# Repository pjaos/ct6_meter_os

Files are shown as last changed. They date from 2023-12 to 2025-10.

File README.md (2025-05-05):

# CT6 Meter Project
For this project I developed the hardware to allow the measurement of household AC electrical energy usage on up to 6 circuits using current transformers (CT’s). It can be used to monitor solar system generation, storage battery charge/discharge, EV charging, household energy usage, etc...

Multiple CT6 devices can be used to monitor more circuits if required.

Each CT6 unit has 6 ports, each of which can be connected to a current transformer, clipped around a cable carrying AC mains power. Each port can measure the AC power flow bi directionally (I.E to and from the grid). The unit measures the active power (the power normally charged by a domestic electricity supplier), reactive and apparent power. The AC power factor, frequency and AC voltage is also measured along with the WiFi RSSI and CT6 device temperature.

## The CT6 hardware.

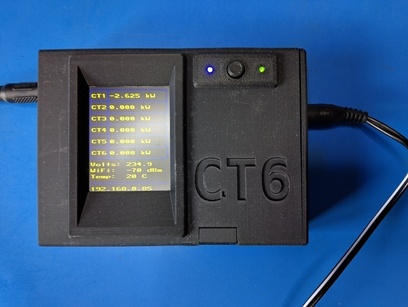
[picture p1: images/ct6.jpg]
CT6 Unit


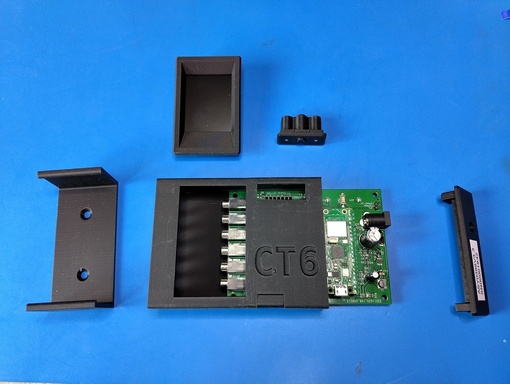
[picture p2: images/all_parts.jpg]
CT6 Parts


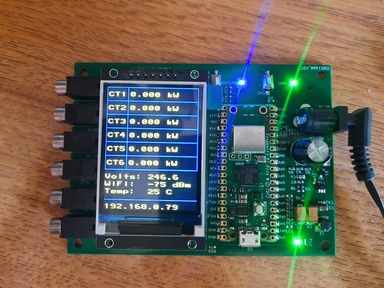
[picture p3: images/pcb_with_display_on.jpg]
CT6 PCB With Display Power On


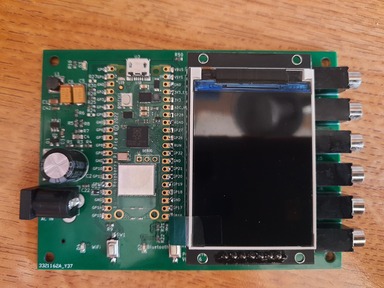
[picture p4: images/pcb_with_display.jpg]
CT6 PCB With Display Power Off


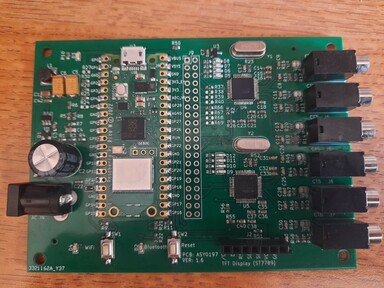
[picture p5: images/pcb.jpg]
CT6 PCB


### CT6 Hardware details
More details of the CT6 hardware can be found [here](hardware/README.md).

## Installing CT6 Software Applications
Details of how to install the CT6 software package onto a Windows or Linux machine can be found [here](software/server/installers/README.md).

## The CT6 Software Applications
An overview of the CT6 software applications are shown below. These can all be started from a terminal window on the command line by entering the name of each command.

- ct6_configurator

The ct6 configurator app allows the user to setup/configure a CT6 unit via a GUI interface. This includes connecting it to your WiFi, upgrading it to the latest firmware. Click [here](software/server/setting_up_ct6_units.md).

- ct6_app

When at least one CT6 device is connected to your WiFi network you can start this app (enter ct6_app in a terminal window). This app will find all CT6 units. These CT6 units will send data to the ct6_app which then stores it in an sqlite database. A server is then started and a browser window will open, connected to the server, to display the data from the database as shown.

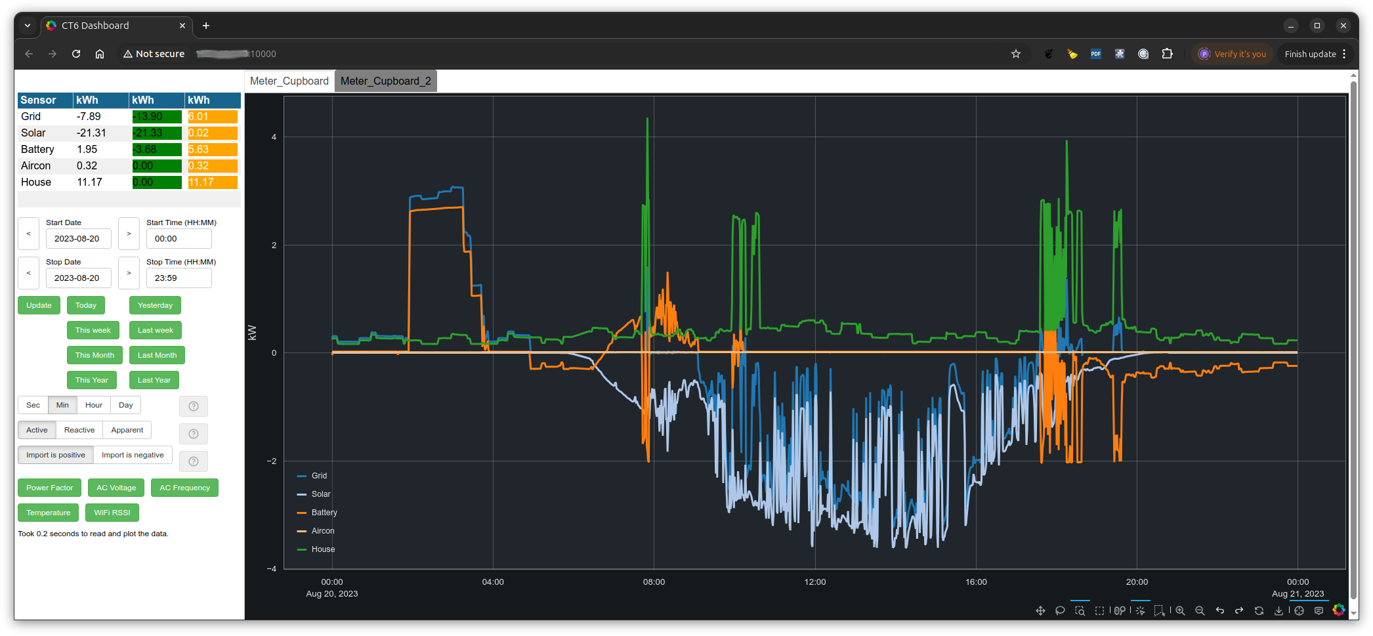
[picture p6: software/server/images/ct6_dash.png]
ct6_dash


- ct6_db_store

Similar to part of the ct6_app in that it detects all CT6 units on the LAN/WiFi and stores the data in a database. However the database is a mysql database. This allows for a more scalable system than the ct6_app. Details of how to use this app can be found [here](software/server/mode_1_mysql_db_and_dashboard.md).

- ct6_dash

This presents the data stored in the above mysql database and presents a GUI in a web browser as displayed above.  Details of how to use this app can be found [here](software/server/mode_1_mysql_db_and_dashboard.md).

- ct6_dash_mgr

Both the ct6_app and the ct6_dash app present a GUI in a browser interface via a local web server. This app allows you to configure credentials (username/password) to allow access to the web server. The ct6_app and ct6_dash apps must be configured to require a login in order to use these credentials. The example below shows auser being added for web server access.

```
ct6_dash_mgr
INFO:
INFO:  ------------
INFO:  | USERNAME |
INFO:  ------------
INFO:  0 credentials stored in /home/pja/.ct6_dash_credentials.json
INFO:
INFO:  A - Add a username/password.
INFO:  D - Delete a username/password.
INFO:  C - Check a username/password is stored.
INFO:  Q - Quit.
INPUT: Enter one of the above options: : a
INFO:  Add a username/password
INPUT: Enter the username: : auser
INPUT: Enter the password: : apassword
INFO:
INFO:  ------------
INFO:  | USERNAME |
INFO:  ------------
INFO:  |    auser |
INFO:  ------------
INFO:  1 credentials stored in /home/pja/.ct6_dash_credentials.json
INFO:
INFO:  A - Add a username/password.
INFO:  D - Delete a username/password.
INFO:  C - Check a username/password is stored.
INFO:  Q - Quit.
INPUT: Enter one of the above options: : q
```

- ct6_mfg_tool

This tool is used to load SW and perform manufacturing tests on CT6 hardware in order to commission them.

- ct6_stats

This finds CT6 devices on the LAN/WiFi and displays the JSON data received from CT6 devices.

- ct6_tool

This provides functionality that is useful when checking the operation of CT6 units in a development environment.

More details of how to use the installed software applications can be found [here](software/server/README.md).

# Home Assistant integration
Click [here](software/server/homeassistant_README.md) for details of how to use CT6 devices with homeassistant.

# Purchasing CT6 units
Complete CT6 units or assembled PCB's and associated parts can be purchased [here](https://www.tindie.com/products/pausten/ct6-energy-monitor/) on Tindie.

If you wish to purchase the PCB and assemble it the PCB is available [here](https://www.ebay.co.uk/itm/197238433051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) on ebay and the Bill of materials (BOM) is available [here](hardware/ct_meter_2.1_bom.csv).

# Warning
This project is designed to use the YHDC SCT013 100A 0-1V split core current transformer. As mains voltage is dangerous it is the users responsibility to connect these current clamps safely using this hardware.

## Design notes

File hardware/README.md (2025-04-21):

# CT6 Hardware

## Schematic

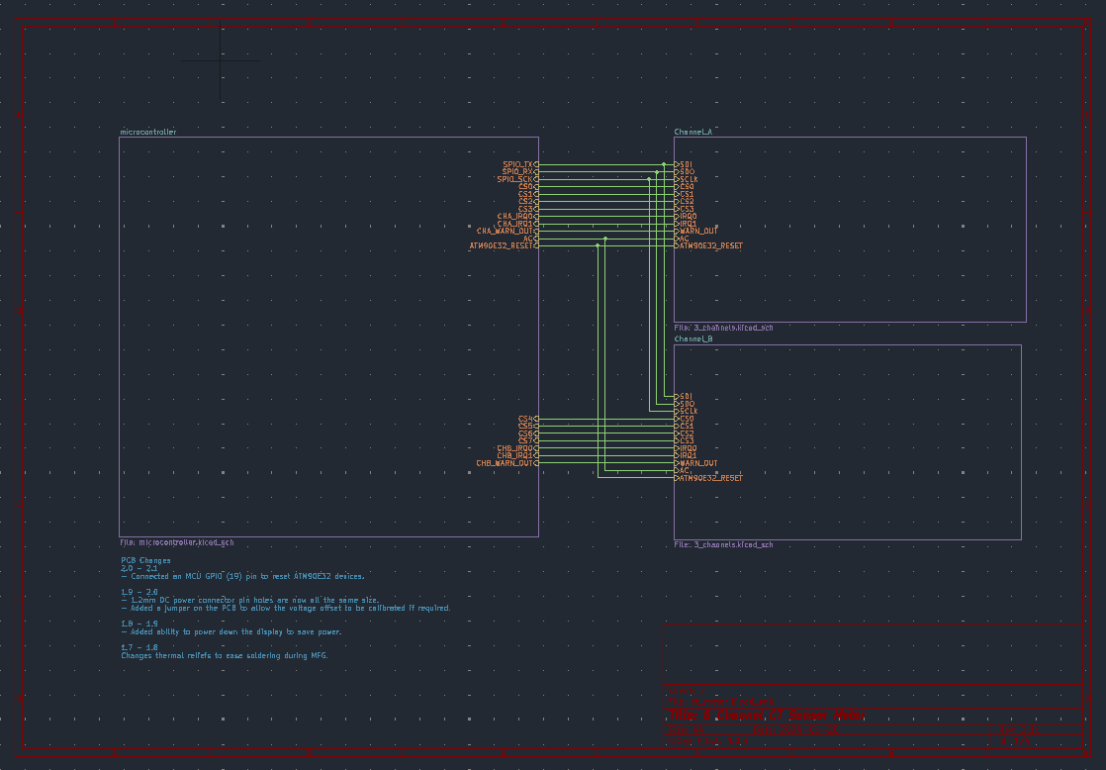
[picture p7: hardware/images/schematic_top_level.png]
CT6 Top Level Schematic


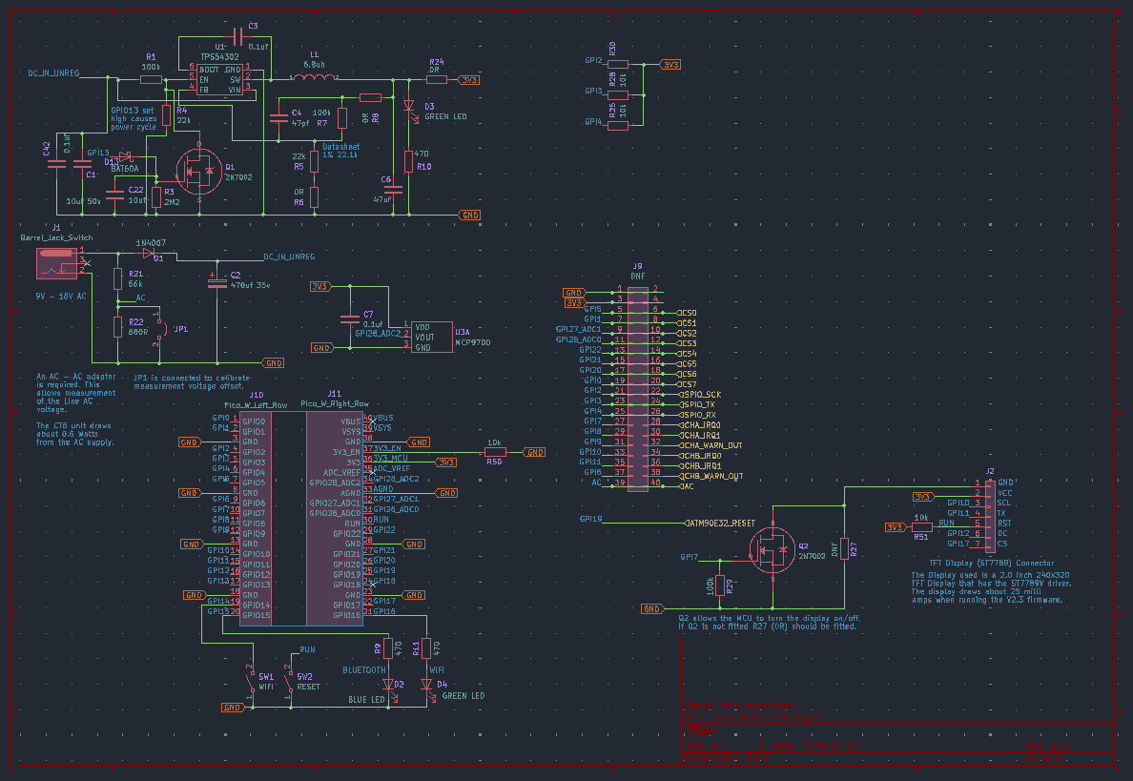
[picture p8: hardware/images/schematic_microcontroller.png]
CT6 Microcontroller Schematic


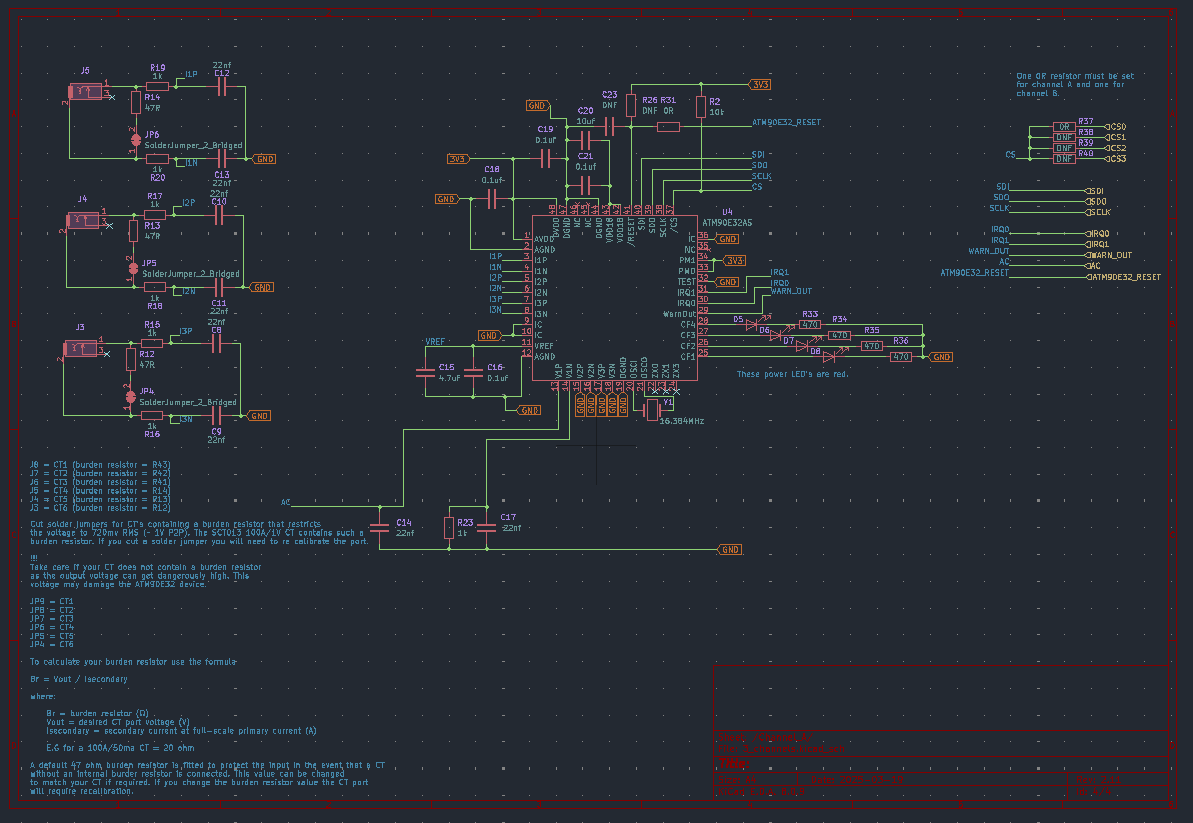
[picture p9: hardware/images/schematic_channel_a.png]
CT6 Channel A Schematic


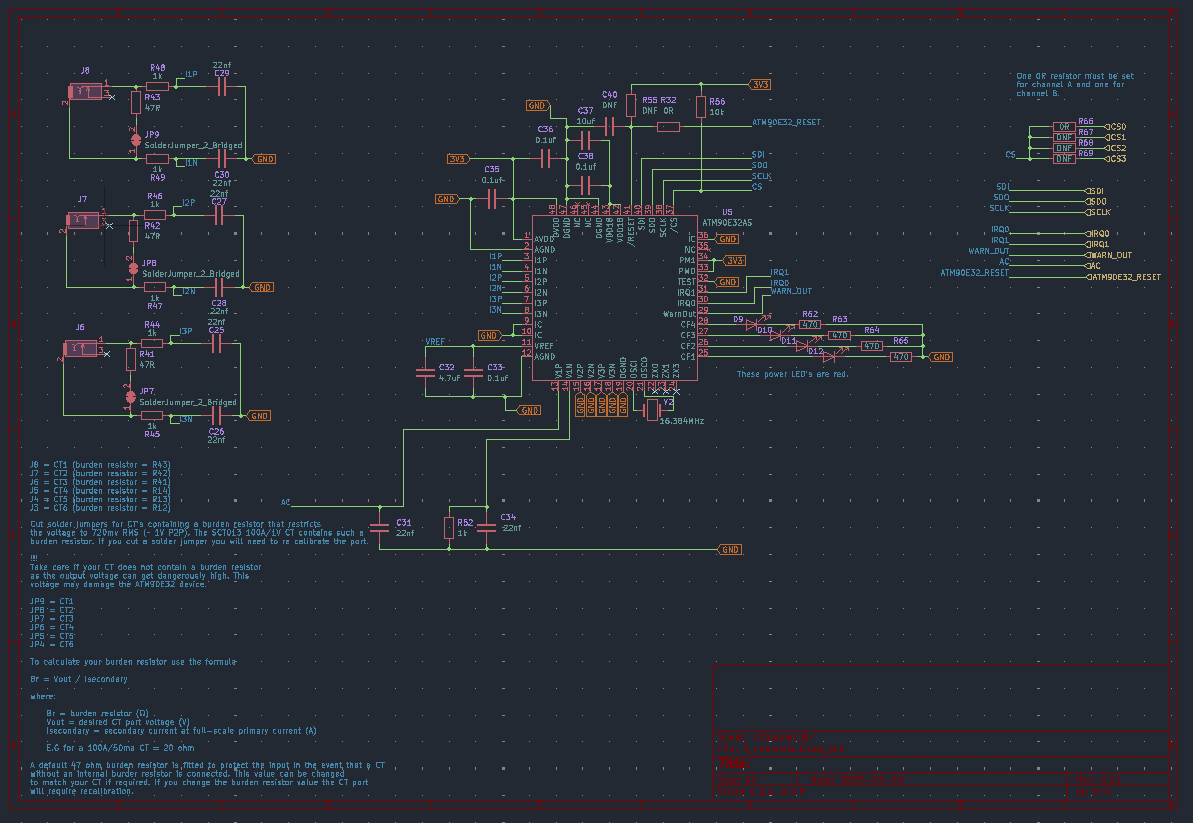
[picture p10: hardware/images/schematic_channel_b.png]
CT6 Channel B Schematic


## PCB
The PCB was created from the above schematic. The final PCB is shown
below.

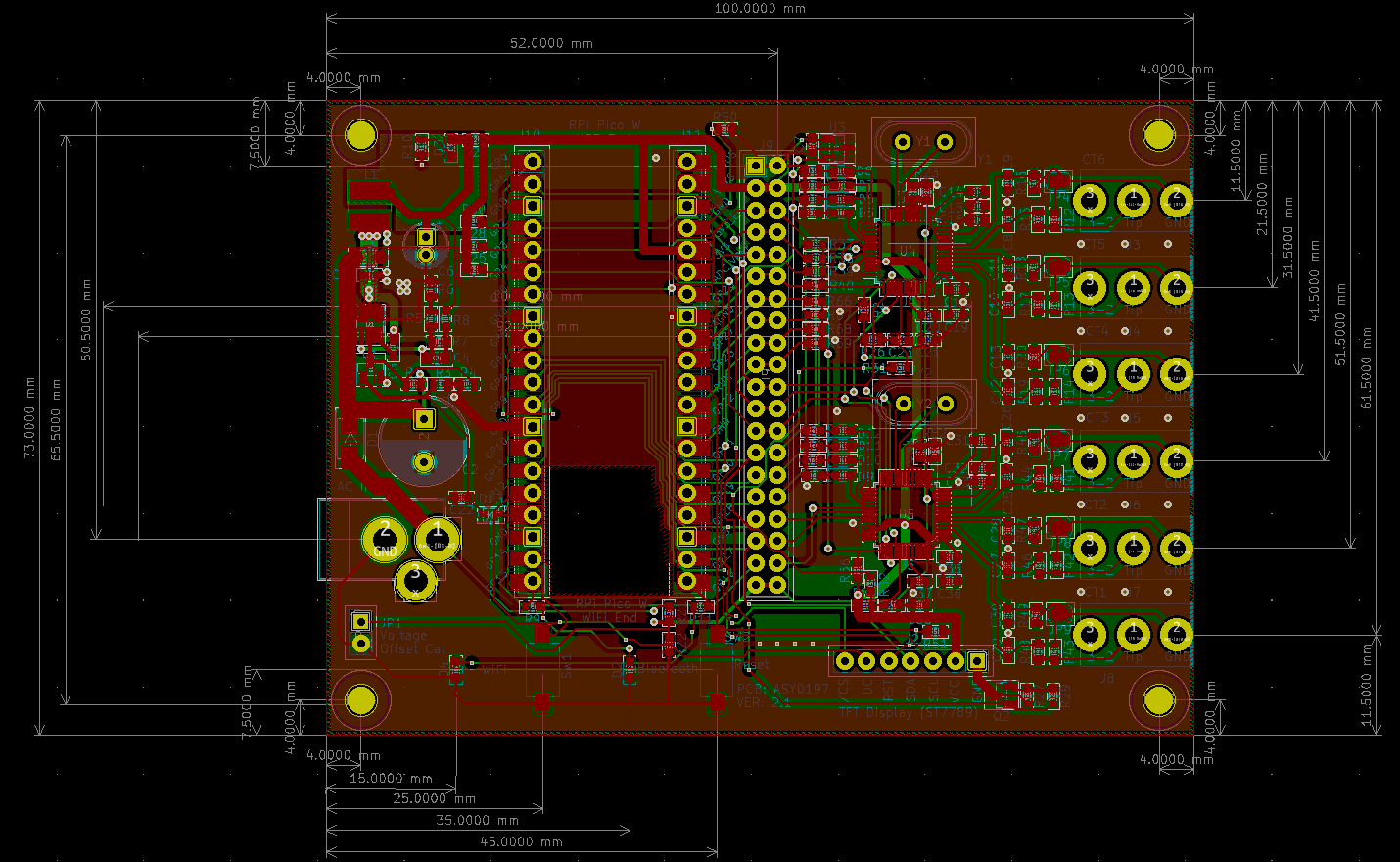
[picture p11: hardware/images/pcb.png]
CT6 PCB


## Bill Of Materials
The BOM for the above PCB is available [here](ct_meter_2.1_bom.csv "Bill Of Materials") in CSV format.

# Current transformer

This project is tested with the YHDC SCT013 100A 0-1V split core current transformer when manufactured. If you wish to use a different current transformer then you must calibrate the unit as detailed at the end of [this](../software/server/setting_up_ct6_units.md) document.

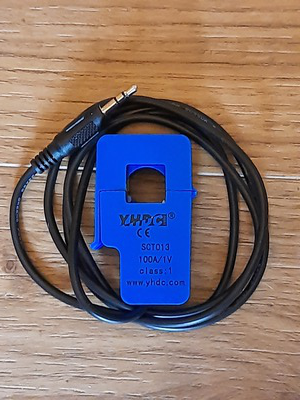
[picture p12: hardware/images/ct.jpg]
Current Transformer


These can be plugged into ports 1 - 6 to provide up to six separate bi directional measurements of AC power. When clipping the current transformer around the live AC wire it is recommended that the face shown above should be on the AC supply (grid) side. This results in -ve power values for imported energy and +ve power values for generated energy. If you wish to have +ve values for imported energy then reverse the current transformer. It should be possible to use other current transformers but they will need calibration as detailed above. The schematic now includes notes (channel a and channel b) that provides more details on this.

## Case
The Case was designed using [FreeCad](https://www.freecad.org/). The various
parts of the case are shown below.

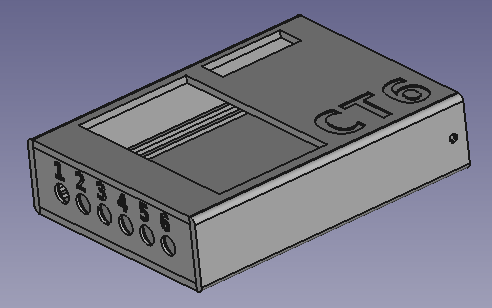
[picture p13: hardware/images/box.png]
CT6 Main Box


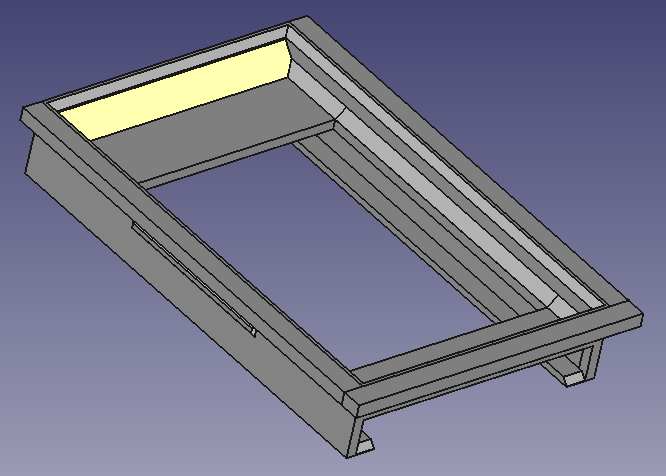
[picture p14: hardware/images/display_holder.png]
CT6 Display Holder


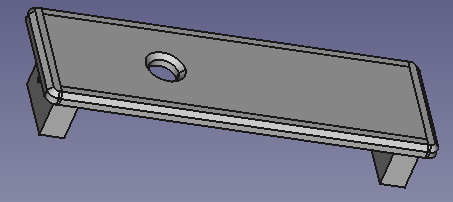
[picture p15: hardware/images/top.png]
CT6 End Cap


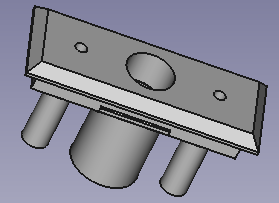
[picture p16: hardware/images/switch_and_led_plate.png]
CT6 Switch an LED light Pipe Plate


The two small holes in the above part are drilled using a 1.8mm drill bit. Then a length of clear PETG filament is inserted
into the hole. Each end is then cut off to create light pipes.

CT6 Button

The [case](case) folder contains the FreeCad (0.20.2) design files for this project.

### Dissembling a CT6 unit

Some info on how to take a CT6 unit apart if you want access to the PCB can be found here [here](hardware/README_DISSEMBLY.md)

## Power Supply
This project requires the use of an AC - AC supply. If you purchase a CT6 unit the CT6 PCB assembly will have been calibrated using the power supply detailed below.

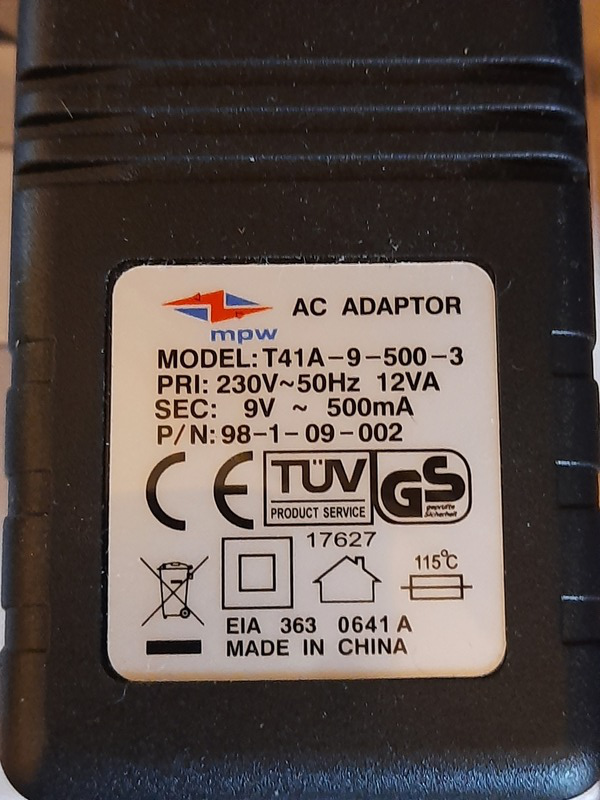
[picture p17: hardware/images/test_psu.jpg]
CT6 PSU


[AC - AC Power supply](https://www.ebay.co.uk/itm/235232679606)

Note !!!

The power supply must output an AC voltage between 9 and 16 volts with a 2.1 mm DC DC barrel connector. A DC power supply will not power the unit. A calibration process is required for the power supply fitted to the unit to ensure the voltage and power measurements are correct.

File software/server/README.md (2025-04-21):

# CT6 Applications
The CT6 hardware is responsible for measuring the bi directional power from
up to 6 CT sensors.

Before using the CT6 apps detailed below you must setup your CT6 device as detailed [here](setting_up_ct6_units.md).

- Mode 1
This is the normal operating mode.

  - The ct6_app will detect CT6 devices on the LAN, save the data to a database (sqlite) and present
    a GUI (via a web server) to allow you to view current and historical CT6 data. This is
    the easiest way to get up an running with a CT6 device.
    Once the CT6 device is connected to your WiFi network simply start the ct6_app and energy usage
    data is stored and can be viewed using a web browser on the same or another PC (tablet or phone) in your house.
    It is possible (using the -c command line option and ct6_dash_mgr tool) to configure the ct6_app tool so that
    credentials (username and password pairs) are required to log into the web interface if you wish to control access to this data.

   - Click [here](mode_1_mysql_db_and_dashboard.md) if you wish to have a more scalable system the ct6_db_store app will detect CT6 devices on the LAN, save the data to a mysql database and the ct6_dash app will display a similar interface to the ct6_app.

- Mode 2
   - Send data to an MQTT server to integrate with other systems. In this case the CT6 device must be configured to
     send data to an MQTT server. Details of how to configure a CT6 device can be
     found [here](setting_up_ct6_units.md). The ability to send data to an MQTT server
     allows integration with other systems (E.G [ioBroker](https://www.iobroker.net/)).

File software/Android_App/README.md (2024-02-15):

# Android application
This android application was developed to allow the user to program the  
WiFi interface on the device in order that it will register on a
WiFi (2.4 GHz) network.

It does this by communication with microcontroller on the unit
over bluetooth and guiding the user through the process of configuring the
WiFi as detailed below.

# Installing the Android App
To install the Android app on your Android device (phone or tablet) you need to
have Android Studio (https://developer.android.com/studio) installed on your PC.

Before being able to compile the SetupYDevWifi Android Studio project 
you need to add the local.properties file to the Android_App/SetupYDevWifi
folder. This tells AndroidStudio where to find the Android SDK.

E.G

```
## This file must *NOT* be checked into Version Control Systems,
# as it contains information specific to your local configuration.
#
# Location of the SDK. This is only used by Gradle.
# For customization when using a Version Control System, please read the
# header note.
#Thu Feb 15 05:53:03 GMT 2024
sdk.dir=/home/USERNAME/Android/Sdk
```

where USERNAME is your username. This is the local path where the Android SDK is installed.

Once this has been done you should be able to open the SetupYDevWifi project from the
Android_App folder. 

Connect your Android device (phone or tablet) via a USB cable to the PC running Android studio once you
have enabled USB debugging under developer options on your Android phone/tablet.

Once the above is complete, clicking the Run/Play button in the Android Studio toolbar will compile the app, deploy the app to your Android device and start it running. This will install the app on you android device. Therefore you will be able to launch it by selecting the 'WiFi Device Setup' icon.

# Using the App.
Start the app by selecting the ''WiFi Device Setup' icon as shown below on
your Android device.

Android App Icon

The following should then be displayed.

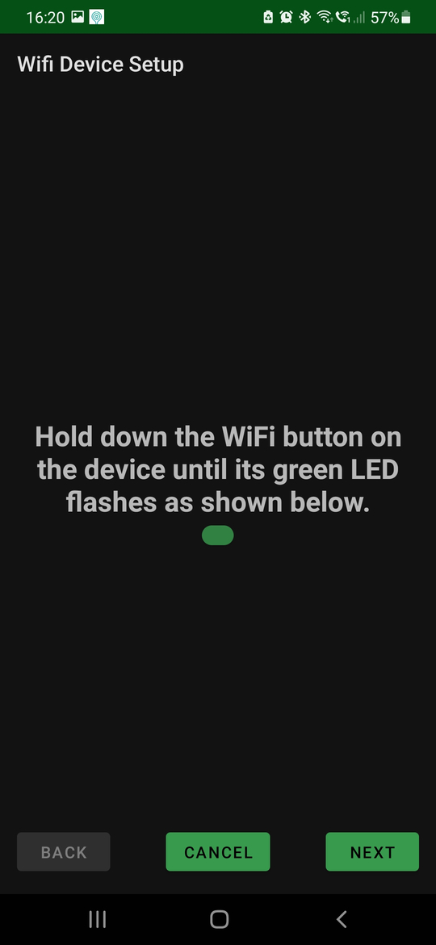
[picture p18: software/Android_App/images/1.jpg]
Step 1


At this point the button on the device should be held down until the blue and green LED's start flashing. Then select the Next button and the following should be displayed.

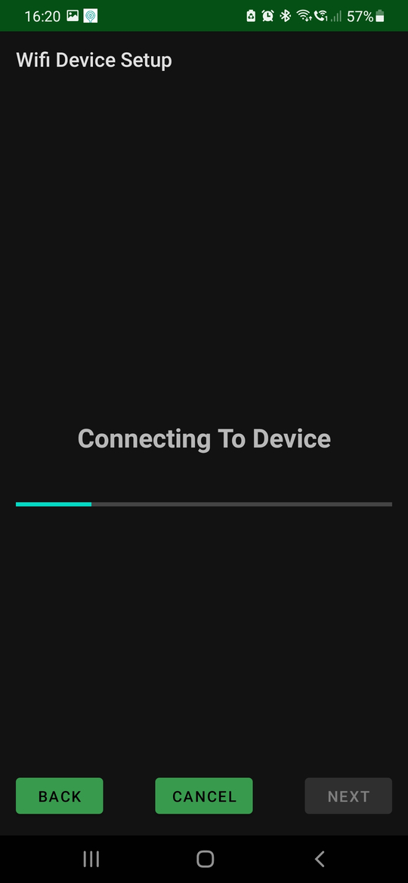
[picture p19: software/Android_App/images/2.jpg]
Step 2


After several (up to 60) seconds the blue LED on the device should turn on solid. This indicates that a blue tooth connection has been established with the device. The device will then scan for WiFi networks and display the ones it found as shown below. If the WiFi network that you wish to connect to is not listed then select the back button, followed by the Next button to re scan for WiFi networks until the WiFi network is displayed.

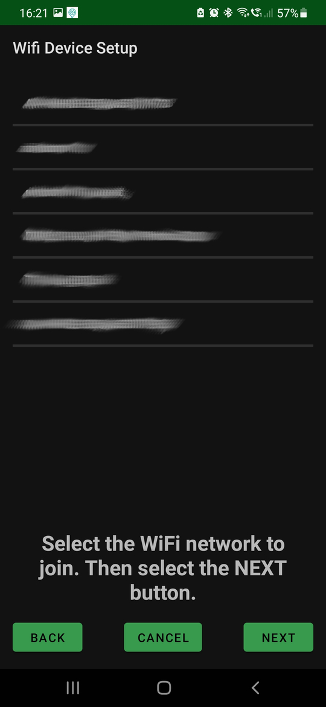
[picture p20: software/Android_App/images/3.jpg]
Step 3


The WiFi networks will then be displayed. Select the network that you wish to connect to as shown below.

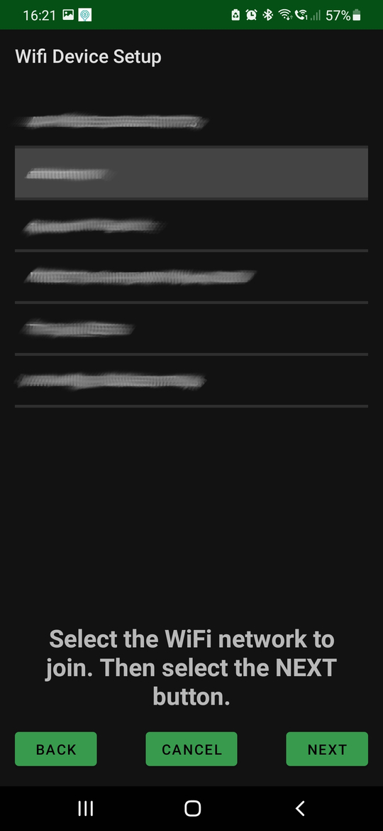
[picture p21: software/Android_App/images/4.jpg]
Step 4


Then select the Next button and the following will be displayed to allow the WiFi network password to be entered.

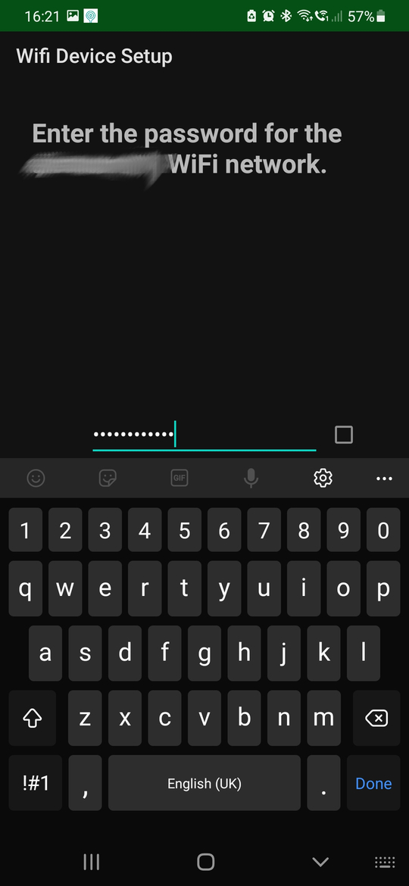
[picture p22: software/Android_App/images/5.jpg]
Step 5


The WiFi password entered will be shown as a line of dots as shown above.
If you wish to view the password you entered you may click the checkbox icon to the right of the password and the password will be displayed as shown below.

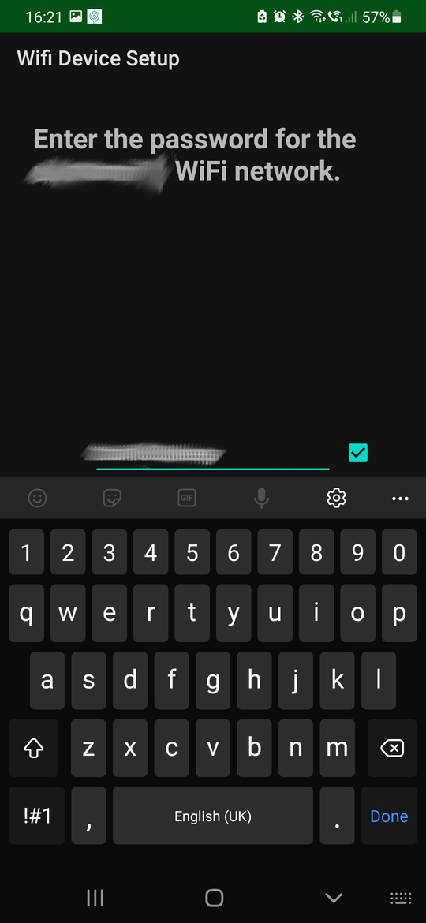
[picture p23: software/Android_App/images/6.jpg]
Step 6


When you are sure that you have entered the correct password select the Done key on the displayed keyboard. An attempt will then be made to connect the device to the WiFi network as shown below.

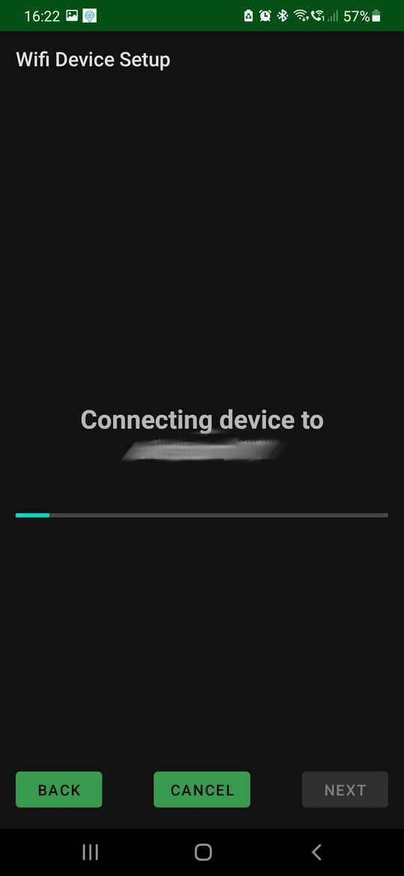
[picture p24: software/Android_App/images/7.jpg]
Step 7


When a successful connection has been made the following screen will be displayed.

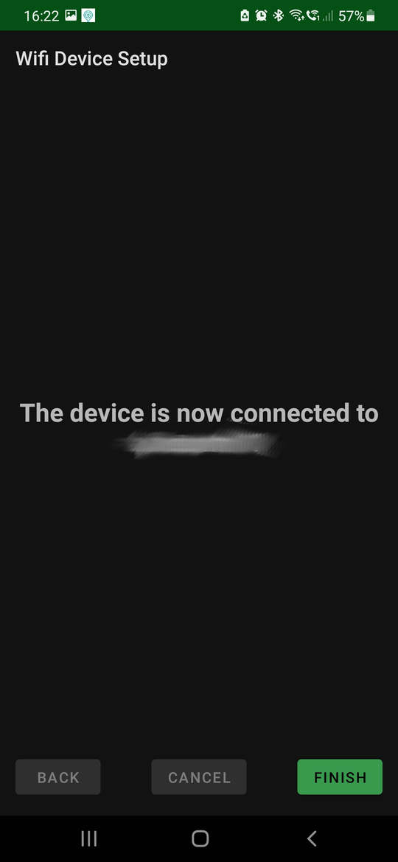
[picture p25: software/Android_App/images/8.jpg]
Step 8


At this point if the 'The device is now connected to' text is selected then the IP address that the unit has been given will be displayed as shown below.

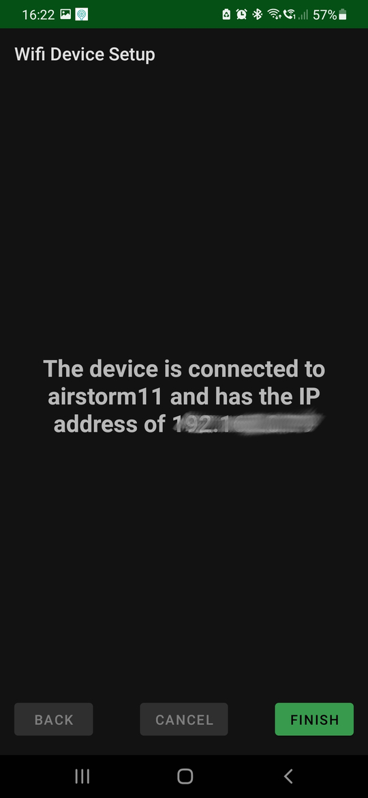
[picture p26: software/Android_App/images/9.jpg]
Step 9


At this point the WiFi interface is setup correctly and the Finish button may be selected to close the app.

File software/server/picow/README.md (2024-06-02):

# Micropython
The CT6 device runs a micropython app. The app1 folder contains
the all the CT6 device code including the libraries and hardware device drivers.

## Design

I decided to use the Raspberry Pi Pico W microcontroller. I also decided to use micropython as the operating system. On previous projects that used microcontrollers I have used [Mongose OS](https://mongoose-os.com/) which runs on top of [FreeRTOS](https://www.freertos.org/index.html) with the firmware written in C. I decided to use micropython as the speed/capability trade offs are changing with the continuing development of micropython and I wanted to see it's benefits/limitations on a real world project. Having completed the project I can say that micropython is more than capable for this type of project. I did compile the display SPI driver into the micropython firmware to speed up the display interface but other than that I was pleasantly surprised and plan to use it for other suitable projects in the future as the effort required to reach the development complete stage was considerably less using micropython than my previous approach.

The CT6 hardware was designed against the requirements detailed in the top level readme. This involved schematic design, PCB layout and PCB manufacture. The PCB was fabricated, assembled, tested and a 3D printed case was produced. This took several iterations before I was happy with the design. The [hardware](hardware) folder contains details of the schematic and also the design for the 3D printed case.

## Tools
The tools folder contains several development tools. Some of the tools also support ESP32 microcontrollers which would ease the process of changing the microcontroller if it should be needed in future. The ct6_tool.py and ct6_mfg_tool.py (in the software/server) contain functionality that is useful when developing the software and hardware. This includes over the air upgrade functionality. See the command line help on these tools for more information.

### picow_erase_flash.sh
Allows the user to erase the contents of the Pico W flash. To do this the button on the Pico W module should be held
down while powering it up with the serial port connected to a Linux PC. The PC should then mount the pico W
flash (typically under the /media folder). Note this folder name.

To erase the flash. The 'username' shown below will typically be your Linux username.

```
./picow_erase_flash.sh /media/username/RPI-RP2/
```

Once complete the folder will be unmounted from the Linux machine.

### picow_micropython_flash.sh
This script can be used to program load micropython onto the Pico W. To do this the button on the Pico W module should be held down while powering it up with the serial port connected to a Linux PC as in the previous step. The PC should then mount the flash as previously.

To load micropython onto the Pico W flash the following command can be used with the username changed to your username.

```
./picow_micropython_flash.sh /media/username/RPI-RP2/
```

Once complete the folder will be unmounted.

To check that micropython is loaded onto the Pico W connect to the serial port. In this example I use the microcom program but any terminal emulation program will do the trick. To return the micropython version press CTRL B.

```
microcom -p /dev/ttyACM0 -s 115200
connected to /dev/ttyACM0
Escape character: Ctrl-\
Type the escape character to get to the prompt.

>>>
MicroPython v1.20.0-326-gcfcce4b53 on 2023-07-25; Raspberry Pi Pico W with RP2040
Type "help()" for more information.
>>>
```

To exit microcom press 'CTRL \\' twice.

### picow_start_rshell.sh
A helper script to access the microcontroller flash contents. The script
requires one argument that is the serial port to which the Pico W microcontroller is connected. The rshell python module is required to use this script.

To use the tool the following command can be used assuming the Pico W is
connected to /dev/ttyACM0.

```
./esp32_start_rshell.sh /dev/ttyACM0
```

### ESP32 support scripts
The esp32_erase_flash.sh and esp32_start_rshell.sh scripts are for future use should ESP32 microcontroller support be added to the CT6 project.

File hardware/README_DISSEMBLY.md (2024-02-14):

# Disassembling a CT6 unit.

The CT6 unit case is 3d printed and it's parts snap together. In order to take it apart it is useful to have a plastic tool that is used to take apart mobile phones. This tool is shown below.

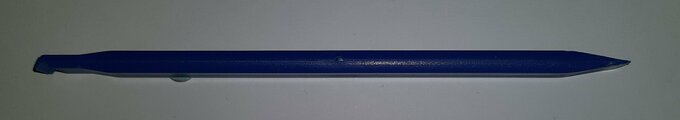
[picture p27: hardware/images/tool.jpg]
CT6 disassembly tool


To disassemble a CT6 unit you should follow the following sequence of steps.

To remove the LED and button panel use the tool as shown below.

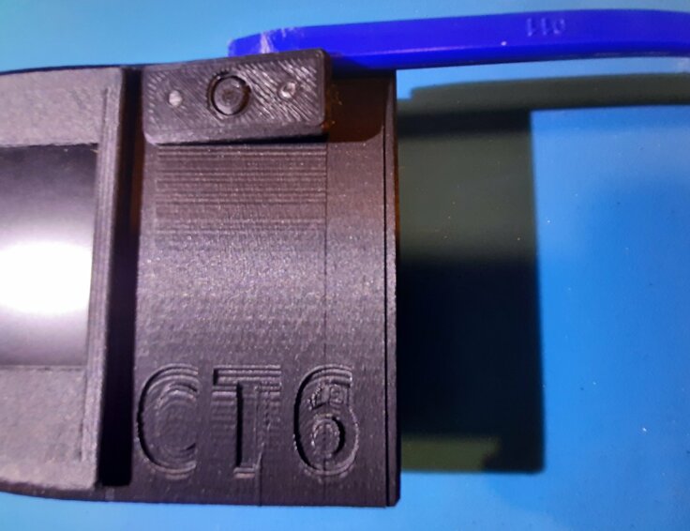
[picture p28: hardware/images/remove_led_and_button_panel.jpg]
CT6 LED and button panel removal.


To remove the display use the tool as shown below.

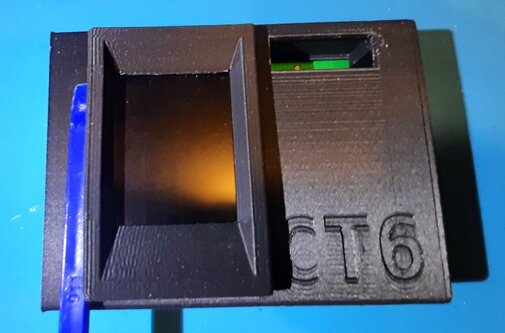
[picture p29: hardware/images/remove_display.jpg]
CT6 display removal.


Note ! When assembling a CT6 unit ensure the display is pushed home square to ensure the display connector is in the correct position inside the box.

To remove the box end cap use the tool as shown below.

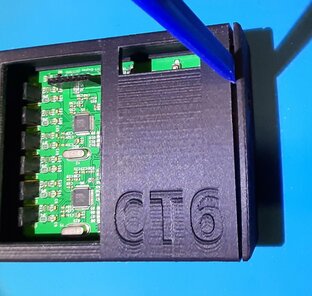
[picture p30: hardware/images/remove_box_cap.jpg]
CT6 box cap removal.


A dissembled CT6 unit is shown below.

Dissembled CT6 unit.

An assembled CT6 unit is shown below.

Assembled CT6 unit.

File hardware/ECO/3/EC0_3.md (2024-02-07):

# Issue
Most Pico W boards would work ok when connected to the CT6 hardware.
However some Pico W units would restart occasionally without warning.

It was found that the current drawn by Pico W units can vary by a factor
of up to 4. When high current units were installed the ripple voltage
across C2 could get large enough to disrupt the 3V3 rail causing it to
drop to ~ 1.5v. Therefore this ECO increases C2 from 220uf to 470uf
which means the C2 ripple voltage reaches a max of 4v which is within
margin when the AC supply used is 9V (the lowest supported).

The voltage of C2 has been reduced from 50v to 35v as this allows
the same size capacitor to be used as C2 can be no high than 16mm
to fit in the case.

# ASSY
Move the top level assembly to version 3.2.

# Workaround
Use a Pico W that draws a lower current. This is not very useful in most
situations, therefore it is recommended that this ECO is applied.

# Modification
Remove C2 (220uf 50v) and fit a 470uf 35v capacitor.

# Status
Applied

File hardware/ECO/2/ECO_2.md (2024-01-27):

# Issue
If the /power_cycle REST interface command is used the CT6 board does not
always measure power on the CT ports when it comes back up. The
/power_cycle command causes the 3V3 rail to be turned off on the CT6
unit. The problem is that this rail does not drop for long enough to
allow the CT6 board to power cycle correctly. The change detailed here
extends the holdoff time to ~ 5 seconds which stops this symptom occuring.

# ASSY
This ECO can be applied to ASSY0398 CT6 (top level assy) versions 1.9.
When the change is applied the board label should become V3.1. Bumped from 
v1.9 to v3.1 so that top level assy version is not confused with the PCB
version.

# Workaround
If the /power_cycle command is used and the CT6 unit stops measuring AC power
the user must pull the AC power connector from the CT6 unit, wait at least
5 seconds before reconnecting the AC power.

# Modification
To resolve this the capacitor and resistor that determine the power cycle
hold off period are changed as detailed below.

1 - Remove C22 (1uf) and replace with a 10uf capacitor.
2 - Remove R1 (1M) and replace with a 2.2M resistor.

# Status
Applied

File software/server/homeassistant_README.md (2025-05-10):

# Using CT6 device with Home Assistant.
One or more CT6 devices can be integrated with homeassistant as detailed below.

## Examples of CT6 Home Assistant Integration.

Energy Flow Diagram

Battery Charge Power

Solar Power

## Home Assistant Setup

Before attempting to setup home assistant ensure docker and docker-compose are installed. See https://docs.docker.com for more information on docker installation and https://docs.docker.com/compose/install/linux/ on docker-compose installation.

Create a homeassistant folder to hold all your home assistant configuration files. For this example the homeassistant folder sits in the users home dir but it can be in any writeable location.

```
cd ~
mkdir homeassistant
cd homeassistant
```

- 🛠️ Step 1: Create docker-compose.yml

In your project directory (e.g., home-assistant), create this docker-compose.yml:

```
version: '3.9'

services:
  homeassistant:
    container_name: homeassistant
    image: ghcr.io/home-assistant/home-assistant:stable
    volumes:
      - ./config:/config
      - /etc/localtime:/etc/localtime:ro
    restart: unless-stopped
    network_mode: host
    privileged: true

  mqtt:
    container_name: mqtt
    image: eclipse-mosquitto
    ports:
      - "1883:1883"
      - "10001:10001"
    volumes:
      - ./mosquitto/config:/mosquitto/config
      - ./mosquitto/data:/mosquitto/data
      - ./mosquitto/log:/mosquitto/log
    restart: unless-stopped
```

🛠️ Step 2: Add Mosquitto Config

Create ./mosquitto/config/mosquitto.conf with minimal setup in the homeassistant folder.

```
persistence true
persistence_location /mosquitto/data/
log_dest file /mosquitto/log/mosquitto.log

listener 1883
allow_anonymous true
```

🛠️ Step 3: Start Home Assistant and the MQTT Server.

```
docker-compose up -d
Creating network "home-assistant_default" with the default driver
Creating homeassistant ... done
Creating mqtt          ... done
```

If at any time you wish to stop the home assistant docker container.

```
docker-compose down
```

- Using ct6_configurator

Go to the MQTT Server tab and enter
CT6 address:            The IP address of the CT6 device on your LAN. This is
                        shown on the CT6 display.
MQTT Server Address:    The address of the machine running the home assistant with
                        the mosquitto MQTT server.
MQTT Server Port:       This can be left at the default of 1883.
MQTT Topic:             Enter the MQTT Topic that best describes the CT6
                        device (E.G  Meter Cupboard A).

Hit the set button and the CT6 device will start sending data to the MQTT server.

🛠️ Step 4: Check CT6 MQTT messages are received by the MQTT server.

 - To check that the MQTT server is receiving the CT6 messages MQTT Explorer can be used.
    See https://mqtt-explorer.com/ fr details of the installation.

 - Open MQTT Explorer
   Here we assume that home assistant/MQTT server is running on the same machine as MQTT explorer.

   - Select the + button to add a connection.
   - Enter a name for the connection (E.G localhost).
   - Enter the Host as 127.0.0.1
   - Select the save button to save this connection.
   - Select the Connect button.

   MQTT Explorer should start displaying the data received from the CT6 device as JSON text.

## Setup Running Home Assistant

- Connect to localhost:8123 using a web browser
- Click on the 'CREATE MY SMART HOME' button.

✅ Initial Home Assistant Setup Steps

    Click: Create My Smart Home

    Create a User Account

        Choose a username, name, and password.

        This account will be your administrator for Home Assistant.

    Set Your Location and Preferences

        Location: Used for sunrise/sunset automation and weather.

        Timezone, unit system (metric/imperial), and currency.

    Auto-Discovery of Devices

        Home Assistant will scan your network for smart devices (e.g. Shelly, TP-Link, Sonoff, Hue, etc.).

        You can choose to set them up now or skip and do it later.

    Home Assistant Is Ready

        You’ll land on the Overview dashboard.

        From there, go to Settings > Devices & Services to add MQTT and other integrations.

## Add MQTT server to home assistant

- Settings > Devices & services > + ADD INTEGRATION button
- Search for MQTT, select just MQTT
 - Enter the hostname or IP address of the MQTT server
   Optionally enter a username and password that clients will need to connect to the server. I left these blank.
 - Select the Submit button.
 - MQTT should now appear in the Configured devices.

## Add CT6 measurement ports

For this example

The CT6 device Meter_Cupboard (MQTT Topic name) has the following CT ports connected

CT6 Port 1 = Grid
CT6 Port 2 = Solar
CT6 Port 3 = Battery
CT6 Port 5 = House

- In Settings > Devices & services select MQTT
- Select the three dots on the right
- Select + Add MQTT Device
 - Enter the name (E.G Grid), leave other fields blank, select Next
 - Change Type of entity from Notifications to Sensor, leave other fields blank, select Next
 - Set Device class to Power, Set the State class to Measurement, Set the Unit of measurement to W, leave advanced settings untouched, select Next
- Enter State topic = Meter_Cupboard, Value Template = {{ value_json.CT1.PRMS | round(2) }}, leave advanced settings untouched, select Next

- In Settings > Devices & services select MQTT
- Select the three dots on the right
- Select + Add MQTT Device
 - Enter the name (E.G Solar), leave other fields blank, select Next
 - Change Type of entity from Notifications to Sensor, leave other fields blank, select Next
 - Set Device class to Power, Set the State class to Measurement, Set the Unit of measurement to W, leave advanced settings untouched, select Next
- Enter State topic = Meter_Cupboard, Value Template = {{ value_json.CT2.PRMS | round(2) }}, leave advanced settings untouched, select Next

- In Settings > Devices & services select MQTT
- Select the three dots on the right
- Select + Add MQTT Device
 - Enter the name (E.G Battery), leave other fields blank, select Next
 - Change Type of entity from Notifications to Sensor, leave other fields blank, select Next
 - Set Device class to Power, Set the State class to Measurement, Set the Unit of measurement to W, leave advanced settings untouched, select Next
- Enter State topic = Meter_Cupboard, Value Template = {{ value_json.CT3.PRMS | round(2) }}, leave advanced settings untouched, select Next

- In Settings > Devices & services select MQTT
- Select the three dots on the right
- Select + Add MQTT Device
 - Enter the name (E.G House CT), leave other fields blank, select Next
 - Change Type of entity from Notifications to Sensor, leave other fields blank, select Next
 - Set Device class to Power, Set the State class to Measurement, Set the Unit of measurement to W, leave advanced settings untouched, select Next
- Enter State topic = Meter_Cupboard, Value Template = {{ value_json.CT5.PRMS | round(2) }}, leave advanced settings untouched, select Next

An also for this example

The CT6 device Meter_Cupboard_2 (MQTT Topic name) has the following CT ports connected

CT6 Port 2 = EV Charger

- In Settings > Devices & services select MQTT
- Select the three dots on the right
- Select + Add MQTT Device
 - Enter the name (E.G EV CT), leave other fields blank, select Next
 - Change Type of entity from Notifications to Sensor, leave other fields blank, select Next
 - Set Device class to Power, Set the State class to Measurement, Set the Unit of measurement to W, leave advanced settings untouched, select Next
- Enter State topic = Meter_Cupboard_2, Value Template = {{ value_json.CT2.PRMS | round(2) }}, leave advanced settings untouched, select Next

Add the following to the end of the config/configuration.yaml file.

```
template:
  - sensor:
      - name: "Grid Import Power"
        unit_of_measurement: "W"
        device_class: power
        state_class: measurement
        state: >
          {% set p = states('sensor.grid_power') | float(0) %}
          {{ (p | abs) if p < 0 else 0 }}

      - name: "Grid Export Power"
        unit_of_measurement: "W"
        device_class: power
        state_class: measurement
        state: >
          {% set p = states('sensor.grid_power') | float(0) %}
          {{ (p | abs) if p > 0 else 0 }}

      - name: "Battery Charge Power"
        unit_of_measurement: "W"
        device_class: power
        state_class: measurement
        state: >
          {% set p = states('sensor.battery_power') | float(0) %}
          {{ (p | abs) if p < 0 else 0 }}

      - name: "Battery Discharge Power"
        unit_of_measurement: "W"
        device_class: power
        state_class: measurement
        state: >
          {% set p = states('sensor.battery_power') | float(0) %}
          {{ (p | abs) if p > 0 else 0 }}

      - name: "House Power"
        unit_of_measurement: "W"
        device_class: power
        state_class: measurement
        state: >
          {{ states('sensor.house_ct_power') | float(0) | abs }}

      - name: "EV Power"
        unit_of_measurement: "W"
        device_class: power
        state_class: measurement
        state: >
          {{ states('sensor.ev_ct_power') | float(0) | abs }}

      - name: "EV Energy Metered"
        unit_of_measurement: "kWh"
        device_class: energy
        state_class: total_increasing
        state: "{{ states('sensor.ev_energy') | float(0) | abs }}"

sensor:
  - platform: integration
    source: sensor.grid_import_power
    name: "Grid Energy Import"
    unit_prefix: k
    round: 3
    method: trapezoidal

  - platform: integration
    source: sensor.grid_export_power
    name: "Grid Energy Export"
    unit_prefix: k
    round: 3
    method: trapezoidal

  - platform: integration
    source: sensor.solar_power
    name: "Solar Energy"
    unit_prefix: k
    round: 3
    method: trapezoidal

  - platform: integration
    source: sensor.battery_charge_power
    name: "Battery Charge Energy"
    unit_prefix: k
    round: 3
    method: trapezoidal

  - platform: integration
    source: sensor.battery_discharge_power
    name: "Battery Discharge Energy"
    unit_prefix: k
    round: 3
    method: trapezoidal

  - platform: integration
    source: sensor.house_power
    name: "House Energy"
    unit_prefix: k
    round: 3
    method: trapezoidal

  - platform: integration
    source: sensor.ev_power
    name: "EV Energy"
    unit_prefix: k
    round: 3
    method: trapezoidal
```

- Restart the homeassistant docker container.

```
docker restart homeassistant
```

- Check in Developer Tools > States that the following are all showing the expected numbers.

sensor.grid_energy_import
sensor.grid_energy_export
sensor.solar_energy
sensor.battery_charge_energy
sensor.battery_discharge_energy
sensor.house_energy

✅ Set up the Energy Dashboard

    Go to:
    Settings > Dashboards > Energy

    Grid Consumption

        Energy consumed from the grid: select sensor.grid_energy_import

        Energy returned to the grid: select sensor.grid_energy_export

    Solar Production (optional)

        If you have a solar energy sensor: add sensor.solar_energy

    Battery (optional)

        Battery charge sensor: the energy going into the battery

        Battery discharge sensor: energy coming out of the battery

    Individual devices (House)

        Scroll to "Individual devices"

        Add sensor.house_energy to see what your house is using overall

    Individual devices (Electric vehicle).

    Add sensor.ev_energy_metered to see the ev charge power

    Save and wait
    The Energy Dashboard updates hourly, so you might not see data immediately.

### View Home Assistant logs

If at any time you need to view the home assistant logs

```
docker logs homeassistant
```

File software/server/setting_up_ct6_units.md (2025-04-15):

# Setting Up CT6 devices
The ct6_configurator program allows you to setup your CT6 unit. Once the software has
been installed the ct6_configurator software can be started as detailed below.

- Linux system
Enter 'ct6_configurator' in a terminal window.

- Windows System
The 'CT6 Configurator' App can be started from the windows Start button.

This command starts a local web server and then starts you systems web browser
connected to this web server. The following browser window is displayed initially.

CT6 Configurator Initial Window

## WiFi Configuration

The first thing you need to do with a CT6 device is connect it to
your WiFi network. The WiFi tab is the first tab an is selected by default when the
web browser starts.

You may configure the WiFi ssid and password either over a Bluetooth or a USB connection as detailed below.

### Bluetooth WiFi Configuration
To configure the CT6 WiFi over a bluetooth connection the computer running the
ct6_configurator software must have it's bluetooth interface enabled.

If the Bluetooth radio button is selected when you select the 'Setup WiFi' button you will
be prompted as shown below.

CT6 Configurator WiFi Setup Via Bluetooth 1
CT6 Configurator WiFi Setup Via Bluetooth 2
CT6 Configurator WiFi Setup Via Bluetooth 3

The CT6 device should then show it's IP address at the bottom of the display as shown
below.

 CT6 device connected to WiFi

### USB WiFi Configuration
If the USB radio button is selected when you select the 'Setup WiFi' button you will
be prompted to connect a USB cable to the CT6 device.

The USB interface of the RPi Pico W device inside the CT6 can be accessed by removing
the small panel on the lower edge of the unit that covers the USB port.

CT6 Parts

The following shows configuration of the WiFi over a USB interface.

CT6 Configurator WiFi Setup Via USB 1
CT6 Configurator WiFi Setup Via USB 2
CT6 Configurator WiFi Setup Via USB 2

 CT6 device connected to WiFi

## Upgrade the CT6 firmware.

 After the WiFi has been setup you should upgrade the CT6 devices firmware to the latest version using
 the Upgrade tab. The CT6 firmware will be upgraded over your WiFi network. To do this select the
 Upgrade tab, ensure the IP address is the same IP address that is displayed on the display of the
 CT6 device and then select the 'Upgrade CT6 Device' button. The upgrade will take a minute or two
 to complete and when complete the window will look similar to that shown below.

 CT6 Configurator Upgrade Complete

## Set CT6 Device Name
 Once you have upgraded the CT6 unit you must set the name of the CT6 unit. This is used as it's name in the the databases and in the GUI when viewing energy usage data. Therefore give some thought to the name
 you wish to set. You may have multiple CT6 devices and therefore you should give your CT6 device a name to
 identify it. The 'Device Name' tab allows you to do this. Select the 'Device Name' tab, check the
 IP address is correct and then enter a name for the device. The name should not have and space or
 tab characters and if they are entered they will be changed to underscore characters.

 Select the 'Set' button to save the device name to the CT6 device. Select the 'Get' button to
 read the device name from the CT6 device.

 CT6 Configurator Device Name

## Set CT6 Port Names
 Your should then set the port names. Typically these should be set to the device which that port is used to monitor. E.G Solar, EV, Air Source Heat Pump, Hot water Heater, etc. The name should not have and space or tab characters.

 Each port on the CT6 device can be given a name using the 'Port Names' tab. To set the port names
 check that the IP address is correct, enter the name for each port and select the 'Set' button.
 If the 'Get' button is selected the names of each port are read from the CT6 device.

 CT6 Configurator Port Names

## Set MQTT server configuration.
 If you are using your CT6 unit to send data to an MQTT server to integrate with other
 systems (E.G [ioBroker](https://www.iobroker.net/)) you may optionally set the MQTT server details here.

 If you wish to send power usage data to an MQTT server then the MQTT Server Address, MQTT Server Port (default 1883) and MQTT Topic must be entered. The MQTT Username and MQTT Password are optional. The TX Period (Milliseconds) defines how often the CT6 device will send data to an MQTT server. It is not recommended to set this value less than 1000 millseconds.

 The 'Set' button sets the MQTT Server parameters and the 'Get' button reads the parameters from
 the CT6 device.

 CT6 Configurator MQTT Server

 The data sent to the MQTT server is in JSON format. Below is an example of the data that MQTT
 subscribers will receive. In this case the configured MQTT topic is 'CT6'.

```
{
  "CT2": {
    "NAME": 2.0,
    "PRMS": 0.0,
    "IPEAK": 0.0,
    "IRMS": 0.0,
    "TEMP": 0.0,
    "PAPPARENT": 0.0,
    "PF": 0.0,
    "PREACT": 0.0,
    "TYPE": "SCT013_100A",
    "FREQ": 0.0,
    "VRMS": 0.0
  },
  "PF_WATTS_THRESHOLD": 5,
  "CT3": {
    "NAME": 3.0,
    "PRMS": 0.0,
    "IPEAK": 0.0,
    "IRMS": 0.0,
    "TEMP": 0.0,
    "PAPPARENT": 0.0,
    "PF": 0.0,
    "PREACT": 0.0,
    "TYPE": "SCT013_100A",
    "FREQ": 0.0,
    "VRMS": 0.0
  },
  "CT1": {
    "NAME": 1.0,
    "PRMS": 0.0,
    "IPEAK": 0.0,
    "IRMS": 0.0,
    "TEMP": 0.0,
    "PAPPARENT": 0.0,
    "PF": 0.0,
    "PREACT": 0.0,
    "TYPE": "SCT013_100A",
    "FREQ": 0.0,
    "VRMS": 0.0
  },
  "DEVICE_TYPE": "6_CHNL_CT_SENSOR",
  "OS": "micropython",
  "CT6": {
    "NAME": 6.0,
    "PRMS": 0.0,
    "IPEAK": 0.0,
    "IRMS": 0.0,
    "TEMP": 0.0,
    "PAPPARENT": 0.0,
    "PF": 0.0,
    "PREACT": 0.0,
    "TYPE": "SCT013_100A",
    "FREQ": 0.0,
    "VRMS": 0.0
  },
  "CT5": {
    "NAME": 5.0,
    "PRMS": 0.0,
    "IPEAK": 0.0,
    "IRMS": 0.0,
    "TEMP": 0.0,
    "PAPPARENT": 0.0,
    "PF": 0.0,
    "PREACT": 0.0,
    "TYPE": "SCT013_100A",
    "FREQ": 0.0,
    "VRMS": 0.0
  },
  "PRODUCT_ID": "CT6",
  "BOARD_TEMPERATURE": 15.94435,
  "RSSI": -39.18182,
  "FIRMWARE_VERSION": "3.0",
  "SERVICE_LIST": "WEB:80",
  "UNIT_NAME": "offlineCT6",
  "CT4": {
    "NAME": 4.0,
    "PRMS": 0.0,
    "IPEAK": 0.0,
    "IRMS": 0.0,
    "TEMP": 0.0,
    "PAPPARENT": 0.0,
    "PF": 0.0,
    "PREACT": 0.0,
    "TYPE": "SCT013_100A",
    "FREQ": 0.0,
    "VRMS": 0.0
  },
  "TIMESENT": [
    2025,
    4,
    15,
    16,
    7,
    51,
    1,
    105,
    1744733271
  ],
  "ACTIVE": 1.0,
  "YDEV_UNIT_NAME": "offlineCT6",
  "GROUP_NAME": "",
  "IP_ADDRESS": "172.16.13.17",
  "ASSY": "ASY0398_V003.300_SN00001846",
  "READ_TIME_NS": 29564.67,
  "RX_TIME_SECS": 1744733271.3176482
}
```

 If you do not wish to send data to an MQTT server then the MQTT Server Address field should be empty.

## Activating a CT6 device
 A CT6 device will not send stats data until it is activated.

 A CT6 device may send data to the ct6_app or ct6_db_store apps. Both of these apps send out broadcast messages so that all CT6 devices on the LAN/WiFi send data back to them.

 If an MQTT server is configured then messages are sent from the CT6 device/s at the configured periodicity.

 The 'Activate Device' tab allows you to set a CT6 device as active/inactive.

 CT6 Configurator Activate Device

## Install SW onto a CT6 device
 This option allows you to wipe the CT6 device flash and reload it.

 First the factory configuration is read from the CT6 device flash. The flash will then be erased, MicroPython will be reloaded followed by the CT6 firmware. This option allows the user to recover a CT6 unit that is not working correctly if required.

 A USB cable must be connected to the CT6 device to use this option. Select the 'Install CT6 SW' button
 and the CT6 factory configuration will be read from the device as shown below.

  CT6 Configurator Install

As instructed in the window remove power from the CT6 device and hold the button on the Pico W device down.
The hole next to the C on the CT6 on the front of the CT6 case allows you hold this button down without
removing the Pico W from the CT6 case. The Pico W device will then be erased and reloaded and should
complete as shown below.

  CT6 Configurator Install

## Scan for CT6 devices
 The Scan tab allows you to check your LAN for any CT6 devices that may be present. Select the Scan button
 to start the scanning process. The dropdown list of CT6 Devices is then populated with those that are found.

  CT6 Configurator Scan

You can then power cycle a CT6 device remotely if required by selecting the device from the drop down list and then selecting the 'Power Cycle CT6 Device' button. The CT6 device will power off and after 4 or 5 seconds power back on again to reconnect to the WiFi network as shown below.

  CT6 Configurator Scan

## Calibrate the CT6 measurements
The CT6 device measures the AC mains voltage and the current on port connected to a current transformer (CT).

### Voltage Calibration

The CT6 device is powered from an AC supply. The CT6 device measures the mains AC voltage by measuring its AC supply voltage.
This supply voltage is dropped down to 9-16 volts from the AC mains voltage by the power adapter used.
When the CT6 device is manufactured it's voltage measurements are calibrated. This is done using the recommended
power adaptor. If you wish to use another power adaptor it must provide between 9 and 16V AC to the CT6 device and
be calibrated. Using the 'CALIBRATE VOLTAGE' tab you can perform CT6 voltage calibration to ensure the voltage
measured by the CT6 device is accurate.

To do this you have to manually measure the AC voltage using a digital multimeter (DMM) or some other device. Care must be taken when doing this as the AC mains voltage is dangerous. Use a connector block to measure the AC mains voltage with a DMM. Some inline energy monitoring devices will report the AC mains voltage which could be used instead of a DMM. Note that the accuracy of the voltage measurement will dictate the accuracy of the CT6 device power readings.

To perform the voltage calibration enter the measures AC voltage into the field on the CALIBRATE VOLTAGE tab. The '60 Hz AC supply switch should be left off unless your AC mains supply frequency is 60 Hz. In this case the AC mains frequency is assumed to be 50 Hz. Then select the 'PERFORM VOLTAGE CALIBRATION' button as shown below.

  CT6 Voltage Calibration

### Current Calibration

When the CT6 device is manufactured it is calibrated using a 'YHDC SCT013 100A 0-1V' current transformer. If you wish to use a different transformer then you will need to calibrate the CT port with the new CT connected. A current of at least 1 amps must be passing through the cable that the CT is connected to in order to calibrate it. It is recommended that this current is around 10 amps. The 'CALIBRATE CURRENT' tab can used to calibrate the current measurement on the device port. You will need an external method to measure the current so that you can enter the value into the 'AC Current (Amps)' field. The equipment to perform this calibration is detailed in [README_MFG]README_MFG.md).

With a load on the connected CT enter the 'AC Current (Amps)' measured value. The '60 Hz AC supply switch should be left off unless your AC mains supply frequency is 60 Hz. Then select the 'CALIBRATE CURRENT' button as shown below.

  CT6 Current Calibration

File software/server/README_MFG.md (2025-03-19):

# CT6 Test and Calibration.
This document details how to install the software onto the RPi Pico W on the CT6 unit, test it and calibrate it.

## Installation of SW
To use the tools to test and calibrate a CT6 unit the Linux package must be installed.
This installer has to be built first. To build the installer perform the following

```
./build.sh
----------------------------------------------------------------------
Ran 4 tests in 0.014s

OK
Loading configuration file /home/pja/.config/pypoetry/config.toml
Using virtualenv: /home/pja/.cache/pypoetry/virtualenvs/ct6-HDEVhVyI-py3.12
Building ct6 (10.3)
  - Building sdist
Ignoring: tests/lib/__pycache__/__init__.cpython-312.pyc
Ignoring: ct6/__pycache__/ct6_configurator.cpython-312.pyc
Ignoring: lib/__pycache__/config.cpython-312.pyc
Ignoring: tests/lib/__pycache__/base_constants.cpython-312.pyc
Ignoring: tests/__pycache__/mean_stats.cpython-312.pyc
Ignoring: ct6/__pycache__/ct6_mfg_tool.cpython-312.pyc
Ignoring: lib/__pycache__/__init__.cpython-312.pyc
Ignoring: ct6/__pycache__/__init__.cpython-312.pyc
Ignoring: lib/__pycache__/yview.cpython-312.pyc
Ignoring: lib/__pycache__/base_constants.cpython-312.pyc
Ignoring: tests/__pycache__/constants.cpython-312.pyc
Ignoring: dist/ct6-10.3.tar.gz
Ignoring: ct6/__pycache__/ct6_tool.cpython-312.pyc
  - Adding: /home/pja/git-repos/ct6_meter_os/software/server/ct6/.gitignore
  - Adding: /home/pja/git-repos/ct6_meter_os/software/server/ct6/__init__.py
  - Adding: /home/pja/git-repos/ct6_meter_os/software/server/ct6/ct6_configurator.py
  - Adding: /home/pja/git-repos/ct6_meter_os/software/server/ct6/ct6_dash.py
  - Adding: /home/pja/git-repos/ct6_meter_os/software/server/ct6/ct6_dash_mgr.py
  - Adding: /home/pja/git-repos/ct6_meter_os/software/server/ct6/ct6_db_store.py
  - Adding: /home/pja/git-repos/ct6_meter_os/software/server/ct6/ct6_mfg_tool.py
  - Adding: /home/pja/git-repos/ct6_meter_os/software/server/ct6/ct6_stats.py
  - Adding: /home/pja/git-repos/ct6_meter_os/software/server/ct6/ct6_tool.py
  - Adding: /home/pja/git-repos/ct6_meter_os/software/server/lib/.gitignore
  - Adding: /home/pja/git-repos/ct6_meter_os/software/server/lib/__init__.py
  - Adding: /home/pja/git-repos/ct6_meter_os/software/server/lib/base_constants.py
  - Adding: /home/pja/git-repos/ct6_meter_os/software/server/lib/config.py
  - Adding: /home/pja/git-repos/ct6_meter_os/software/server/lib/db_handler.py
  - Adding: /home/pja/git-repos/ct6_meter_os/software/server/lib/ngt_examples.py
  - Adding: /home/pja/git-repos/ct6_meter_os/software/server/lib/yview.py
  - Adding: /home/pja/git-repos/ct6_meter_os/software/server/picow/.gitignore
  - Adding: /home/pja/git-repos/ct6_meter_os/software/server/picow/README.md
  - Adding: /home/pja/git-repos/ct6_meter_os/software/server/picow/app1/__init__.py
  - Adding: /home/pja/git-repos/ct6_meter_os/software/server/picow/app1/app.py
  - Adding: /home/pja/git-repos/ct6_meter_os/software/server/picow/app1/cmd_handler.py
  - Adding: /home/pja/git-repos/ct6_meter_os/software/server/picow/app1/constants.py
  - Adding: /home/pja/git-repos/ct6_meter_os/software/server/picow/app1/lib/__init__.py
  - Adding: /home/pja/git-repos/ct6_meter_os/software/server/picow/app1/lib/base_cmd_handler.py
  - Adding: /home/pja/git-repos/ct6_meter_os/software/server/picow/app1/lib/base_constants.py
  - Adding: /home/pja/git-repos/ct6_meter_os/software/server/picow/app1/lib/base_machine.py
  - Adding: /home/pja/git-repos/ct6_meter_os/software/server/picow/app1/lib/bluetooth.py
  - Adding: /home/pja/git-repos/ct6_meter_os/software/server/picow/app1/lib/config.py
  - Adding: /home/pja/git-repos/ct6_meter_os/software/server/picow/app1/lib/drivers/__init__.py
  - Adding: /home/pja/git-repos/ct6_meter_os/software/server/picow/app1/lib/drivers/atm90e32.py
  - Adding: /home/pja/git-repos/ct6_meter_os/software/server/picow/app1/lib/drivers/st7789.py
  - Adding: /home/pja/git-repos/ct6_meter_os/software/server/picow/app1/lib/fs.py
  - Adding: /home/pja/git-repos/ct6_meter_os/software/server/picow/app1/lib/hardware.py
  - Adding: /home/pja/git-repos/ct6_meter_os/software/server/picow/app1/lib/io.py
  - Adding: /home/pja/git-repos/ct6_meter_os/software/server/picow/app1/lib/rest_server.py
  - Adding: /home/pja/git-repos/ct6_meter_os/software/server/picow/app1/lib/umqttsimple.py
  - Adding: /home/pja/git-repos/ct6_meter_os/software/server/picow/app1/lib/uo.py
  - Adding: /home/pja/git-repos/ct6_meter_os/software/server/picow/app1/lib/wifi.py
  - Adding: /home/pja/git-repos/ct6_meter_os/software/server/picow/app1/lib/ydev.py
  - Adding: /home/pja/git-repos/ct6_meter_os/software/server/picow/app1/mean_stats.py
  - Adding: /home/pja/git-repos/ct6_meter_os/software/server/picow/app1/project.py
  - Adding: /home/pja/git-repos/ct6_meter_os/software/server/picow/app1/vga2_bold_16x16.py
  - Adding: /home/pja/git-repos/ct6_meter_os/software/server/picow/app2/__init__.py
  - Adding: /home/pja/git-repos/ct6_meter_os/software/server/picow/main.py
  - Adding: /home/pja/git-repos/ct6_meter_os/software/server/picow/tools/.gitignore
  - Adding: /home/pja/git-repos/ct6_meter_os/software/server/picow/tools/esp32_erase_flash.sh
  - Adding: /home/pja/git-repos/ct6_meter_os/software/server/picow/tools/esp32_start_rshell.sh
  - Adding: /home/pja/git-repos/ct6_meter_os/software/server/picow/tools/main.py
  - Adding: /home/pja/git-repos/ct6_meter_os/software/server/picow/tools/picow_erase_flash.sh
  - Adding: /home/pja/git-repos/ct6_meter_os/software/server/picow/tools/picow_flash_images/firmware.uf2
  - Adding: /home/pja/git-repos/ct6_meter_os/software/server/picow/tools/picow_flash_images/flash_nuke.uf2
  - Adding: /home/pja/git-repos/ct6_meter_os/software/server/picow/tools/picow_micropython_flash.sh
  - Adding: /home/pja/git-repos/ct6_meter_os/software/server/picow/tools/picow_start_rshell.sh
  - Adding: /home/pja/git-repos/ct6_meter_os/software/server/pyproject.toml
  - Adding: pyproject.toml
  - Adding: README.md
  - Built ct6-10.3.tar.gz
  - Building wheel
Ignoring: tests/lib/__pycache__/__init__.cpython-312.pyc
Ignoring: ct6/__pycache__/ct6_configurator.cpython-312.pyc
Ignoring: lib/__pycache__/config.cpython-312.pyc
Ignoring: tests/lib/__pycache__/base_constants.cpython-312.pyc
Ignoring: tests/__pycache__/mean_stats.cpython-312.pyc
Ignoring: ct6/__pycache__/ct6_mfg_tool.cpython-312.pyc
Ignoring: lib/__pycache__/__init__.cpython-312.pyc
Ignoring: ct6/__pycache__/__init__.cpython-312.pyc
Ignoring: lib/__pycache__/yview.cpython-312.pyc
Ignoring: lib/__pycache__/base_constants.cpython-312.pyc
Ignoring: tests/__pycache__/constants.cpython-312.pyc
Ignoring: dist/ct6-10.3.tar.gz
Ignoring: ct6/__pycache__/ct6_tool.cpython-312.pyc
  - Adding: /home/pja/git-repos/ct6_meter_os/software/server/ct6/.gitignore
  - Adding: /home/pja/git-repos/ct6_meter_os/software/server/ct6/__init__.py
  - Adding: /home/pja/git-repos/ct6_meter_os/software/server/ct6/ct6_configurator.py
  - Adding: /home/pja/git-repos/ct6_meter_os/software/server/ct6/ct6_dash.py
  - Adding: /home/pja/git-repos/ct6_meter_os/software/server/ct6/ct6_dash_mgr.py
  - Adding: /home/pja/git-repos/ct6_meter_os/software/server/ct6/ct6_db_store.py
  - Adding: /home/pja/git-repos/ct6_meter_os/software/server/ct6/ct6_mfg_tool.py
  - Adding: /home/pja/git-repos/ct6_meter_os/software/server/ct6/ct6_stats.py
  - Adding: /home/pja/git-repos/ct6_meter_os/software/server/ct6/ct6_tool.py
  - Adding: /home/pja/git-repos/ct6_meter_os/software/server/lib/.gitignore
  - Adding: /home/pja/git-repos/ct6_meter_os/software/server/lib/__init__.py
  - Adding: /home/pja/git-repos/ct6_meter_os/software/server/lib/base_constants.py
  - Adding: /home/pja/git-repos/ct6_meter_os/software/server/lib/config.py
  - Adding: /home/pja/git-repos/ct6_meter_os/software/server/lib/db_handler.py
  - Adding: /home/pja/git-repos/ct6_meter_os/software/server/lib/ngt_examples.py
  - Adding: /home/pja/git-repos/ct6_meter_os/software/server/lib/yview.py
  - Adding: /home/pja/git-repos/ct6_meter_os/software/server/picow/.gitignore
  - Adding: /home/pja/git-repos/ct6_meter_os/software/server/picow/README.md
  - Adding: /home/pja/git-repos/ct6_meter_os/software/server/picow/app1/__init__.py
  - Adding: /home/pja/git-repos/ct6_meter_os/software/server/picow/app1/app.py
  - Adding: /home/pja/git-repos/ct6_meter_os/software/server/picow/app1/cmd_handler.py
  - Adding: /home/pja/git-repos/ct6_meter_os/software/server/picow/app1/constants.py
  - Adding: /home/pja/git-repos/ct6_meter_os/software/server/picow/app1/lib/__init__.py
  - Adding: /home/pja/git-repos/ct6_meter_os/software/server/picow/app1/lib/base_cmd_handler.py
  - Adding: /home/pja/git-repos/ct6_meter_os/software/server/picow/app1/lib/base_constants.py
  - Adding: /home/pja/git-repos/ct6_meter_os/software/server/picow/app1/lib/base_machine.py
  - Adding: /home/pja/git-repos/ct6_meter_os/software/server/picow/app1/lib/bluetooth.py
  - Adding: /home/pja/git-repos/ct6_meter_os/software/server/picow/app1/lib/config.py
  - Adding: /home/pja/git-repos/ct6_meter_os/software/server/picow/app1/lib/drivers/__init__.py
  - Adding: /home/pja/git-repos/ct6_meter_os/software/server/picow/app1/lib/drivers/atm90e32.py
  - Adding: /home/pja/git-repos/ct6_meter_os/software/server/picow/app1/lib/drivers/st7789.py
  - Adding: /home/pja/git-repos/ct6_meter_os/software/server/picow/app1/lib/fs.py
  - Adding: /home/pja/git-repos/ct6_meter_os/software/server/picow/app1/lib/hardware.py
  - Adding: /home/pja/git-repos/ct6_meter_os/software/server/picow/app1/lib/io.py
  - Adding: /home/pja/git-repos/ct6_meter_os/software/server/picow/app1/lib/rest_server.py
  - Adding: /home/pja/git-repos/ct6_meter_os/software/server/picow/app1/lib/umqttsimple.py
  - Adding: /home/pja/git-repos/ct6_meter_os/software/server/picow/app1/lib/uo.py
  - Adding: /home/pja/git-repos/ct6_meter_os/software/server/picow/app1/lib/wifi.py
  - Adding: /home/pja/git-repos/ct6_meter_os/software/server/picow/app1/lib/ydev.py
  - Adding: /home/pja/git-repos/ct6_meter_os/software/server/picow/app1/mean_stats.py
  - Adding: /home/pja/git-repos/ct6_meter_os/software/server/picow/app1/project.py
  - Adding: /home/pja/git-repos/ct6_meter_os/software/server/picow/app1/vga2_bold_16x16.py
  - Adding: /home/pja/git-repos/ct6_meter_os/software/server/picow/app2/__init__.py
  - Adding: /home/pja/git-repos/ct6_meter_os/software/server/picow/main.py
  - Adding: /home/pja/git-repos/ct6_meter_os/software/server/picow/tools/.gitignore
  - Adding: /home/pja/git-repos/ct6_meter_os/software/server/picow/tools/esp32_erase_flash.sh
  - Adding: /home/pja/git-repos/ct6_meter_os/software/server/picow/tools/esp32_start_rshell.sh
  - Adding: /home/pja/git-repos/ct6_meter_os/software/server/picow/tools/main.py
  - Adding: /home/pja/git-repos/ct6_meter_os/software/server/picow/tools/picow_erase_flash.sh
  - Adding: /home/pja/git-repos/ct6_meter_os/software/server/picow/tools/picow_flash_images/firmware.uf2
  - Adding: /home/pja/git-repos/ct6_meter_os/software/server/picow/tools/picow_flash_images/flash_nuke.uf2
  - Adding: /home/pja/git-repos/ct6_meter_os/software/server/picow/tools/picow_micropython_flash.sh
  - Adding: /home/pja/git-repos/ct6_meter_os/software/server/picow/tools/picow_start_rshell.sh
  - Adding: /home/pja/git-repos/ct6_meter_os/software/server/pyproject.toml
  - Built ct6-10.3-py3-none-any.whl
```

To install the deb file perform the following command. Note that the version of the package may change.

```
pipx uninstall ct6
uninstalled ct6! ✨ 🌟 ✨
(ct6-py3.12) pja@L7490:~/git-repos/ct6_meter_os/software/server$ pipx install installers/ct6-10.3-py3-none-any.whl
⚠️  Note: ct6_configurator was already on your PATH at /home/pja/.cache/pypoetry/virtualenvs/ct6-HDEVhVyI-py3.12/bin/ct6_configurator
⚠️  Note: ct6_dash was already on your PATH at /home/pja/.cache/pypoetry/virtualenvs/ct6-HDEVhVyI-py3.12/bin/ct6_dash
⚠️  Note: ct6_dash_mgr was already on your PATH at /home/pja/.cache/pypoetry/virtualenvs/ct6-HDEVhVyI-py3.12/bin/ct6_dash_mgr
⚠️  Note: ct6_db_store was already on your PATH at /home/pja/.cache/pypoetry/virtualenvs/ct6-HDEVhVyI-py3.12/bin/ct6_db_store
⚠️  Note: ct6_mfg_tool was already on your PATH at /home/pja/.cache/pypoetry/virtualenvs/ct6-HDEVhVyI-py3.12/bin/ct6_mfg_tool
⚠️  Note: ct6_stats was already on your PATH at /home/pja/.cache/pypoetry/virtualenvs/ct6-HDEVhVyI-py3.12/bin/ct6_stats
⚠️  Note: ct6_tool was already on your PATH at /home/pja/.cache/pypoetry/virtualenvs/ct6-HDEVhVyI-py3.12/bin/ct6_tool
  installed package ct6 10.3, installed using Python 3.12.3
  These apps are now globally available
    - ct6_configurator
    - ct6_dash
    - ct6_dash_mgr
    - ct6_db_store
    - ct6_mfg_tool
    - ct6_stats
    - ct6_tool
done! ✨ 🌟 ✨
```

## Full test and calibration of a CT6 unit.

### Equipment required

#### Option 1

- CT6 unit hardware (CT6 board with display connected).

- CT6 test system (high accuracy) as shown below.

Test/Calibration System

This is the preffered option.

Note !!!

- When using this test system the calibrated current value is 6 x the value measured by the Shelly 1PM Plus unit.

- The Shelly 1PM Plus unit must be calibrated as detailed [here](https://github.com/pjaos/test_equipment).

#### Option 2

- CT6 unit hardware (CT6 board with display connected).
- CT6 AC power supply.
- Modified micro USB cable. This cable must have the +5v power lead disconnected. This is normally the red wire in the 4 wire USB cable.
- AC power meter ([E.G ENERGENIE ENE007](https://energenie4u.co.uk/catalogue/product/ENER007)). However it should be noted that the accuracy of this device will govern the CT6 calibration accuracy.
- Linux PC running Ubuntu 20.04 or later.
- [SCT013_100A current transformer](https://www.mouser.com/datasheet/2/744/101990029_SCT_013_000_Datasheet-2487743.pdf)
- [Mains Test Block](https://uk.rs-online.com/web/p/mains-test-blocks/0458926?gb=b)
- AC load that draws at least 5 amps, preferably about 10 amps. A 2kW fan heater can be used for this.

The equipment should be connected as per the diagram shown below.

Test/Calibration System

This test system can be used if you don't have the previous test system available. It will will however result in less accurate voltage and current calibration.

This can be due to the calibration current not being high enough to move onto the linear portion (25% of max rated) CT rating (E.G 25A for a 100A CT). You can compensate for this by running the mains cable 6 x through the CT (assuming a 100A CT). The measured current isthen multiplied by 6 to get the calibration current.

Another source of errors is the fact that the mains AC voltage is rarely stable.

### CT6 Upgrade and recalibration

To upgrade and re calibrate CT6 units the ct6_configurator tool should be used. Details of how to use this tool are detailed [here](setting_up_ct6_units.md). To re calibrate the voltage and current measurements either option 1 or option 2 test systems must be used. If an option 1 test system is used (increased accuracy test system) you will need to add the following argument when starting the -s <Shelly 1PM Plus IP address> argument. E.G

```
ct6_configurator -s 192.168.0.10
```

## CT6 unit bring up and calibration load.

### Equipment required
- CT6 unit hardware (CT6 board with display connected).
- CT6 AC power supply.
- Modified micro USB cable. This cable must have the +5v power lead disconnected. This is normally the red wire in the 4 wire USB cable.

The equipment should be connected as per the diagram shown below.

Test System

### CT6 initialisation and loading calibration data

- It is important to understand that the calibration file created in the previous section (/home/auser/test_logs/ASY0398_V01.6000_SN00001823_20240111063130_factory.cfg) is only valid if the same AC PSU is used. It should be possible to use the same type (make/model) of PSU. However at the time of writing I have calibrated each unit with the PSU it will be used with to ensure that the measurement accuracy is as good as possible. The same PSU must be used because the AC line frequency is measured on the CT6 hardware using the voltage across R22 which is derived from the AC supply voltage through the AC -AC transformer and the potential divider of R21 and R22.

This section details how to fully wipe and reload the code on the Pico W and then reload the factory configuration file.

- The steps below show will load all code onto the CT6 unit and test it. You must run the ct6_mfg_tool in the software/server folder. Note that '<YOUR WIFI SSID>' and '<YOUR WIFI PASSWORD>' should be replaced with your WiFi SSID and password.

```
ct6_mfg_tool --no_cal
INPUT: The local WiFi SSID: : <YOUR WIFI SSID>
INPUT: The local WiFi password: : <YOUR WIFI PASSWORD>
INFO:  Created house_wifi.cfg
INFO:  -----------------------------------
INFO:  | Test Case |         Description |
INFO:  -----------------------------------
INFO:  |      1000 | Enter ASSY and S.N. |
INFO:  -----------------------------------
INPUT: Enter the board assembly number or 'r' to repeat last test: ^TASY0398V01.6
INPUT: Enter the board serial number: ^TSN00001823
INFO:  ----------------------------------
INFO:  |         UNIT UNDER TEST |      |
INFO:  ----------------------------------
INFO:  |         Assembly Number |  398 |
INFO:  ----------------------------------
INFO:  |    CT6 hardware version |  1.6 |
INFO:  ----------------------------------
INFO:  | CT6 board serial Number | 1823 |
INFO:  ----------------------------------
INFO:  ------------------------------------------
INFO:  | Test Case |                Description |
INFO:  ------------------------------------------
INFO:  |      3000 | Erase Pico W flash memory. |
INFO:  ------------------------------------------
INFO:  Ensure the USB Pico W is connected to this PC.
INFO:  Hold the button down on the Pico W and power up the CT6 device.
INFO:  Waiting for RPi Pico W to restart.
INFO:
INFO:  Release the button on the Pico W.
INFO:
INFO:  Copying ../picow/tools/picow_flash_images/flash_nuke.uf2 to /media/pja/RPI-RP2
INFO:  Waiting for RPi Pico W to restart.
INFO:  Checking /media/pja/RPI-RP2
INFO:  ----------------------------------------------------------
INFO:  | Test Case |                                Description |
INFO:  ----------------------------------------------------------
INFO:  |      4000 | Load MicroPython onto Pico W flash memory. |
INFO:  ----------------------------------------------------------
INFO:  Ensure the USB Pico W is connected to this PC.
INFO:  Hold the button down on the Pico W and power up the CT6 device.
INFO:  Waiting for RPi Pico W to restart.
INFO:  Loading micropython image onto the RPi Pico W
INFO:  Copying ../picow/tools/picow_flash_images/firmware.uf2 to /media/pja/RPI-RP2
INFO:  Waiting for RPi Pico W to restart.
INFO:  Checking serial connections for CT6 device.
INFO:  CT6 Unit:  MicroPython v1.20.0-326-gcfcce4b53 on 2023-07-25; Raspberry Pi Pico W with RP2040
INFO:  --------------------------------------
INFO:  | Test Case |            Description |
INFO:  --------------------------------------
INFO:  |      5000 | Load the CT6 firmware. |
INFO:  --------------------------------------
INFO:  Checking python code in the app1 folder using pyflakes
INFO:  pyflakes found no issues with the app1 folder code.
INFO:  Checking serial connections for CT6 device.
INFO:  CT6 Unit:  MicroPython v1.20.0-326-gcfcce4b53 on 2023-07-25; Raspberry Pi Pico W with RP2040
cannot access '/pyboard/*': No such file or directory
INFO:  Rebooting the MCU
INFO:  Checking serial connections for CT6 device.
INFO:  CT6 Unit:  MicroPython v1.20.0-326-gcfcce4b53 on 2023-07-25; Raspberry Pi Pico W with RP2040
INFO:  Rebooted the MCU
INFO:  Checking serial connections for CT6 device.
INFO:  Generated app1/project.mpy from app1/project.py
INFO:  Generated app1/cmd_handler.mpy from app1/cmd_handler.py
INFO:  Generated app1/vga2_bold_16x16.mpy from app1/vga2_bold_16x16.py
INFO:  Generated app1/__init__.mpy from app1/__init__.py
INFO:  Generated app1/constants.mpy from app1/constants.py
INFO:  Generated app1/app.mpy from app1/app.py
INFO:  Generated app1/lib/uo.mpy from app1/lib/uo.py
INFO:  Generated app1/lib/bluetooth.mpy from app1/lib/bluetooth.py
INFO:  Generated app1/lib/ydev.mpy from app1/lib/ydev.py
INFO:  Generated app1/lib/base_cmd_handler.mpy from app1/lib/base_cmd_handler.py
INFO:  Generated app1/lib/hardware.mpy from app1/lib/hardware.py
INFO:  Generated app1/lib/__init__.mpy from app1/lib/__init__.py
INFO:  Generated app1/lib/config.mpy from app1/lib/config.py
INFO:  Generated app1/lib/rest_server.mpy from app1/lib/rest_server.py
INFO:  Generated app1/lib/base_machine.mpy from app1/lib/base_machine.py
INFO:  Generated app1/lib/base_constants.mpy from app1/lib/base_constants.py
INFO:  Generated app1/lib/fs.mpy from app1/lib/fs.py
INFO:  Generated app1/lib/wifi.mpy from app1/lib/wifi.py
INFO:  Generated app1/lib/io.mpy from app1/lib/io.py
INFO:  Generated app1/lib/drivers/max6675.mpy from app1/lib/drivers/max6675.py
INFO:  Generated app1/lib/drivers/ssd1306.mpy from app1/lib/drivers/ssd1306.py
INFO:  Generated app1/lib/drivers/__init__.mpy from app1/lib/drivers/__init__.py
INFO:  Generated app1/lib/drivers/atm90e32.mpy from app1/lib/drivers/atm90e32.py
INFO:  Generated app1/lib/drivers/lcd.mpy from app1/lib/drivers/lcd.py
INFO:  Generated app1/lib/drivers/st7789.mpy from app1/lib/drivers/st7789.py
INFO:  Generated app1/lib/drivers/rotary_encoder.mpy from app1/lib/drivers/rotary_encoder.py
INFO:  Generated app1/lib/drivers/ads1115.mpy from app1/lib/drivers/ads1115.py
INFO:  Loading CT6 firmware. Please wait...
INFO:  Loaded all 28 python files.
INFO:  Deleted app1/vga2_bold_16x16.mpy
INFO:  Deleted app1/__init__.mpy
INFO:  Deleted app1/project.mpy
INFO:  Deleted app1/cmd_handler.mpy
INFO:  Deleted app1/constants.mpy
INFO:  Deleted app1/app.mpy
INFO:  Deleted app1/lib/base_cmd_handler.mpy
INFO:  Deleted app1/lib/__init__.mpy
INFO:  Deleted app1/lib/base_constants.mpy
INFO:  Deleted app1/lib/uo.mpy
INFO:  Deleted app1/lib/wifi.mpy
INFO:  Deleted app1/lib/config.mpy
INFO:  Deleted app1/lib/bluetooth.mpy
INFO:  Deleted app1/lib/ydev.mpy
INFO:  Deleted app1/lib/fs.mpy
INFO:  Deleted app1/lib/io.mpy
INFO:  Deleted app1/lib/base_machine.mpy
INFO:  Deleted app1/lib/rest_server.mpy
INFO:  Deleted app1/lib/hardware.mpy
INFO:  Deleted app1/lib/drivers/lcd.mpy
INFO:  Deleted app1/lib/drivers/__init__.mpy
INFO:  Deleted app1/lib/drivers/ads1115.mpy
INFO:  Deleted app1/lib/drivers/ssd1306.mpy
INFO:  Deleted app1/lib/drivers/max6675.mpy
INFO:  Deleted app1/lib/drivers/atm90e32.mpy
INFO:  Deleted app1/lib/drivers/rotary_encoder.mpy
INFO:  Deleted app1/lib/drivers/st7789.mpy
INFO:  Running the CT6 firmware
INFO:  Running APP1 on the CT6 unit. Waiting for WiFi connection...
INFO:  Checking serial connections for CT6 device.
INFO:  Updating the MCU WiFi configuration.
INFO:  Checking serial connections for CT6 device.
INFO:  CT6 Unit:  MicroPython v1.20.0-326-gcfcce4b53 on 2023-07-25; Raspberry Pi Pico W with RP2040
INFO:  Rebooting the MCU
INFO:  Checking serial connections for CT6 device.
INFO:  CT6 Unit:  MicroPython v1.20.0-326-gcfcce4b53 on 2023-07-25; Raspberry Pi Pico W with RP2040
INFO:  Rebooted the MCU
INFO:  Starting MCU to register on the WiFi network.
INFO:  Running APP1 on the CT6 unit. Waiting for WiFi connection...
INFO:  Checking serial connections for CT6 device.
INFO:  CT6 IP address = 192.168.0.19
INFO:  Waiting for firmware to startup on CT6 device.
INFO:  Firmware is now running on the CT6 device.
INFO:  The CT6 unit (192.168.0.19) has rebooted. Waiting for it to re register on the WiFi network.
INFO:  CT6 unit is now connected to the WiFi network.
INFO:  ---------------------------------
INFO:  | Test Case |       Description |
INFO:  ---------------------------------
INFO:  |      6000 | Temperature test. |
INFO:  ---------------------------------
INFO:  Checking the CT6 board temperature.
INFO:  CT6 board temperature = 20.2 °C
INFO:  ---------------------------
INFO:  | Test Case | Description |
INFO:  ---------------------------
INFO:  |      7000 |   LED test. |
INFO:  ---------------------------
INFO:  Is the green LED next to the WiFi switch flashing ? y/n
y
INFO:  Is the blue LED next to the reset switch flashing ? y/n
y
INFO:  ----------------------------
INFO:  | Test Case |  Description |
INFO:  ----------------------------
INFO:  |      8000 | Switch test. |
INFO:  ----------------------------
INFO:  Hold down the WiFi switch on the CT6 board.
INFO:  Checking serial connections for CT6 device.
INFO:  The WiFi switch is working. Release the WiFi switch.
INFO:  Press and release the reset switch on the CT6 board.
INFO:  The CT6 unit (192.168.0.19) has rebooted. Waiting for it to re register on the WiFi network.
INFO:  CT6 unit is now connected to the WiFi network.
INFO:  -----------------------------------------
INFO:  | Test Case |               Description |
INFO:  -----------------------------------------
INFO:  |      9000 | Power cycle circuit test. |
INFO:  -----------------------------------------
INFO:  Checking the power cycle feature on the CT6 board.
INFO:  Waiting for the CT6 unit  (192.168.0.19) to reboot.
INFO:  The CT6 unit (192.168.0.19) has rebooted. Waiting for it to re register on the WiFi network.
INFO:  CT6 unit is now connected to the WiFi network.
INFO:  -----------------------------
INFO:  | Test Case |   Description |
INFO:  -----------------------------
INFO:  |     10000 | Display test. |
INFO:  -----------------------------
INFO:  Is the display showing AC voltage ?
INPUT: Is the display showing the CT6 IP address y/n: y
INFO:  ------------------------------------------------------
INFO:  | Test Case |                            Description |
INFO:  ------------------------------------------------------
INFO:  |     11000 | Set assembly number and serial number. |
INFO:  ------------------------------------------------------
INFO:  Factory setup and calibration of CT6 unit (192.168.0.19).
INFO:  Reading configuration from 192.168.0.19
INFO:
INFO:  Setting assembly label to ASY0398_V001.600_SN00001823.
INFO:  Successfully set the unit serial number.
INFO:  ----------------------------------------------
INFO:  | Test Case |                    Description |
INFO:  ----------------------------------------------
INFO:  |     13000 | Store CT6 configuration files. |
INFO:  ----------------------------------------------
INFO:  Get this.machine.cfg from 192.168.0.19.
INFO:  Save to this.machine.cfg from 192.168.0.19.
INFO:  Saved to /home/pja/test_logs/ASY0398_V01.6000_SN00001823_20240116140956_this.machine.cfg
WARN:  !!!!!!!!!!!!!!!!!!!!!!!!!!!!!!!!!!!!!!!!!!!!!!!!!!!
WARN:  !!! The CT6 unit is NOT CALIBRATED.             !!!
WARN:  !!! To resolve this issue                       !!!
WARN:  !!! 1: Run this tool with '--setup_wifi' to     !!!
WARN:  !!!    connect the WiFi to your network.        !!!
WARN:  !!! 2: Run this tool with either '--cal_only'   !!!
WARN:  !!!    or '--restore'                           !!!
WARN:  !!!    --cal_only takes you through the CT6     !!!
WARN:  !!!      calibration process.                   !!!
WARN:  !!!    --restore allows you to load an old      !!!
WARN:  !!!      calibration (factory config) file      !!!
WARN:  !!!!!!!!!!!!!!!!!!!!!!!!!!!!!!!!!!!!!!!!!!!!!!!!!!!
INFO:  ---------------------------------------------------
INFO:  | Test Case |                         Description |
INFO:  ---------------------------------------------------
INFO:  |     14000 | Load factory default configuration. |
INFO:  ---------------------------------------------------
INFO:  Set factory CT6 WiFi.
INFO:  Took 137.4 seconds to test.
```

- Now reload your WiFi configuration to the CT6 unit run the following command.

```
ct6_mfg_tool --setup_wifi
INFO:  Setting up CT6 WiFi interface.
INFO:  Checking serial connections for CT6 device.
INFO:  CT6 Unit:  MicroPython v1.20.0-326-gcfcce4b53 on 2023-07-25; Raspberry Pi Pico W with RP2040
INFO:  WiFi SSID: <YOUR WIFI SSID>
INFO:  The CT6 WiFi interface is now configured.
```

- The CT6 unit is now up and running but has no calibration data loaded. This step allows you to load the calibration data.
  In this example the calibration file is held in the /home/auser folder and is named ASY0398_V02.0000_SN00001900_20240111063130_factory.cfg
  and the CT6 unit IP address (as show on it's display) is 192.168.0.10.

```
ct6_mfg_tool --restore /home/auser/ASY0398_V02.0000_SN00001900_20240111063130_factory.cfg -a 192.168.0.10
INFO:  Get this.machine.cfg from 192.168.0.10.
INFO:  ----------------------------------
INFO:  |         UNIT UNDER TEST |      |
INFO:  ----------------------------------
INFO:  |         Assembly Number |  398 |
INFO:  ----------------------------------
INFO:  |    CT6 hardware version |  2.0 |
INFO:  ----------------------------------
INFO:  | CT6 board serial Number | 1900 |
INFO:  ----------------------------------
INFO:  Checking serial connections for CT6 device.
INFO:  CT6 Unit:  MicroPython v1.20.0-326-gcfcce4b53 on 2023-07-25; Raspberry Pi Pico W with RP2040
INFO:  Loaded the factory.cfg data to the CT6 board.
```

The CT6 unit is now ready for use. See the README.md file for more information on this.

### CT6 Full test and calibration.

- The ct6_mfg_tool program will load all code onto the CT6 unit, test it and calibrate each port as shown below.
  You must run the ct6_mfg_tool in the software/server folder. Note that '<YOUR WIFI SSID>' and '<YOUR WIFI PASSWORD>' should be replaced with your WiFi SSID and password. You must run this process if you have a new RPi Pico W board as it erases the Pico W flash and loads Micro Python onto it.

Note

- If your AC supply is 60 Hz (default = 50 Hz) you'll also need to add the '--ac60hz' command line option to the command below.

- If you are using the option 1 test system then you will need to use the -s argument followed by the IP address of the Shelly 1PM Plus unit in the test system.

```
ct6_mfg_tool
INPUT: The local WiFi SSID: : <YOUR WIFI SSID>
INPUT: The local WiFi password: : <YOUR WIFI PASSWORD>
INFO:  -----------------------------------
INFO:  | Test Case |         Description |
INFO:  -----------------------------------
INFO:  |      1000 | Enter ASSY and S.N. |
INFO:  -----------------------------------
INPUT: Enter the board assembly number or 'r' to repeat last test: ASY0398V01.6
INPUT: Enter the board serial number: SN00001823
INFO:  ----------------------------------
INFO:  |         UNIT UNDER TEST |      |
INFO:  ----------------------------------
INFO:  |         Assembly Number |  398 |
INFO:  ----------------------------------
INFO:  |    CT6 hardware version |  1.6 |
INFO:  ----------------------------------
INFO:  | CT6 board serial Number | 1823 |
INFO:  ----------------------------------
INFO:  ------------------------------------------
INFO:  | Test Case |                Description |
INFO:  ------------------------------------------
INFO:  |      3000 | Erase Pico W flash memory. |
INFO:  ------------------------------------------
INFO:  Ensure the USB Pico W is connected to this PC.
INFO:  Hold the button down on the Pico W and power up the CT6 device.
INFO:  Waiting for RPi Pico W to restart.
INFO:
INFO:  Release the button on the Pico W.
INFO:
INFO:  Copying ../picow/tools/picow_flash_images/flash_nuke.uf2 to /media/auser/RPI-RP2
INFO:  Waiting for RPi Pico W to restart.
INFO:  Checking /media/auser/RPI-RP2
INFO:  ----------------------------------------------------------
INFO:  | Test Case |                                Description |
INFO:  ----------------------------------------------------------
INFO:  |      4000 | Load MicroPython onto Pico W flash memory. |
INFO:  ----------------------------------------------------------
INFO:  Ensure the USB Pico W is connected to this PC.
INFO:  Hold the button down on the Pico W and power up the CT6 device.
INFO:  Waiting for RPi Pico W to restart.
INFO:  Loading micropython image onto the RPi Pico W
INFO:  Copying ../picow/tools/picow_flash_images/firmware.uf2 to /media/auser/RPI-RP2
INFO:  Waiting for RPi Pico W to restart.
INFO:  Checking serial connections for CT6 device.
INFO:  CT6 Unit:  MicroPython v1.20.0-326-gcfcce4b53 on 2023-07-25; Raspberry Pi Pico W with RP2040
INFO:  --------------------------------------
INFO:  | Test Case |            Description |
INFO:  --------------------------------------
INFO:  |      5000 | Load the CT6 firmware. |
INFO:  --------------------------------------
INFO:  Checking python code in the app1 folder using pyflakes
INFO:  pyflakes found no issues with the app1 folder code.
INFO:  Checking serial connections for CT6 device.
INFO:  CT6 Unit:  MicroPython v1.20.0-326-gcfcce4b53 on 2023-07-25; Raspberry Pi Pico W with RP2040
cannot access '/pyboard/*': No such file or directory
INFO:  Rebooting the MCU
INFO:  Checking serial connections for CT6 device.
INFO:  CT6 Unit:  MicroPython v1.20.0-326-gcfcce4b53 on 2023-07-25; Raspberry Pi Pico W with RP2040
INFO:  Rebooted the MCU
INFO:  Checking serial connections for CT6 device.
INFO:  Generated app1/project.mpy from app1/project.py
INFO:  Generated app1/cmd_handler.mpy from app1/cmd_handler.py
INFO:  Generated app1/vga2_bold_16x16.mpy from app1/vga2_bold_16x16.py
INFO:  Generated app1/__init__.mpy from app1/__init__.py
INFO:  Generated app1/constants.mpy from app1/constants.py
INFO:  Generated app1/app.mpy from app1/app.py
INFO:  Generated app1/lib/uo.mpy from app1/lib/uo.py
INFO:  Generated app1/lib/bluetooth.mpy from app1/lib/bluetooth.py
INFO:  Generated app1/lib/ydev.mpy from app1/lib/ydev.py
INFO:  Generated app1/lib/base_cmd_handler.mpy from app1/lib/base_cmd_handler.py
INFO:  Generated app1/lib/hardware.mpy from app1/lib/hardware.py
INFO:  Generated app1/lib/__init__.mpy from app1/lib/__init__.py
INFO:  Generated app1/lib/config.mpy from app1/lib/config.py
INFO:  Generated app1/lib/rest_server.mpy from app1/lib/rest_server.py
INFO:  Generated app1/lib/base_machine.mpy from app1/lib/base_machine.py
INFO:  Generated app1/lib/base_constants.mpy from app1/lib/base_constants.py
INFO:  Generated app1/lib/fs.mpy from app1/lib/fs.py
INFO:  Generated app1/lib/wifi.mpy from app1/lib/wifi.py
INFO:  Generated app1/lib/io.mpy from app1/lib/io.py
INFO:  Generated app1/lib/drivers/max6675.mpy from app1/lib/drivers/max6675.py
INFO:  Generated app1/lib/drivers/ssd1306.mpy from app1/lib/drivers/ssd1306.py
INFO:  Generated app1/lib/drivers/__init__.mpy from app1/lib/drivers/__init__.py
INFO:  Generated app1/lib/drivers/atm90e32.mpy from app1/lib/drivers/atm90e32.py
INFO:  Generated app1/lib/drivers/lcd.mpy from app1/lib/drivers/lcd.py
INFO:  Generated app1/lib/drivers/st7789.mpy from app1/lib/drivers/st7789.py
INFO:  Generated app1/lib/drivers/rotary_encoder.mpy from app1/lib/drivers/rotary_encoder.py
INFO:  Generated app1/lib/drivers/ads1115.mpy from app1/lib/drivers/ads1115.py
INFO:  Loading CT6 firmware. Please wait...
INFO:  Loaded all 28 python files.
INFO:  Deleted app1/vga2_bold_16x16.mpy
INFO:  Deleted app1/__init__.mpy
INFO:  Deleted app1/project.mpy
INFO:  Deleted app1/cmd_handler.mpy
INFO:  Deleted app1/constants.mpy
INFO:  Deleted app1/app.mpy
INFO:  Deleted app1/lib/base_cmd_handler.mpy
INFO:  Deleted app1/lib/__init__.mpy
INFO:  Deleted app1/lib/base_constants.mpy
INFO:  Deleted app1/lib/uo.mpy
INFO:  Deleted app1/lib/wifi.mpy
INFO:  Deleted app1/lib/config.mpy
INFO:  Deleted app1/lib/bluetooth.mpy
INFO:  Deleted app1/lib/ydev.mpy
INFO:  Deleted app1/lib/fs.mpy
INFO:  Deleted app1/lib/io.mpy
INFO:  Deleted app1/lib/base_machine.mpy
INFO:  Deleted app1/lib/rest_server.mpy
INFO:  Deleted app1/lib/hardware.mpy
INFO:  Deleted app1/lib/drivers/lcd.mpy
INFO:  Deleted app1/lib/drivers/__init__.mpy
INFO:  Deleted app1/lib/drivers/ads1115.mpy
INFO:  Deleted app1/lib/drivers/ssd1306.mpy
INFO:  Deleted app1/lib/drivers/max6675.mpy
INFO:  Deleted app1/lib/drivers/atm90e32.mpy
INFO:  Deleted app1/lib/drivers/rotary_encoder.mpy
INFO:  Deleted app1/lib/drivers/st7789.mpy
INFO:  Running the CT6 firmware
INFO:  Running APP1 on the CT6 unit. Waiting for WiFi connection...
INFO:  Checking serial connections for CT6 device.
INFO:  Updating the MCU WiFi configuration.
INFO:  Checking serial connections for CT6 device.
INFO:  CT6 Unit:  MicroPython v1.20.0-326-gcfcce4b53 on 2023-07-25; Raspberry Pi Pico W with RP2040
INFO:  Rebooting the MCU
INFO:  Checking serial connections for CT6 device.
INFO:  CT6 Unit:  MicroPython v1.20.0-326-gcfcce4b53 on 2023-07-25; Raspberry Pi Pico W with RP2040
INFO:  Rebooted the MCU
INFO:  Starting MCU to register on the WiFi network.
INFO:  Running APP1 on the CT6 unit. Waiting for WiFi connection...
INFO:  Checking serial connections for CT6 device.
INFO:  CT6 IP address = 192.168.0.19
INFO:  Waiting for firmware to startup on CT6 device.
INFO:  Firmware is now running on the CT6 device.
INFO:  The CT6 unit (192.168.0.19) has rebooted. Waiting for it to re register on the WiFi network.
INFO:  CT6 unit is now connected to the WiFi network.
INFO:  ---------------------------------
INFO:  | Test Case |       Description |
INFO:  ---------------------------------
INFO:  |      6000 | Temperature test. |
INFO:  ---------------------------------
INFO:  Checking the CT6 board temperature.
INFO:  CT6 board temperature = 20.7 °C
INFO:  ---------------------------
INFO:  | Test Case | Description |
INFO:  ---------------------------
INFO:  |      7000 |   LED test. |
INFO:  ---------------------------
INFO:  Is the green LED next to the WiFi switch flashing ? y/n
y
INFO:  Is the blue LED next to the reset switch flashing ? y/n
y
INFO:  ----------------------------
INFO:  | Test Case |  Description |
INFO:  ----------------------------
INFO:  |      8000 | Switch test. |
INFO:  ----------------------------
INFO:  Hold down the WiFi switch on the CT6 board.
INFO:  Checking serial connections for CT6 device.
INFO:  The WiFi switch is working. Release the WiFi switch.
INFO:  Press and release the reset switch on the CT6 board.
INFO:  The CT6 unit (192.168.0.19) has rebooted. Waiting for it to re register on the WiFi network.
INFO:  CT6 unit is now connected to the WiFi network.
INFO:  -----------------------------------------
INFO:  | Test Case |               Description |
INFO:  -----------------------------------------
INFO:  |      9000 | Power cycle circuit test. |
INFO:  -----------------------------------------
INFO:  Checking the power cycle feature on the CT6 board.
INFO:  Waiting for the CT6 unit  (192.168.0.19) to reboot.
INFO:  The CT6 unit (192.168.0.19) has rebooted. Waiting for it to re register on the WiFi network.
INFO:  CT6 unit is now connected to the WiFi network.
INFO:  -----------------------------
INFO:  | Test Case |   Description |
INFO:  -----------------------------
INFO:  |     10000 | Display test. |
INFO:  -----------------------------
INFO:  Is the display showing AC voltage ?
INPUT: Is the display showing the CT6 IP address y/n: y
INFO:  ------------------------------------------------------
INFO:  | Test Case |                            Description |
INFO:  ------------------------------------------------------
INFO:  |     11000 | Set assembly number and serial number. |
INFO:  ------------------------------------------------------
INFO:  Factory setup and calibration of CT6 unit (192.168.0.19).
INFO:  Reading configuration from 192.168.0.19
INFO:
INFO:  Setting assembly label to ASY0398_V001.600_SN00001823.
INFO:  Successfully set the unit serial number.
INFO:  --------------------------------------------
INFO:  | Test Case |                  Description |
INFO:  --------------------------------------------
INFO:  |     12000 | Perform calibration process. |
INFO:  --------------------------------------------
INFO:  Factory setup and calibration of 192.168.0.19
INFO:
INFO:  Ensure no AC load is connected.
INPUT: Connect an SCT013_100A current transformer (CT) to port 1 and press RETURN:
INFO:  Calibrating U5 VOLTAGE gain.
INFO:
INPUT: Enter the AC RMS voltage as measured by an external meter: 245.1
INFO:  AC Freq = 50 Hz
INFO:  Voltage gain = 50000
INFO:  Checking that CT1 detects at least 100 volts.
INFO:  Reading stats from 192.168.0.19
INFO:  Detected 219.62 volts.
INFO:  Reading stats from 192.168.0.19
INFO:  Read 219.60 Volts (error = 25.50 Volts)
INFO:  Voltage gain = 55806
INFO:  Reading stats from 192.168.0.19
INFO:  Read 245.00 Volts (error = 0.10 Volts)
INFO:  CT1 voltage calibration complete.
INFO:  Calibrating CT1 CURRENT gain.
INFO:
INPUT: Ensure an AC load drawing at least 5 amps is connected and press RETURN:
INFO:  Current gain = 8000
INFO:  Checking that CT1 detects at least 5 amps.
INFO:  Reading stats from 192.168.0.19
INFO:  Detected 8.641 amps.
INPUT: Enter the AC RMS current in amps as measured with an external meter: 11.46
INFO:  Reading configuration from 192.168.0.19
INFO:  Reading stats from 192.168.0.19
INFO:  Read 8.59 Amps (error = 2.87 Amps)
INFO:  Current gain = 10675
INFO:  Reading configuration from 192.168.0.19
INFO:  Reading stats from 192.168.0.19
INFO:  Read 11.45 Amps (error = 0.01 Amps)
INFO:
INFO:  CT1 current calibration complete.
INPUT: DISCONNECT the AC load and press RETURN:
INFO:  Calibrating CT1 CURRENT offset.
INFO:  Checking that CT1 load has been turned off.
INFO:  Reading stats from 192.168.0.19
INFO:  Current offset register = 0
INFO:  Reading stats from 192.168.0.19
INFO:  Detected a residual current of 0.001 amps.
INFO:  Current offset register = 64536
INFO:  Reading stats from 192.168.0.19
INFO:  Detected a residual current of 0.0 amps.
INFO:
INFO:  Ensure no AC load is connected.
INPUT: Connect an SCT013_100A current transformer (CT) to port 2 and press RETURN:
INFO:  Calibrating CT2 CURRENT gain.
INFO:
INPUT: Ensure an AC load drawing at least 5 amps is connected and press RETURN:
INFO:  Current gain = 8000
INFO:  Checking that CT2 detects at least 5 amps.
INFO:  Reading stats from 192.168.0.19
INFO:  Detected 8.667 amps.
INPUT: Enter the AC RMS current in amps as measured with an external meter: 11.43
INFO:  Reading configuration from 192.168.0.19
INFO:  Reading stats from 192.168.0.19
INFO:  Read 8.56 Amps (error = 2.87 Amps)
INFO:  Current gain = 10679
INFO:  Reading configuration from 192.168.0.19
INFO:  Reading stats from 192.168.0.19
INFO:  Read 11.43 Amps (error = 0.00 Amps)
INFO:
INFO:  CT2 current calibration complete.
INPUT: DISCONNECT the AC load and press RETURN:
INFO:  Calibrating CT2 CURRENT offset.
INFO:  Checking that CT2 load has been turned off.
INFO:  Reading stats from 192.168.0.19
INFO:  Current offset register = 0
INFO:  Reading stats from 192.168.0.19
INFO:  Detected a residual current of 0.001 amps.
INFO:  Current offset register = 64536
INFO:  Reading stats from 192.168.0.19
INFO:  Detected a residual current of 0.0 amps.
INFO:
INFO:  Ensure no AC load is connected.
INPUT: Connect an SCT013_100A current transformer (CT) to port 3 and press RETURN:
INFO:  Calibrating CT3 CURRENT gain.
INFO:
INPUT: Ensure an AC load drawing at least 5 amps is connected and press RETURN:
INFO:  Current gain = 8000
INFO:  Checking that CT3 detects at least 5 amps.
INFO:  Reading stats from 192.168.0.19
INFO:  Detected 8.63 amps.
INPUT: Enter the AC RMS current in amps as measured with an external meter: 11.41
INFO:  Reading configuration from 192.168.0.19
INFO:  Reading stats from 192.168.0.19
INFO:  Read 8.54 Amps (error = 2.87 Amps)
INFO:  Current gain = 10687
INFO:  Reading configuration from 192.168.0.19
INFO:  Reading stats from 192.168.0.19
INFO:  Read 11.41 Amps (error = 0.00 Amps)
INFO:
INFO:  CT3 current calibration complete.
INPUT: DISCONNECT the AC load and press RETURN:
INFO:  Calibrating CT3 CURRENT offset.
INFO:  Checking that CT3 load has been turned off.
INFO:  Reading stats from 192.168.0.19
INFO:  Current offset register = 0
INFO:  Reading stats from 192.168.0.19
INFO:  Detected a residual current of 0.001 amps.
INFO:  Current offset register = 64536
INFO:  Reading stats from 192.168.0.19
INFO:  Detected a residual current of 0.0 amps.
INFO:
INFO:  Ensure no AC load is connected.
INPUT: Connect an SCT013_100A current transformer (CT) to port 4 and press RETURN:
INFO:  Calibrating U4 VOLTAGE gain.
INFO:
INPUT: Enter the AC RMS voltage as measured by an external meter: 243.58
INFO:  AC Freq = 50 Hz
INFO:  Voltage gain = 50000
INFO:  Checking that CT4 detects at least 100 volts.
INFO:  Reading stats from 192.168.0.19
INFO:  Detected 219.45 volts.
INFO:  Reading stats from 192.168.0.19
INFO:  Read 219.55 Volts (error = 24.03 Volts)
INFO:  Voltage gain = 55472
INFO:  Reading stats from 192.168.0.19
INFO:  Read 243.42 Volts (error = 0.16 Volts)
INFO:  CT4 voltage calibration complete.
INFO:  Calibrating CT4 CURRENT gain.
INFO:
INPUT: Ensure an AC load drawing at least 5 amps is connected and press RETURN:
INFO:  Current gain = 8000
INFO:  Checking that CT4 detects at least 5 amps.
INFO:  Reading stats from 192.168.0.19
INFO:  Detected 8.716 amps.
INPUT: Enter the AC RMS current in amps as measured with an external meter: 11.44
INFO:  Reading configuration from 192.168.0.19
INFO:  Reading stats from 192.168.0.19
INFO:  Read 8.57 Amps (error = 2.87 Amps)
INFO:  Current gain = 10684
INFO:  Reading configuration from 192.168.0.19
INFO:  Reading stats from 192.168.0.19
INFO:  Read 11.44 Amps (error = 0.00 Amps)
INFO:
INFO:  CT4 current calibration complete.
INPUT: DISCONNECT the AC load and press RETURN:
INFO:  Calibrating CT4 CURRENT offset.
INFO:  Checking that CT4 load has been turned off.
INFO:  Reading stats from 192.168.0.19
INFO:  Current offset register = 0
INFO:  Reading stats from 192.168.0.19
INFO:  Detected a residual current of 0.001 amps.
INFO:  Current offset register = 64536
INFO:  Reading stats from 192.168.0.19
INFO:  Detected a residual current of 0.0 amps.
INFO:
INFO:  Ensure no AC load is connected.
INPUT: Connect an SCT013_100A current transformer (CT) to port 5 and press RETURN:
INFO:  Calibrating CT5 CURRENT gain.
INFO:
INPUT: Ensure an AC load drawing at least 5 amps is connected and press RETURN:
INFO:  Current gain = 8000
INFO:  Checking that CT5 detects at least 5 amps.
INFO:  Reading stats from 192.168.0.19
INFO:  Detected 8.652 amps.
INPUT: Enter the AC RMS current in amps as measured with an external meter: 11.44
INFO:  Reading configuration from 192.168.0.19
INFO:  Reading stats from 192.168.0.19
INFO:  Read 8.57 Amps (error = 2.87 Amps)
INFO:  Current gain = 10684
INFO:  Reading configuration from 192.168.0.19
INFO:  Reading stats from 192.168.0.19
INFO:  Read 11.43 Amps (error = 0.01 Amps)
INFO:
INFO:  CT5 current calibration complete.
INPUT: DISCONNECT the AC load and press RETURN:
INFO:  Calibrating CT5 CURRENT offset.
INFO:  Checking that CT5 load has been turned off.
INFO:  Reading stats from 192.168.0.19
INFO:  Current offset register = 0
INFO:  Reading stats from 192.168.0.19
INFO:  Detected a residual current of 0.001 amps.
INFO:  Current offset register = 64536
INFO:  Reading stats from 192.168.0.19
INFO:  Detected a residual current of 0.0 amps.
INFO:
INFO:  Ensure no AC load is connected.
INPUT: Connect an SCT013_100A current transformer (CT) to port 6 and press RETURN:
INFO:  Calibrating CT6 CURRENT gain.
INFO:
INPUT: Ensure an AC load drawing at least 5 amps is connected and press RETURN:
INFO:  Current gain = 8000
INFO:  Checking that CT6 detects at least 5 amps.
INFO:  Reading stats from 192.168.0.19
INFO:  Detected 8.661 amps.
INPUT: Enter the AC RMS current in amps as measured with an external meter: 11.46
INFO:  Reading configuration from 192.168.0.19
INFO:  Reading stats from 192.168.0.19
INFO:  Read 8.58 Amps (error = 2.88 Amps)
INFO:  Current gain = 10682
INFO:  Reading configuration from 192.168.0.19
INFO:  Reading stats from 192.168.0.19
INFO:  Read 11.46 Amps (error = 0.00 Amps)
INFO:
INFO:  CT6 current calibration complete.
INPUT: DISCONNECT the AC load and press RETURN:
INFO:  Calibrating CT6 CURRENT offset.
INFO:  Checking that CT6 load has been turned off.
INFO:  Reading stats from 192.168.0.19
INFO:  Current offset register = 0
INFO:  Reading stats from 192.168.0.19
INFO:  Detected a residual current of 0.001 amps.
INFO:  Current offset register = 64536
INFO:  Reading stats from 192.168.0.19
INFO:  Detected a residual current of 0.0 amps.
INFO:  Saving the factory configuration file to the CT6 unit.
INFO:  Get factory.cfg from 192.168.0.19.
INFO:  Save to factory.cfg from 192.168.0.19.
INFO:  Saved to /home/auser/test_logs/ASY0398_V01.6000_SN00001823_20240111063130_factory.cfg
INFO:  CT6 unit calibration successful.
INFO:  ----------------------------------------------
INFO:  | Test Case |                    Description |
INFO:  ----------------------------------------------
INFO:  |     13000 | Store CT6 configuration files. |
INFO:  ----------------------------------------------
INFO:  Get this.machine.cfg from 192.168.0.19.
INFO:  Save to this.machine.cfg from 192.168.0.19.
INFO:  Saved to /home/auser/test_logs/ASY0398_V01.6000_SN00001823_20240111063130_this.machine.cfg
INFO:  ---------------------------------------------------
INFO:  | Test Case |                         Description |
INFO:  ---------------------------------------------------
INFO:  |     14000 | Load factory default configuration. |
INFO:  ---------------------------------------------------
INFO:  Set factory CT6 WiFi.
INFO:  Took 422.2 seconds to test.
```

The CT6 unit is now ready for use. See the README.md file for more information on this.

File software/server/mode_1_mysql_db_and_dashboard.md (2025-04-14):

# Using the built in server apps.
The server apps may be installed onto a Linux or Windows machine as
detailed [here](installers/README.md). The following instructions details how to use the ct6_db_store to read and store data to a mysql database. The ct6_dash app can then be used to display the energy usage data stored in the database.

## Setup a MYSQL server
Before starting the apps a MYSQL database is required to store the data from CT6 units. Details of how the MYSQL
database can be setup on windows and Linux platforms can be found [here](install_docker_and_mysql.md).

## ct6_db_store app
This application is responsible for sending messages to CT6 devices on your LAN and saving the responses from CT6 devices to the MYSQL database.

The ct6_db_store app can be started from the command line on Windows (Powershell window) and
Linux (terminal window) platforms.

Before using the ct6_db_store app it must be configured to connect to the MYSQL database.
Start the ct6_db_store app with the -c command line option as shown below to configure
the required settings.

```
ct6_db_store -c

INFO:  Loaded config from /home/username/.ct6DBStore.cfg
INFO:  Saved config to /home/username/.ct6DBStore.cfg
INFO:  ID  PARAMETER           VALUE
INFO:  1   ICONS_ADDRESS       127.0.0.1
INFO:  2   ICONS_PORT          22
INFO:  3   ICONS_USERNAME
INFO:  4   ICONS_SSH_KEY_FILE  /home/username/.ssh/id_rsa
INFO:  5   MQTT_TOPIC          HOME/#
INFO:  6   DB_HOST             192.168.0.22
INFO:  7   DB_PORT             3306
INFO:  8   DB_USERNAME         root
INFO:  9   DB_PASSWORD         changeme
INPUT: Enter 'E' to edit a parameter, or 'Q' to quit:
```

ID's  1,2,3 and 4 can be left at the default values or unset. They are not currently used.

ID 5  Should be set to 'HOME/#'.

ID 6  Should be set to the IP address of the Windows or Linux machine on your LAN.

ID 7  This can be left at 3306 unless the MYSQL docker container is setup for a different port.

ID 8  The database username can be left as root

ID 9  Ensure the password is set to the password used when the mysql docker container was created.

Once this has been completed 'Q' should be entered to quit the ct6_db_tool app.

Once the above configuration is complete the ct6_db_store app must be started without the -c
command line argument as shown below.

```
ct6_db_store
INFO:  Loaded config from /home/username/.ct6DBStore.cfg
INFO:  Saved config to /home/username/.ct6DBStore.cfg
INFO:  Creating Hour and Day tables...
INFO:  Connecting to 192.168.0.22:3306
INFO:  Connected
INFO:  Deleted CT6_SENSOR_MINUTE database table.
INFO:  Deleted CT6_SENSOR_HOUR database table.
INFO:  Deleted CT6_SENSOR_DAY database table.
INFO:  Created CT6_SENSOR_MINUTE table in Meter_Cupboard.
INFO:  Created CT6_SENSOR_HOUR table in Meter_Cupboard.
INFO:  Created CT6_SENSOR_DAY table in Meter_Cupboard.
INFO:  Creating derived tables in Meter_Cupboard.
INFO:  Took 7.0 seconds to write CT6_SENSOR_MINUTE table in Meter_Cupboard
INFO:  Took 0.1 seconds to write CT6_SENSOR_HOUR table in Meter_Cupboard
INFO:  Took 0.0 seconds to write CT6_SENSOR_DAY table in Meter_Cupboard
INFO:  Created CT6_SENSOR_MINUTE_INDEX in Meter_Cupboard.
INFO:  Created CT6_SENSOR_HOUR_INDEX in Meter_Cupboard.
INFO:  Created CT6_SENSOR_DAY_INDEX in Meter_Cupboard.
INFO:  Took 9.0 seconds to create derived tables in Meter_Cupboard
INFO:  Derived tables created.
INFO:  Disconnected from 192.168.0.22:3306
INFO:  Connected to MySQL server.
INFO:  Sending AYT messages.
INFO:  Listening on UDP port 29340
INFO:  Found device on 192.168.0.34
```

The ct6_db_store is now storing data it receives from CT6 units. If multiple units are found they will be
stored in different databases. The name of each database will be the configured name of the CT6 device.

## ct6_dash app
Once the ct6_db_store app is running the ct6_dash (dashboard) app can be used to start a webserver that
provides GUI access to the data.

Before using the ct6_dash app it must be configured to connect to the MYSQL database.
Start the ct6_dash app with the -c command line options as shown below to configure
the required settings.

```
ct6_dash -c
INFO:  Loaded config from /home/username/.ct6Dash.cfg
INFO:  Saved config to /home/username/.ct6Dash.cfg
INFO:  ID  PARAMETER                 VALUE
INFO:  1   DB_HOST                   192.168.0.22
INFO:  2   DB_PORT                   3306
INFO:  3   DB_USERNAME               root
INFO:  4   DB_PASSWORD               changeme
INFO:  5   LOCAL_GUI_SERVER_ADDRESS  192.168.0.23
INFO:  6   LOCAL_GUI_SERVER_PORT     10000
INPUT: Enter 'E' to edit a parameter, or 'Q' to quit:
```

1 = The host address of the machine running the MYSQL database.

2 = The TCP port number to connect to the database.

3 = The username of the database.

4 = The password for access to the database.

5 = The address of the local machine on your LAN.

6 = The TCP port number to present the web server on.

Once this has been completed 'Q' should be entered to quit the ct6_dash app.

Once the above configuration is complete the ct6_dash app must be started without the -c
command line argument as shown below.

```
ct6_dash
INFO:  Loaded config from /home/username/.ct6Dash.cfg
INFO:  Saved config to /home/username/.ct6Dash.cfg
INFO:  Connected to MySQL server.
```

When the above command issued a local web browser will be automatically started and connected to the ct6_dash webserver.

ct6_dash

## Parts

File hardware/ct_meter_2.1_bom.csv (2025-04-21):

Comment | Designator | Footprint | MFR | Part | #
10uf 50v | C1 | Capacitor_SMD:C_1206_3216Metric | Electro-Mechanics | CL31A106KBHNNNE
4.7uf | C15,C32 | Capacitor_SMD:C_0603_1608Metric | Electro-Mechanics | CL10A475KO8NNNC
470uf 35v | C2 | Capacitor_THT:CP_Radial_D10.0mm_P5.00mm | Electronics | NXH35V470M10*165.0TP
10uf | C20,C22,C37 | Capacitor_SMD:C_0603_1608Metric | Electro-Mechanics | CL10A106KP8NNNC
DNF | C23,C40 | Capacitor_SMD:C_0603_1608Metric
0.1uf | C3 | Capacitor_SMD:C_0603_1608Metric_Pad1.08x0.95mm_HandSolder | YAGEO | CC0603KRX7R9BB104
47pf | C4 | Capacitor_SMD:C_0805_2012Metric_Pad1.18x1.45mm_HandSolder | Electro-Mechanics | CL21C470JBANNNC
47uf | C6 | Capacitor_THT:CP_Radial_D5.0mm_P2.00mm | Rubycon | 25PX47MEFC5X11
0.1uf | C7,C16,C18,C19,C21,C33,C35,C36,C38,C42 | Capacitor_SMD:C_0603_1608Metric | YAGEO | CC0603KRX7R9BB104
22nf | C8,C9,C10,C11,C12,C13,C14,C17,C25,C26,C27,C28,C29,C30,C31,C34 | Capacitor_SMD:C_0603_1608Metric | Electro-Mechanics | CL10B223KB8NNNC
1N4007 | D1 | Diode_SMD:D_SMA | TWGMC | 1N4007
BAT60A | D13 | Diode_SMD:D_SOD-323 | FUXINSEMI | BAT60B
BLUE LED | D2 | LED_SMD:LED_0603_1608Metric_Pad1.05x0.95mm_HandSolder | KENTO | KT-0603B
GREEN LED | D3,D4 | LED_SMD:LED_0603_1608Metric_Pad1.05x0.95mm_HandSolder | Everlight | 19-217/GHC-YR1S2/3T
RED LED | D5,D6,D7,D8,D9,D10,D11,D12 | LED_SMD:LED_0603_1608Metric_Pad1.05x0.95mm_HandSolder | KENTO | KT-0603R
Barrel_Jack_Switch | J1 | PJA_Connectors:DC_power_2.1mm_5.5mm | GANGYUAN | DC-470-2.1GP
Pico_W_Left_Row | J10 | PJA_RP_pico:RPi_Pico_SMD_TH_Left_Row | Cankemeng) | B-2200S20P-A120
Pico_W_Right_Row | J11 | PJA_RP_pico:RPi_Pico_SMD_TH_Right_Row | Cankemeng) | B-2200S20P-A120
2.54mm Plugin Gold 7P Brass Straight 1x7P Plugin,P=2.54mm Female Headers ROHS | J2 | Connector_PinHeader_2.54mm:PinHeader_1x07_P2.54mm_Vertical | Connectors) | A2541HWV-7P
Audio-Jack-2_Switch | J3,J4,J5,J6,J7,J8 | PJA_Connectors:Mono_3.5mm_audio_jack | Kinghelm Elec | KH-PJ-316-3P
DNF | J9 | Connector_PinHeader_2.54mm:PinHeader_2x20_P2.54mm_Vertical
DNF | JP1 | Connector_PinHeader_2.54mm:PinHeader_1x02_P2.54mm_Vertical
SolderJumper_2_Bridged | JP4,JP5,JP6,JP7,JP8,JP9 | Jumper:SolderJumper-2_P1.3mm_Bridged_RoundedPad1.0x1.5mm
6.8uh | L1 | PJA_Inductors:Sumida_CD43 | YJYCOIN | CD43YP0403-6R8M
2N7002 | Q1,Q2 | Package_TO_SOT_SMD:SOT-23 |  | 2N7002
100k | R1,R7,R29 | Resistor_SMD:R_0603_1608Metric | UNI-ROYAL(Uniroyal Elec) | 0603WAF1003T5E
47 | R12,R13,R14,R41,R42,R43 | Resistor_SMD:R_0603_1608Metric | UNI-ROYAL(Uniroyal Elec) | 0603WAF470JT5E
1k | R15,R16,R17,R18,R19,R20,R23,R44,R45,R46,R47,R48,R49,R52 | Resistor_SMD:R_0603_1608Metric | UNI-ROYAL(Uniroyal Elec) | 0603WAF1001T5E
56k | R21 | Resistor_SMD:R_0603_1608Metric | UNI-ROYAL(Uniroyal Elec) | 0603WAF5602T5E
680R | R22 | Resistor_SMD:R_0603_1608Metric | UNI-ROYAL(Uniroyal Elec) | 0603WAF6800T5E
10k | R2,R25,R28,R30,R50,R51,R56 | Resistor_SMD:R_0603_1608Metric | UNI-ROYAL(Uniroyal Elec) | 0603WAF1002T5E
DNF | R26,R27,R38,R39,R40,R55,R67,R68,R69 | Resistor_SMD:R_0603_1608Metric
2M2 | R3 | Resistor_SMD:R_0603_1608Metric | LIZ Elec | CR0603FA2204G
22k | R4,R5 | Resistor_SMD:R_0603_1608Metric | UNI-ROYAL(Uniroyal Elec) | 0603WAF2202T5E
0R | R6,R8,R24,R31,R32,R37,R66 | Resistor_SMD:R_0603_1608Metric | UNI-ROYAL(Uniroyal Elec) | 0603WAF0000T5E
470 | R9,R10,R11,R33,R34,R35,R36,R62,R63,R64,R65 | Resistor_SMD:R_0603_1608Metric | UNI-ROYAL(Uniroyal Elec) | 0603WAF4700T5E
WIFI | SW1 | PJA_Switches:switch_SPST_5mmx3mmx2.5mm | HCTL | TC-3601L-2.5-260G
RESET | SW2 | PJA_Switches:switch_SPST_5mmx3mmx2.5mm | HCTL | TC-3601L-2.5-260G
TPS54302 | U1 | Package_TO_SOT_SMD:SOT-23-6_Handsoldering | Texas Instruments | TPS54302DDCR
MCP9700 | U3 | Package_TO_SOT_SMD:SOT-23-3 | Microchip Tech | MCP9700T-E/TT
ATM90E32AS | U4,U5 | Package_QFP:TQFP-48_7x7mm_P0.5mm | Microchip Tech | ATM90E32AS-AU-R
16.384MHz | Y1,Y2 | Crystal:Crystal_HC18-U_Vertical | TAITIEN Elec | XIHCCLNANF-16.384000MHZ

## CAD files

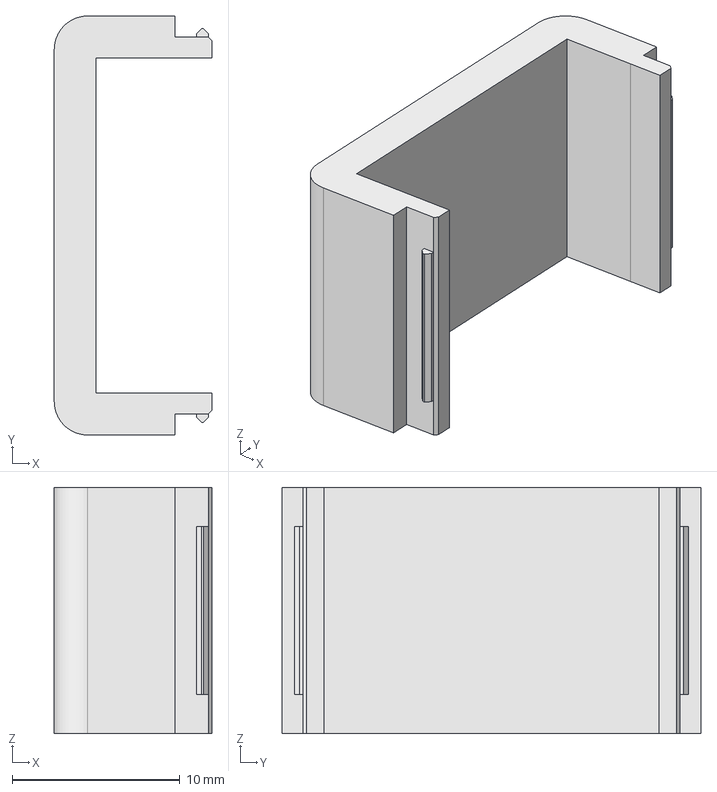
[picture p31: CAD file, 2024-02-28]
hardware/case/box_serial_port_cover.FCStd
9.40 x 25.0 x 14.7 mm

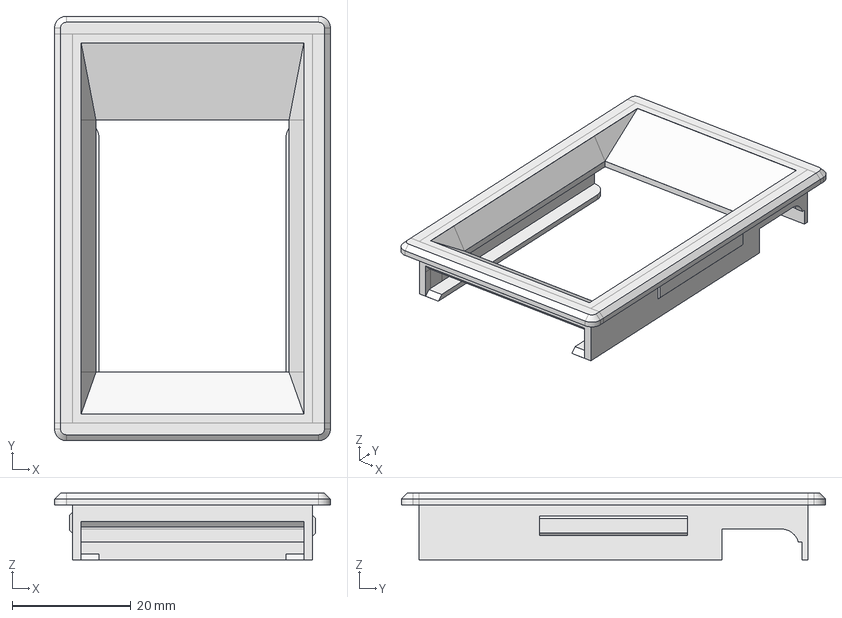
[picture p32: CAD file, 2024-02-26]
hardware/case/display_holder.FCStd
46.5 x 71.5 x 11.3 mm

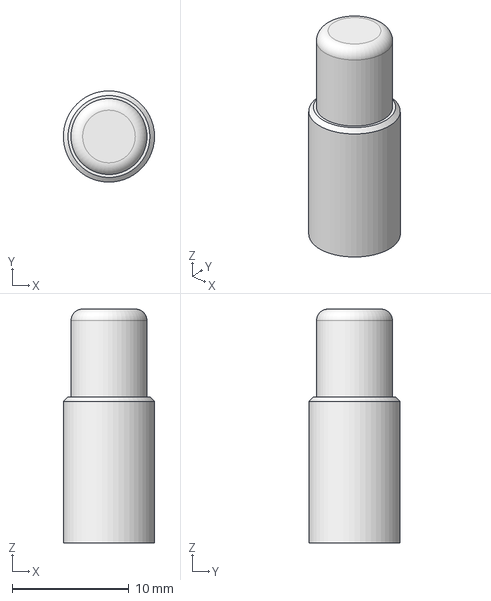
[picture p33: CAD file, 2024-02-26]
hardware/case/button.FCStd
7.79 x 7.80 x 20.0 mm

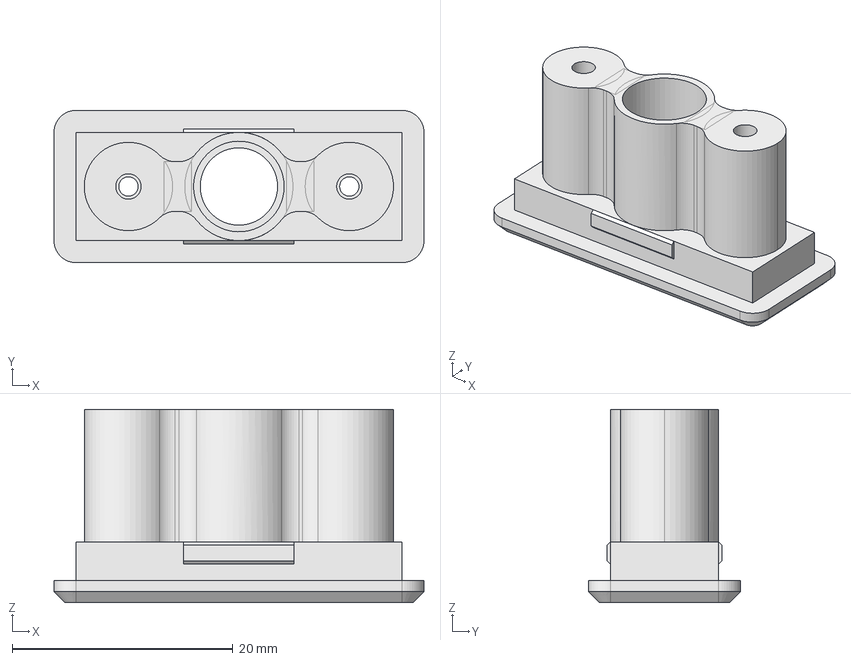
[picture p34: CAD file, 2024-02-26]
hardware/case/switch_and_led_plate.FCStd
33.5 x 13.8 x 17.5 mm

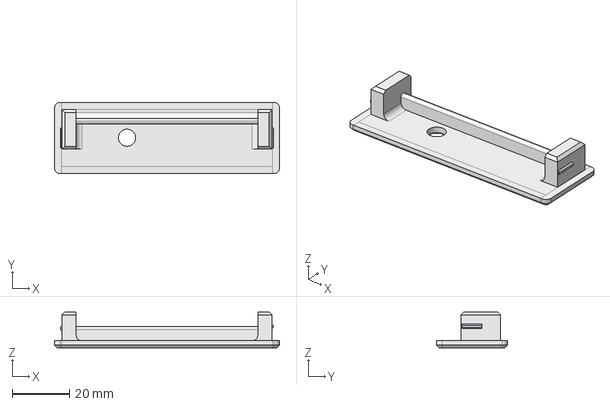
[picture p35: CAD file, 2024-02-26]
hardware/case/top.FCStd
78.8 x 25.0 x 12.5 mm

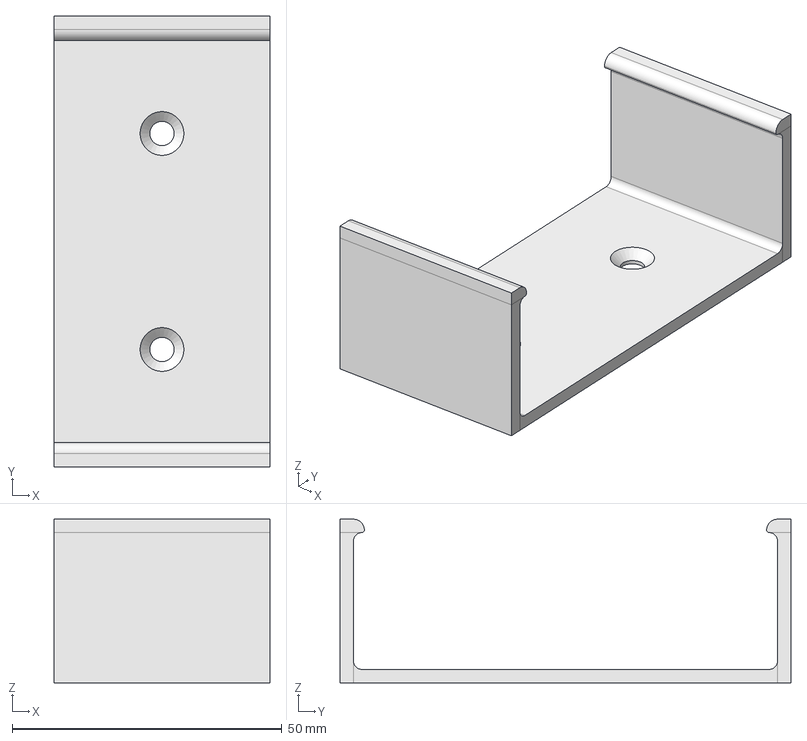
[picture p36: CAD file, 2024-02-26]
hardware/case/wall_bracket.FCStd
40.0 x 83.5 x 30.3 mm

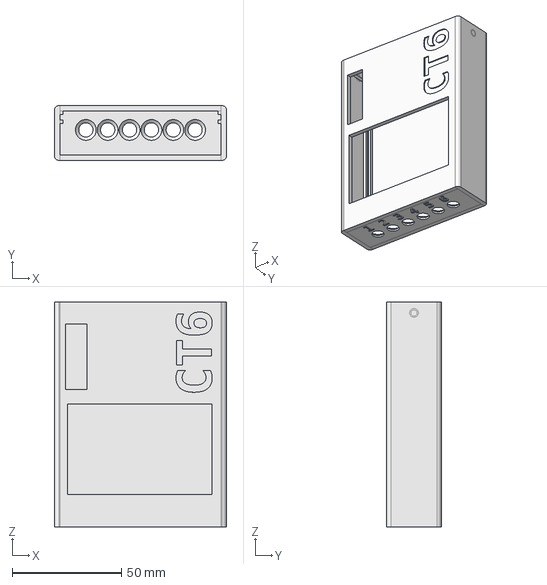
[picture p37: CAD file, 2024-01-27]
hardware/case/box.FCStd
78.8 x 25.0 x 103.0 mm

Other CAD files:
hardware/case/box.obj
hardware/case/box_serial_port_cover.obj
hardware/case/button.obj
hardware/case/display_holder.obj
hardware/case/switch_and_led_plate.obj
hardware/case/top.obj
hardware/case/wall_bracket.obj

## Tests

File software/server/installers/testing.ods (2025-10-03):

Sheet: v11.8
CT6 Testing
Version | 11.8
Date | 02/10/25
Linux Test Cases
Test Case | App | Description | Pass
1 | ct6_configurator | Check that Installing the CT6 unit with the latest MicroPython (1.1.26) works | Yes
Windows Test Cases
 | App | Description | Pass
2 | N/A | Windows Defender anti virus scan of repo | Yes
3 | ct6_configurator | Check that CT6 unit upgrade works. | Yes

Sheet: v11.7
CT6 Testing
Version | 11.7
Date | 19/05/25
Linux Test Cases
Test Case | App | Description | Pass
1 | ct6_dash | Check that latest dashboard appears | Yes
2 | ct6_app | Check that latest dashboard appears | Yes
Windows Test Cases
 | App | Description | Pass
3 | N/A | Windows Defender anti virus scan of repo | Yes
4 | ct6_dash | Check that latest dashboard appears | Yes

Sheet: v11.6
CT6 Testing
Version | 11.6
Date | 13/05/25
Linux Test Cases
Test Case | App | Description | Pass
1 | ct6_configurator | Check ability to setup CT6 WiFi using blue tooth interface. | Yes
2 | ct6_configurator | Check ability to upgrade a CT6 device over WiFi. | Yes
Windows Test Cases
 | App | Description | Pass
3 | N/A | Windows Defender anti virus scan of repo | Yes
4 | ct6_configurator | Check ability to setup CT6 WiFi using blue tooth interface. | Yes
5 | ct6_configurator | Check ability to upgrade a CT6 device over WiFi. | Yes

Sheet: v11.5
CT6 Testing
Version | 11.5
Date | 04/05/25
Linux Test Cases
Test Case | App | Description | Pass
1 | ct6_dash | Check program starts up and shows the program version as 11.5 | Yes
2 | ct6_dash | Check program starts up and shows imported energy as +ve values. | Yes
Windows Test Cases
 | App | Description | Pass
3 | N/A | Windows Defender anti virus scan of repo | Yes
4 | ct6_dash | Check program starts up and shows imported energy as +ve values. | Yes

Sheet: v11.4
CT6 Testing
Version | 11.4
Date | 26/04/25
Linux Test Cases
Test Case | App | Description | Pass
1 | ct6_configurator | Check program starts up and shows the program version as 11.4 | Yes
2 | ct6_dash | Check program starts up and shows data from a mysql database. | Yes
3 | ct6_app | Check program starts up and shows data from a sqlite database. | Yes
Windows Test Cases
 | App | Description | Pass
4 | N/A | Windows Defender anti virus scan of repo | Yes
5 | ct6_configurator | Check program starts up and shows the program version as 11.4 | Yes
6 | ct6_dash | Check program starts up and shows data from a mysql database. | Yes
7 | ct6_app | Check program starts up and shows data from a sqlite database. | Yes

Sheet: v11.2
CT6 Testing
Version | 11.2
Date | 21/04/25
Linux Test Cases
Test Case | App | Description | Pass
1 | ct6_configurator | Check program starts up and shows the program version as 11.2 | Yes
2 | ct6_dash | Check program starts up and shows the program version as 11.2 | Yes
3 | ct6_app | Check program starts up and shows the program version as 11.2 | Yes
Windows Test Cases
 | App | Description | Pass
4 | N/A | Windows Defender anti virus scan of repo | Yes
5 | ct6_configurator | Check program starts up and shows the program version as 11.2 | Yes
6 | ct6_dash | Check program starts up and shows the program version as 11.2 | Yes
7 | ct6_app | Check program starts up and shows the program version as 11.2 | Yes
8 | ct6_dash_mgr | Check program starts up | Yes

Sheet: v11.1
CT6 Testing
Version | 11.1
Date | 21/04/25
Linux Test Cases
Test Case | App | Description | Pass
1 | ct6_mfg_tool | Ensure a MFG test passes on a CT6 PCB | Yes
Windows Test Cases
 | App | Description | Pass
2 | N/A | Windows Defender anti virus scan of repo | Yes
3 | ct6_configurator | Check tool starts up | Yes

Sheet: v11.0
CT6 Testing
Version | 11
Date | 17/04/25
Linux Test Cases
Test Case | App | Description | Pass
1 | ct6_configurator | Install CT6 device | Yes
2 | ct6_configurator | Set WiFi config (via bluetooth) | Yes
3 | ct6_configurator | Set WiFi config (using USB port) | Yes
4 | ct6_configurator | Upgrade CT6 device over WiFi and check for FW version message | Yes
5 | ct6_configurator | Set CT6 device name | Yes
6 | ct6_configurator | Set CT6 device ports | Yes
7 | ct6_configurator | Set CT6 device MQTT configuration | Yes
8 | ct6_configurator | Set CT6 device active State | Yes
9 | ct6_configurator | Scan for CT6 devices | Yes
10 | ct6_configurator | Reboot a CT6 device remotely | Yes
Windows Test Cases
 | App | Description | Pass
11 | N/A | Windows Defender anti virus scan of repo | Yes
12 | ct6_configurator | Install CT6 device | Yes
13 | ct6_configurator | Set WiFi config (via bluetooth) | Yes
14 | ct6_configurator | Set WiFi config (using USB port) | Yes
15 | ct6_configurator | Upgrade CT6 device over WiFi and check for FW version message | Yes
16 | ct6_configurator | Set CT6 device name | Yes
17 | ct6_configurator | Set CT6 device ports | Yes
18 | ct6_configurator | Set CT6 device MQTT configuration | Yes
19 | ct6_configurator | Set CT6 device active State | Yes
20 | ct6_configurator | Scan for CT6 devices | Yes
21 | ct6_configurator | Reboot a CT6 device remotely | Yes

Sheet: v10.8
CT6 Testing
Date | 19/03/25
Linux Test Cases
Test Case | App | Description | Pass
1 | ct6_configurator | Install CT6 device | Yes
2 | ct6_configurator | Set WiFi config (via bluetooth) | Yes
3 | ct6_configurator | Set WiFi config (using USB port) | Yes
4 | ct6_configurator | Upgrade CT6 device over WiFi and check for FW version message | Yes
5 | ct6_configurator | Set CT6 device name | Yes
6 | ct6_configurator | Set CT6 device ports | Yes
7 | ct6_configurator | Set CT6 device MQTT configuration | Yes
8 | ct6_configurator | Set CT6 device active State | Yes
9 | ct6_configurator | Scan for CT6 devices | Yes
10 | ct6_configurator | Reboot a CT6 device remotely | Yes
11 | ct6_app | Check that it starts recording data and the GUI is available to view the data | Yes
Windows Test Cases
 | App | Description | Pass
12 | N/A | Windows Defender anti virus scan of repo | Yes
13 | ct6_configurator | Install CT6 device | Yes
14 | ct6_configurator | Set WiFi config (via bluetooth) | Yes
15 | ct6_configurator | Set WiFi config (using USB port) | Yes
16 | ct6_configurator | Upgrade CT6 device over WiFi and check for FW version message | Yes
17 | ct6_configurator | Set CT6 device name | Yes
18 | ct6_configurator | Set CT6 device ports | Yes
19 | ct6_configurator | Set CT6 device MQTT configuration | Yes
20 | ct6_configurator | Set CT6 device active State | Yes
21 | ct6_configurator | Scan for CT6 devices | Yes
22 | ct6_configurator | Reboot a CT6 device remotely | Yes
23 | ct6_app | Check that it starts recording data and the GUI is available to view the data | Yes

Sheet: v10.3
CT6 Testing
Date | 19/03/25
Linux Test Cases
Test Case | App | Description | Pass
1 | ct6_configurator | Install CT6 device | Yes
2 | ct6_configurator | Set WiFi config | Yes
3 | ct6_configurator | Upgrade CT6 device over WiFi and check for FW version message | Yes
4 | ct6_configurator | Set CT6 device name | Yes
5 | ct6_configurator | Set CT6 device ports | Yes
6 | ct6_configurator | Set CT6 device MQTT configuration | Yes
7 | ct6_configurator | Set CT6 device active State | Yes
8 | ct6_configurator | Scan for CT6 devices | Yes
9 | ct6_configurator | Reboot a CT6 device remotely | Yes
10 | ct6_configurator | Calibrate voltage (old test system) | Yes
11 | ct6_configurator | Calibrate current on port 1 (old test system) | Yes
12 | ct6_configurator | Calibrate voltage (high accuracy test system) | Yes
13 | ct6_configurator | Calibrate current on port 1 (high accuracy test system) | Yes
Windows Test Cases
 | App | Description | Pass
14 | N/A | Windows Defender anti virus scan of repo | Yes
15 | ct6_configurator | Install CT6 device | Yes
16 | ct6_configurator | Set WiFi config | Yes
17 | ct6_configurator | Upgrade CT6 device over WiFi and check for FW version message | Yes
18 | ct6_configurator | Set CT6 device name | Yes
19 | ct6_configurator | Set CT6 device ports | Yes
20 | ct6_configurator | Set CT6 device MQTT configuration | Yes
21 | ct6_configurator | Set CT6 device active State | Yes
22 | ct6_configurator | Scan for CT6 devices | Yes
23 | ct6_configurator | Reboot a CT6 device remotely | Yes

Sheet: v10.2
CT6 Testing
Date | 05/03/25
Linux Test Cases
Test Case | App | Description | Pass
1 | ct6_stats | Check tool reports JSON stats from all CT6 on LAN. | Yes
Windows Test Cases
 | App | Description | Pass
1 | N/A | Windows Defender anti virus scan of repo | Yes
2 | ct6_stats | Check ct6_stats is not supported on Windows platforms. | Yes

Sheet: v10.1_2
CT6 Testing
Date | 28/02/25
Linux Test Cases
Test Case | App | Description | Pass
1 | ct6_configurator | Upgrade CT6 device over WiFi and check for FW version message | Yes
2 | N/A | Check DB updated after upgrade | Yes
3 | n/A | Check for valid MQTT server stats messages after upgrade. | Yes
4 | n/A | Remove factory.cfg file on CT6 and check uncalibrated msg is displayed. | Yes
Windows Test Cases
 | App | Description | Pass
1 | N/A | Windows Defender anti virus scan of repo | Yes

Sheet: v10.0
CT6 Testing
Date | 28/02/25
Linux Test Cases
Test Case | App | Description | Pass
1 | ct6_configurator | Install CT6 device | Yes
2 | ct6_configurator | Set WiFi config | Yes
3 | ct6_configurator | Upgrade CT6 device over WiFi and check for FW version message | Yes
4 | ct6_configurator | Set CT6 device name | Yes
5 | ct6_configurator | Set CT6 device ports | Yes
6 | ct6_configurator | Set CT6 device MQTT configuration | Yes
7 | ct6_configurator | Set CT6 device active State | Yes
8 | ct6_configurator | Scan for CT6 devices | Yes
9 | ct6_configurator | Reboot a CT6 device remotely | Yes
Windows Test Cases
 | App | Description | Pass
1 | N/A | Windows Defender anti virus scan of repo | Yes
2 | ct6_configurator | Install CT6 device | Yes
3 | ct6_configurator | Set WiFi config | Yes
4 | ct6_configurator | Upgrade CT6 device over WiFi and check for FW version message | Yes
5 | ct6_configurator | Set CT6 device name | Yes
6 | ct6_configurator | Set CT6 device ports | Yes
7 | ct6_configurator | Set CT6 device MQTT configuration | Yes
8 | ct6_configurator | Set CT6 device active State | Yes
9 | ct6_configurator | Scan for CT6 devices | Yes
10 | ct6_configurator | Reboot a CT6 device remotely | Yes

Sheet: v9.9
CT6 Testing
Date | 01/03/25
Linux Test Cases
Test Case | App | Description | Pass
1 | ct6_configurator | Install CT6 device | Yes
2 | ct6_configurator | Set WiFi config | Yes
3 | ct6_configurator | Upgrade CT6 device over WiFi and check for FW version message | Yes
4 | ct6_configurator | Set CT6 device name | Yes
5 | ct6_configurator | Set CT6 device ports | Yes
6 | ct6_configurator | Set CT6 device MQTT configuration | Yes
7 | ct6_configurator | Set CT6 device active State | Yes
8 | ct6_configurator | Scan for CT6 devices | Yes
9 | ct6_configurator | Reboot a CT6 device remotely | Yes
Windows Test Cases
 | App | Description | Pass
1 | N/A | Windows Defender anti virus scan of repo | Yes
2 | ct6_configurator | Install CT6 device | Yes
3 | ct6_configurator | Set WiFi config | Yes
4 | ct6_configurator | Upgrade CT6 device over WiFi and check for FW version message | Yes
5 | ct6_configurator | Set CT6 device name | Yes
6 | ct6_configurator | Set CT6 device ports | Yes
7 | ct6_configurator | Set CT6 device MQTT configuration | Yes
8 | ct6_configurator | Set CT6 device active State | Yes
9 | ct6_configurator | Scan for CT6 devices | Yes
10 | ct6_configurator | Reboot a CT6 device remotely | Yes
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

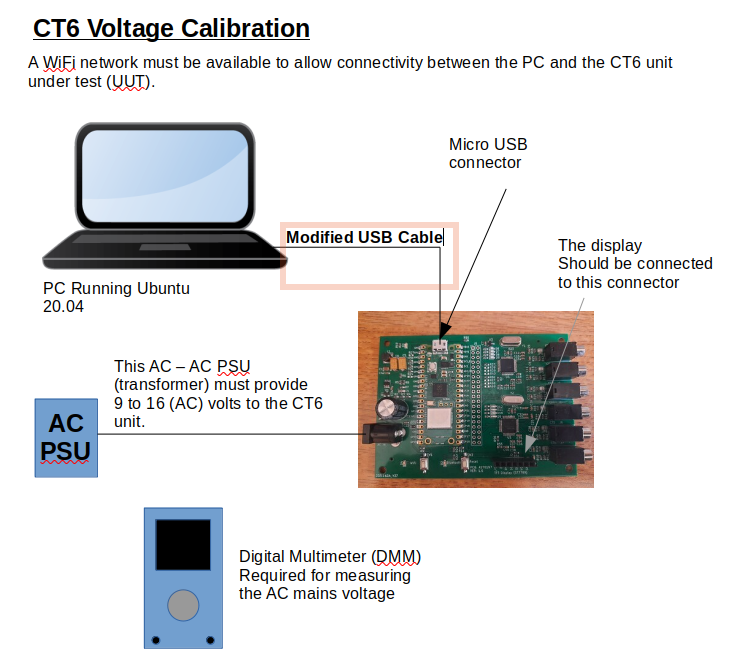
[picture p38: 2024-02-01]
software/server/images/calibrate_ac_voltage.png

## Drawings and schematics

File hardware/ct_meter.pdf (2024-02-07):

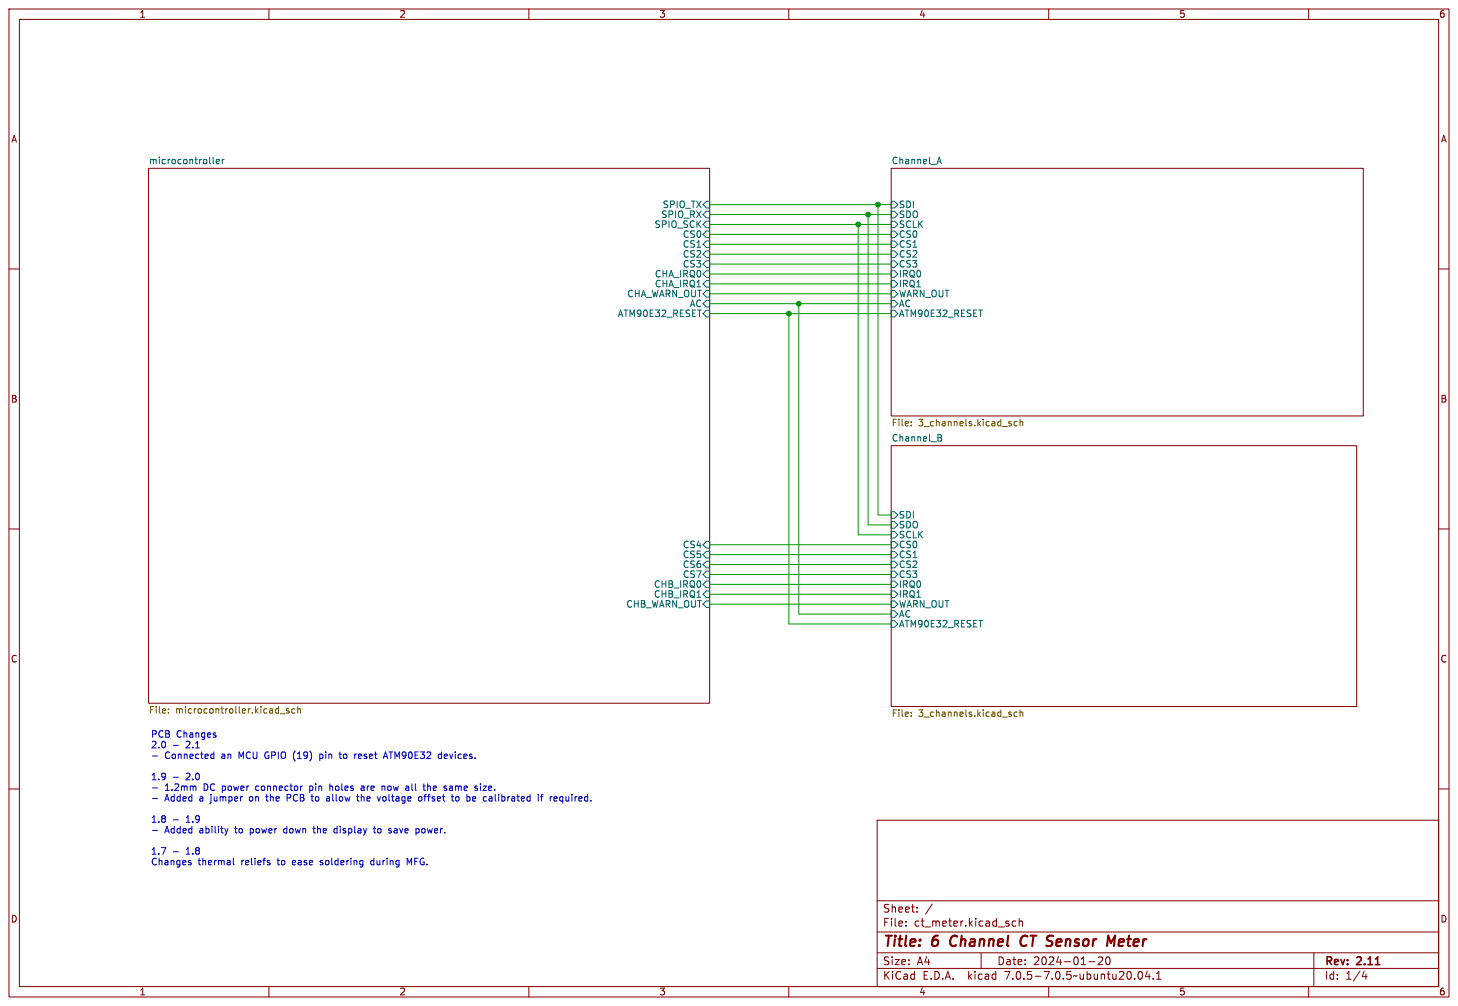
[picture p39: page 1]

SPIO_TX
SPIO_RX
Id: 1/4 Title: 6 Channel CT Sensor Meter File: ct_meter.kicad_sch Sheet: / CS4 CS5 CS6 SPIO_SCK

- Connected an MCU GPIO (19) pin to reset ATM90E32 devices. 1.9 - 2.0

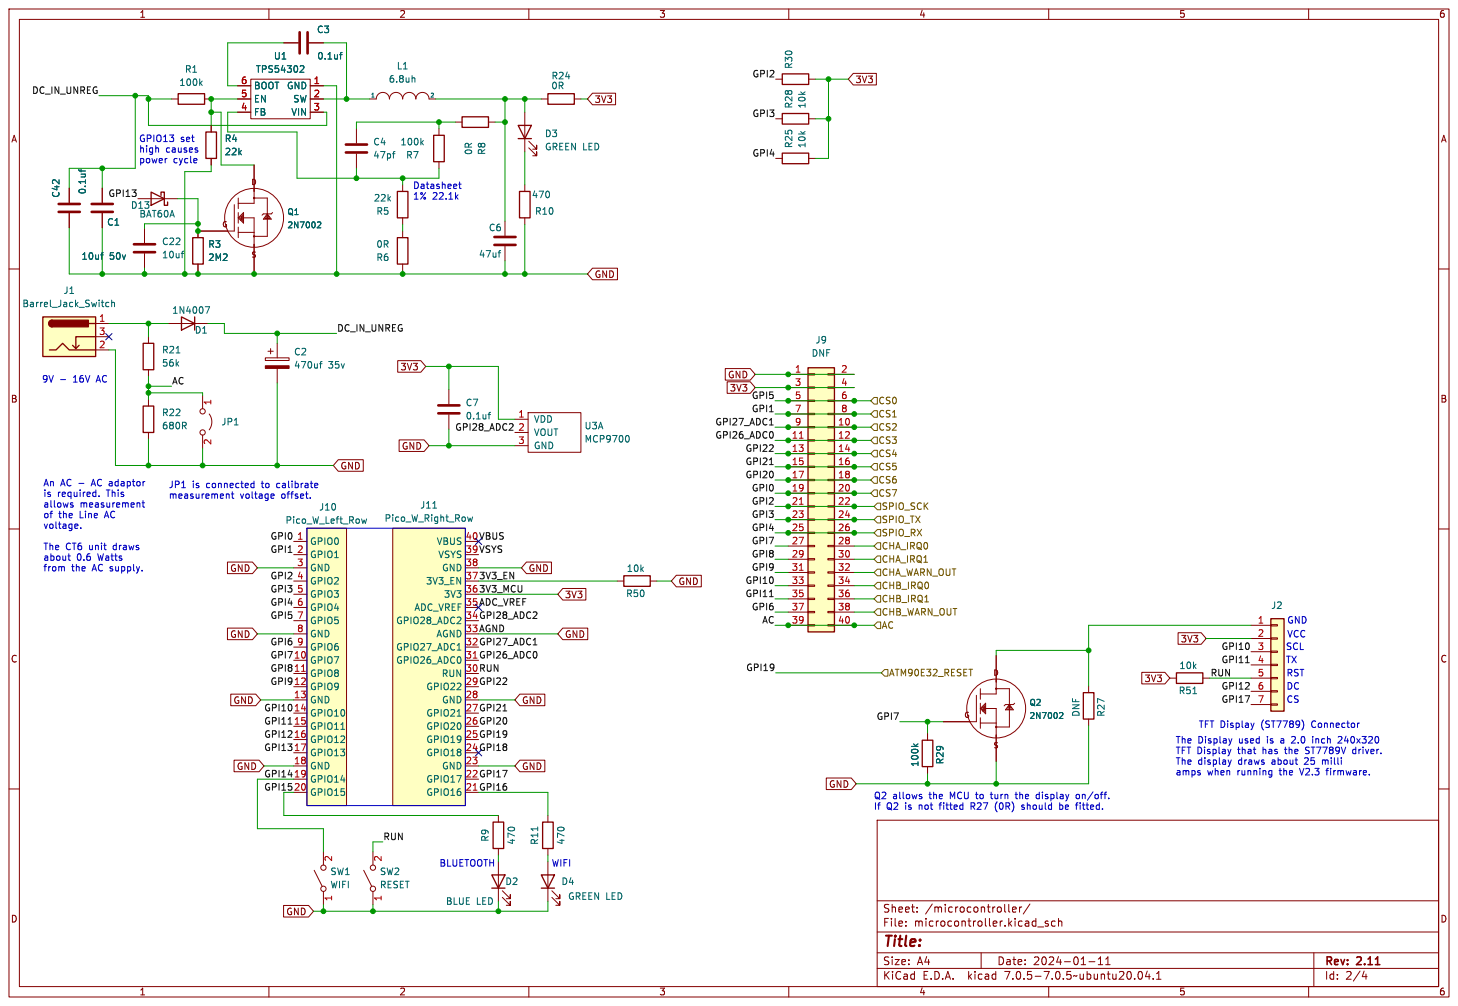
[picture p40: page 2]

GPIO13 set high causes power cycle

3V3 GND GND GND GND

An AC - AC adaptor

voltage. The CT6 unit draws about 0.6 Watts

Id: 2/4 Title: File: microcontroller.kicad_sch Sheet: /microcontroller/

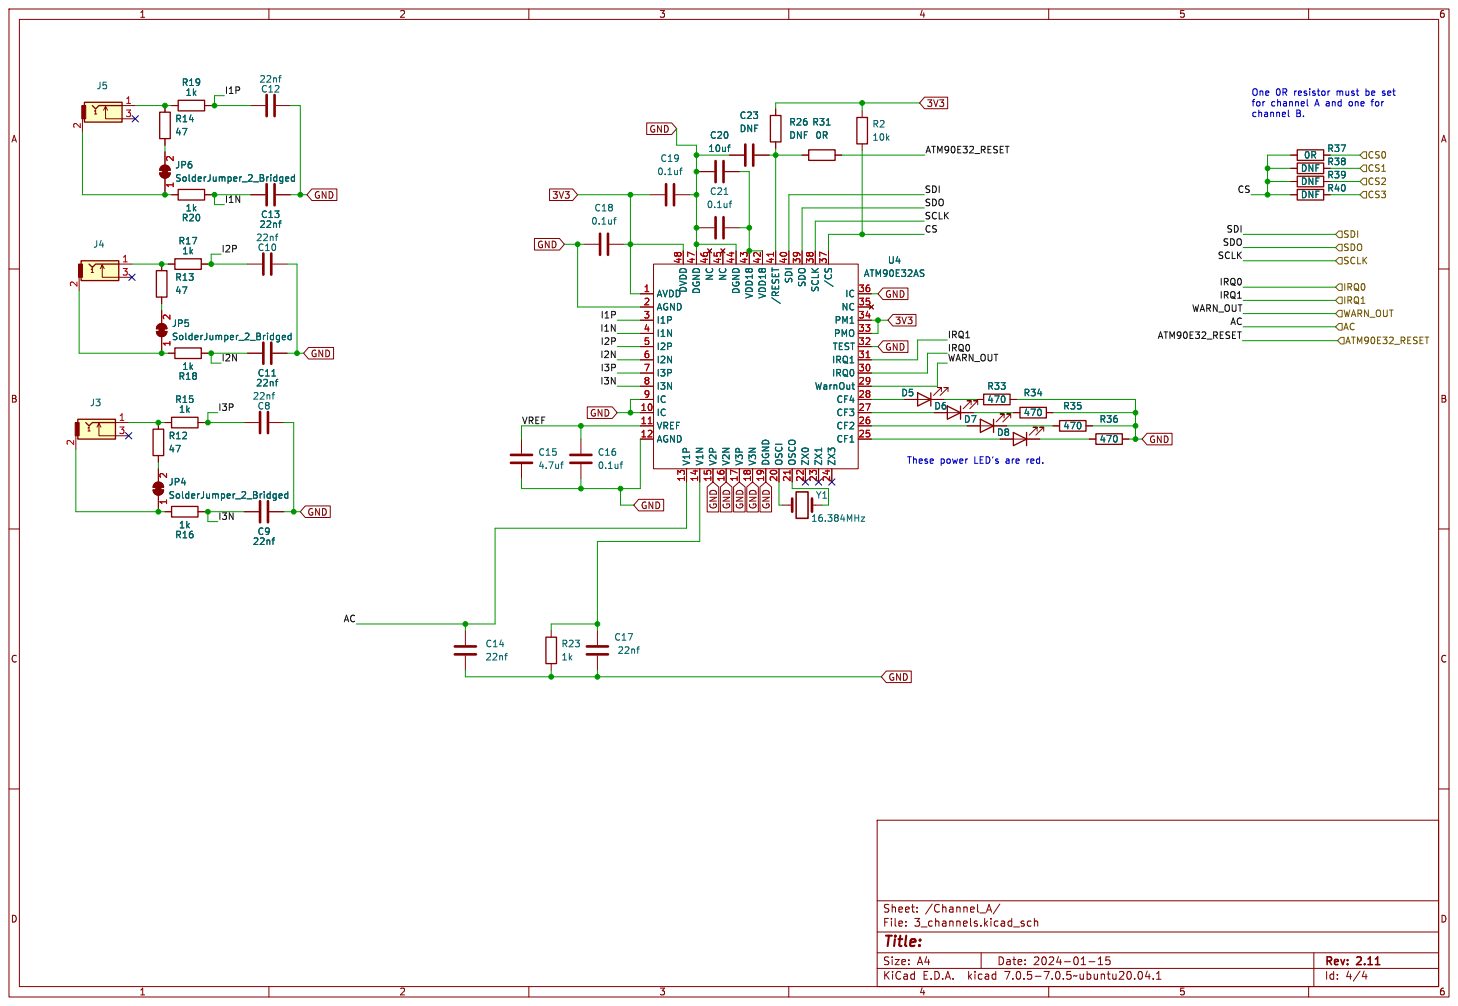
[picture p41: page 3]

for channel A and one for channel B. These power LED's are red. R16
0.1uf 1 2 JP6 SolderJumper_2_Bridged R14

Id: 4/4 Title: File: 3_channels.kicad_sch Sheet: /Channel_A/

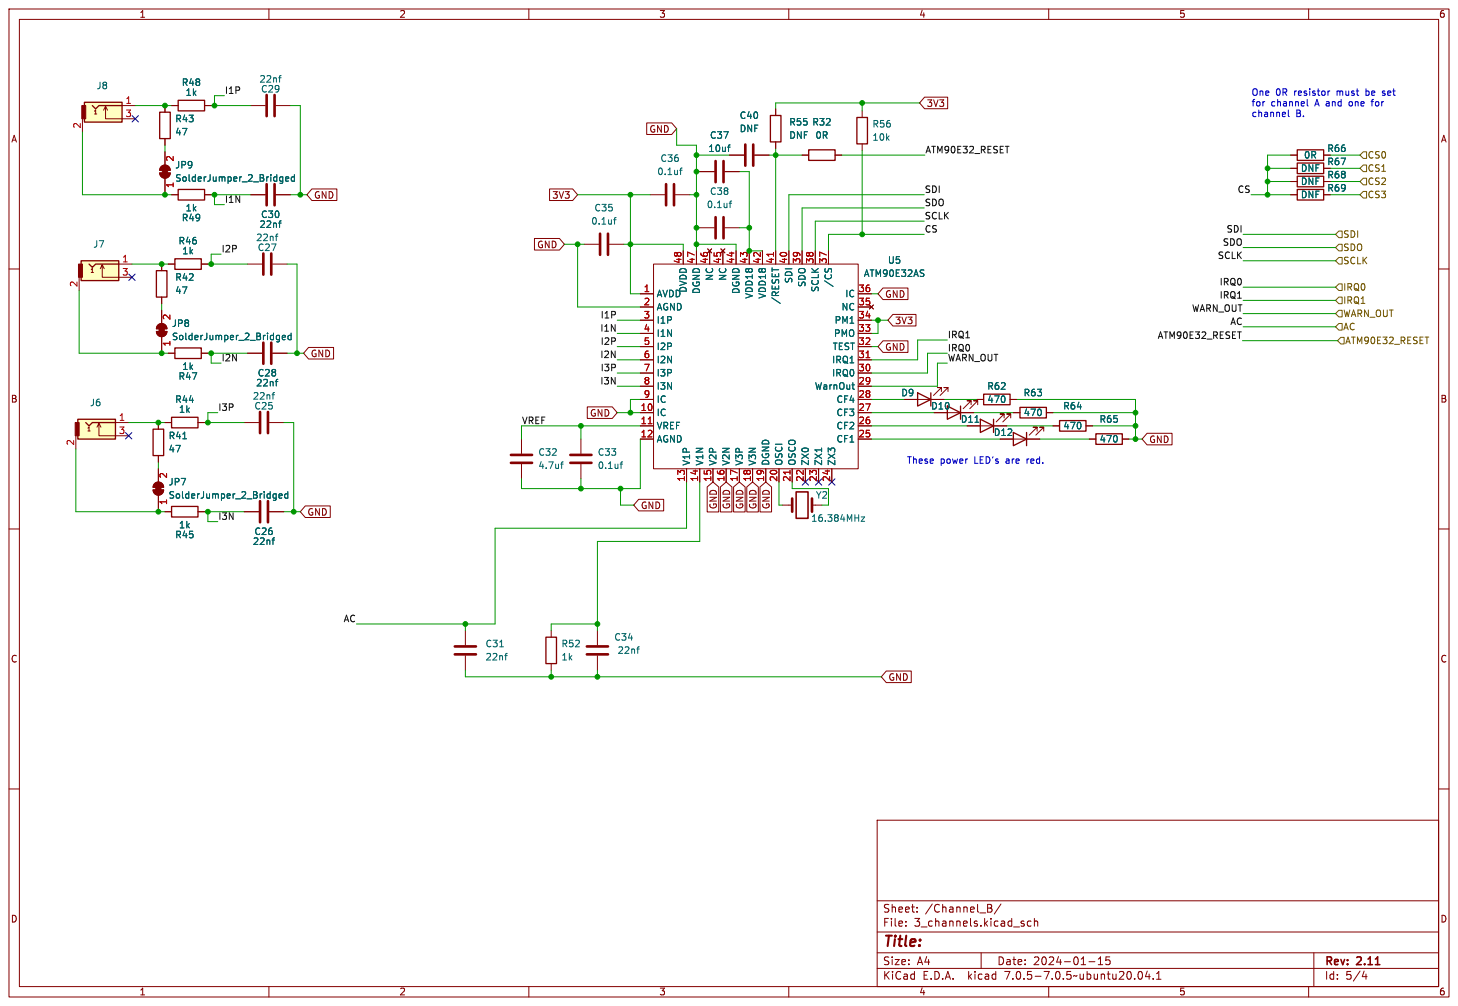
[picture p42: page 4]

22nf 1 2 JP9 SolderJumper_2_Bridged R48
for channel A and one for channel B. These power LED's are red. R45
JP9 SolderJumper_2_Bridged

Id: 5/4 Title: File: 3_channels.kicad_sch Sheet: /Channel_B/

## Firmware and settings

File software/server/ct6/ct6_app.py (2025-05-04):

#!/usr/bin/env python3
# -*- coding: UTF-8 -*-

import os
import argparse
import sqlite3
import threading
import shutil

from time import time, sleep

import mysql.connector

from p3lib.uio import UIO
from p3lib.boot_manager import BootManager
from p3lib.helper import logTraceBack

from lib.config import ConfigBase
from lib.yview import YViewCollector, LocalYViewCollector

from ct6.ct6_dash_mgr import CRED_JSON_FILE

from ct6.ct6_app_gui import AppConfig, SQLite3DBClient, GUI


class MYSQLImporter(object):
    """@brief Responsible for the conversion of CT6 mysql databases to CT6 sqlite databases."""

    MYSQL_CONFIG_FILENAME = "mysql.cfg"

    DEFAULT_MYSQL_CONFIG = {
        ConfigBase.DB_HOST: "",
        ConfigBase.DB_PORT: 3306,
        ConfigBase.DB_USERNAME: ""
    }

    VALID_CT6_DB_TABLE_NAMES = ('CT6_META',
                                'CT6_SENSOR',
                                'CT6_SENSOR_MINUTE',
                                'CT6_SENSOR_HOUR',
                                'CT6_SENSOR_DAY')

    def __init__(self, uio, options, config):
        """@brief Constructor
           @param uio A UIO instance
           @param options The command line options instance
           @param config An AppConfig instance.
           @param db_client An SQLite3DBClient instance."""
        self._uio = uio
        self._options = options
        self._config = config

    def _get_ct6_db_list(self, mysql_cursor):
        """@return A list of CT6 databases on the mysql server."""
        ct6_db_list = []
        cmd = 'SHOW DATABASES;'
        mysql_cursor.execute(cmd)
        db_list = mysql_cursor.fetchall()
        for db in db_list:
            db_name = db[0]
            cmd = f'USE {db_name};'
            mysql_cursor.execute(cmd)

            cmd = 'SHOW TABLES;'
            mysql_cursor.execute(cmd)
            table_list = mysql_cursor.fetchall()
            valid_table_names = True
            for table in table_list:
                table_name = table[0]
                if table_name not in MYSQLImporter.VALID_CT6_DB_TABLE_NAMES:
                    valid_table_names = False
                    break
            if valid_table_names:
                ct6_db_list.append(db_name)
        return ct6_db_list

    def _get_mysql_attr(self):
        """@brief Get a list of the my sql database attributes required.
           @return A tuple containing.
                   0 = host
                   1 = port
                   2 = username
                   4 = password"""
        # The host, port and username are saved persistently
        mysql_config = AppConfig(self._uio, SQLite3DBClient.GetConfigPathFile(MYSQLImporter.MYSQL_CONFIG_FILENAME) , MYSQLImporter.DEFAULT_MYSQL_CONFIG)
        mysql_config.configure(editConfigMethod=mysql_config.edit,
                               prompt="Enter 'E' to edit a parameter, or 'C' to continue",
                               quitCharacters= 'C')
        host = mysql_config.getAttr(ConfigBase.DB_HOST)
        port = mysql_config.getAttr(ConfigBase.DB_PORT)
        username = mysql_config.getAttr(ConfigBase.DB_USERNAME)
        # But the user must enter the MYSQL server password every time.
        password = self._uio.getInput("Enter the password for the MYSQL server")
        return (host, port, username, password)

    def _get_sqlite_database_file(self, mysql_db_name, mysql_cursor, imported=False):
        """@brief Get a list of the sqlite database files.
           @param mysql_database_files A list of the mysql database files.
           @param mysql_cursor A cursor connected to the mysql database.
           @param imported If True add '.imported' to the filename.
           @return The sqlite database file or None if not found."""
        db_storage_folder = self._config.getAttr(AppConfig.DB_STORAGE_PATH)
        sqlite_db_file = None
        cmd = f'USE {mysql_db_name};'
        mysql_cursor.execute(cmd)
        cmd = f'SELECT HW_ASSY FROM {MYSQLImporter.VALID_CT6_DB_TABLE_NAMES[0]};'
        mysql_cursor.execute(cmd)
        response = mysql_cursor.fetchall()
        if len(response) > 0:
            hw_assy = response[0][0]
            sqlite_db_name = hw_assy + ".db"
            if imported:
                sqlite_db_name = sqlite_db_name + ".imported"
            sqlite_db_file = os.path.join(db_storage_folder,
                                          sqlite_db_name)
        return sqlite_db_file

    def convert_mysql_to_sqlite(self):
        """@brief Connect to a my database and import all CT6 databases into sqlite"""
        self._uio.info("- Enter the mysql configuration below.")
        self._uio.info("- Then enter 'Q' to continue.\n")
        host, port, username, password = self._get_mysql_attr()

        mysql_conn = None
        mysql_cursor = None
        start_time = time()
        try:
            mysql_conn = mysql.connector.connect(host=host, port=port, user=username, password=password)
            mysql_cursor = mysql_conn.cursor()
            self._uio.info("Connected to MySQL DB.")

            mysql_server_ct6_db_list = self._get_ct6_db_list(mysql_cursor)

            # Check that none of the sqlite database files exist before we start
            # The user must delete these manually if they wish to create them.
            # We check this first as it may take some time to convert files and we
            # want to let the user know now if a files already exists which will
            # stop the conversion process.
            for mysql_server_ct6_db in mysql_server_ct6_db_list:
                db_file = self._get_sqlite_database_file(mysql_server_ct6_db, mysql_cursor, imported=False)
                if db_file and os.path.isfile(db_file):
                    raise Exception(f"The {db_file} sqlite database file already exists.")

                db_file = self._get_sqlite_database_file(mysql_server_ct6_db, mysql_cursor, imported=True)
                if db_file and os.path.isfile(db_file):
                    raise Exception(f"The {db_file} sqlite database file already exists.")

            for mysql_server_ct6_db in mysql_server_ct6_db_list:
                # This takes the mysql database and creates the *.db.imported file
                self._convert_database(mysql_server_ct6_db, mysql_cursor)

        finally:
            if mysql_cursor:
                mysql_cursor.close()
            if mysql_conn:
                mysql_conn.close()
        elapsed_seconds = int(time() - start_time)
        hms_str = self.seconds_to_hms(elapsed_seconds)
        self._uio.info(f"Took {hms_str} (HH:MM:SS) to import the CT6 MYSQL databases.")

    def seconds_to_hms(self, seconds):
        hours = seconds // 3600
        minutes = (seconds % 3600) // 60
        secs = seconds % 60
        return f"{hours:02}:{minutes:02}:{secs:02}"

    def _convert_database(self, db_name, mysql_cursor):
        """@brief Convert the CT6 mysql database to an sqlite database.
           @param db_name The name of the mysql database.
           @param mysql_cursor The cursor connected to the mysql database."""
        imported_sqlite_db_file = self._get_sqlite_database_file(db_name, mysql_cursor, imported=True)
        self._copy_mysql_to_sqlite_db(mysql_cursor, imported_sqlite_db_file)
        self.create_timestamp_index(imported_sqlite_db_file, MYSQLImporter.VALID_CT6_DB_TABLE_NAMES[1])
        self.add_unit_name_column(imported_sqlite_db_file, db_name)
        sqlite_db_file = self._get_sqlite_database_file(db_name, mysql_cursor, imported=False)
        shutil.move(imported_sqlite_db_file, sqlite_db_file)
        self._uio.info(f"Renamed {imported_sqlite_db_file} to {sqlite_db_file}")

    def _copy_mysql_to_sqlite_db(self, mysql_cursor, sqlite_db_file, batch_size=100000):
        """@brief Copy the contents of all the tables from the mysql db to the sqlite db.
           @param mysql_cursor The cursor for the mysql database.
           @param sqlite_db_file The sqlite DB to create.
           @param batch_size As the mysql tables may be quite large they are converted in chunks.
                  This is the chunk size in table records."""
        sqlite_conn = None
        sqlite_cursor = None
        try:
            sqlite_conn = sqlite3.connect(sqlite_db_file)
            sqlite_cursor = sqlite_conn.cursor()
            self._uio.info(f"Creating {sqlite_db_file} (sqlite) database file.")

            # Fetch MySQL table names
            mysql_cursor.execute("SHOW TABLES")
            tables = mysql_cursor.fetchall()

            mysql_cursor.execute("SELECT count(*) FROM CT6_SENSOR")
            columns = mysql_cursor.fetchall()

            for table_name in tables:
                table_name = table_name[0]
                self._uio.info(f"Processing table: {table_name}")

                # Get table structure from MySQL
                mysql_cursor.execute(f"DESCRIBE {table_name}")
                columns = mysql_cursor.fetchall()

                # Generate CREATE TABLE statement for SQLite
                column_definitions = []
                for col in columns:
                    col_name, col_type = col[0], col[1]
                    # Convert MySQL to SQLite types
                    if 'int' in col_type:
                        col_type = 'INTEGER'
                    elif 'varchar' in col_type or 'text' in col_type:
                        col_type = 'TEXT'
                    elif 'float' in col_type or 'double' in col_type:
                        col_type = 'REAL'
                    else:
                        col_type = 'TEXT'

                    column_definitions.append(f"{col_name} {col_type}")

                create_table_sql = f"CREATE TABLE IF NOT EXISTS {table_name} ({', '.join(column_definitions)});"
                sqlite_cursor.execute(create_table_sql)

                # Fetch data from MySQL and insert into SQLite using blocks
                mysql_cursor.execute(f"SELECT * FROM {table_name}")
                placeholders = ', '.join(['?'] * len(columns))

                total_rows = 0
                while True:
                    rows = mysql_cursor.fetchmany(batch_size)
                    if not rows:
                        break

                    sqlite_cursor.executemany(f"INSERT INTO {table_name} VALUES ({placeholders})", rows)
                    total_rows += len(rows)
                    self._uio.info(f"Inserted {total_rows} rows into {table_name}...")

                self._uio.info(f"Finished inserting {total_rows} rows into {table_name}")

            # Commit and close
            sqlite_conn.commit()
            self._uio.info("Conversion completed successfully.")

        finally:
            if sqlite_cursor:
                sqlite_cursor.close()
                sqlite_cursor = None
            if sqlite_conn:
                sqlite_conn.close()
                sqlite_conn = None

    def add_unit_name_column(self, sqlite_db, unit_name):
        """@brief Add a unit name column to the CT6_META table. The mysql database does not have
                  this column. Create this field in the sqlite database.
           @param sqlite_db The sqlite database file.
           @param unit_name The name of the CT6 device."""
        sqlite_conn = None
        sqlite_cursor = None
        try:
            sqlite_conn = sqlite3.connect(sqlite_db)
            sqlite_cursor = sqlite_conn.cursor()
            self._uio.info(f"Connected to SQLite: {sqlite_db}")

            # Step 1: Create a new table with the column at index 1
            sqlite_cursor.execute('''
            CREATE TABLE CT6_META_NEW (
                ID INTEGER PRIMARY KEY,
                HW_ASSY TEXT,
                UNIT_NAME TEXT,
                CT1_NAME TEXT,
                CT2_NAME TEXT,
                CT3_NAME TEXT,
                CT4_NAME TEXT,
                CT5_NAME TEXT,
                CT6_NAME TEXT
            )
            ''')

            # Step 2: Copy data, setting UNIT_NAME to NULL for now
            sqlite_cursor.execute('''
                INSERT INTO CT6_META_NEW (HW_ASSY, CT1_NAME, CT2_NAME, CT3_NAME, CT4_NAME, CT5_NAME, CT6_NAME)
                SELECT HW_ASSY, CT1_NAME, CT2_NAME, CT3_NAME, CT4_NAME, CT5_NAME, CT6_NAME FROM CT6_META
            ''')

            sqlite_cursor.execute(f"UPDATE CT6_META_NEW SET UNIT_NAME = '{unit_name}'")

            # Step 3: Optional - Drop the old table
            sqlite_cursor.execute('DROP TABLE CT6_META')

            # Step 4: Rename the new table to the original name
            sqlite_cursor.execute('ALTER TABLE CT6_META_NEW RENAME TO CT6_META')

            sqlite_conn.commit()

        except Exception:
            raise

        finally:
            if sqlite_cursor:
                sqlite_cursor.close()
            if sqlite_conn:
                sqlite_conn.close()

    def create_timestamp_index(self, sqlite_db_file, table_name):
        """@brief Create an index in the sqlite database on the TIMESTAMP column.
                  Most searches are based around timestamp so this should speed up these searches.
           @param sqlite_db The sqlite database file.
           @param table_name The name of the table to index.
           """
        sqlite_conn = None
        sqlite_cursor = None
        try:
            sqlite_conn = sqlite3.connect(sqlite_db_file)
            sqlite_cursor = sqlite_conn.cursor()
            self._uio.info(f"Indexing the {table_name} table in the {sqlite_db_file} database.")

            # Index on time stamp as most searches will be based around a date/time
            cmd = f"CREATE INDEX {table_name}_INDEX ON {table_name} ({SQLite3DBClient.TIMESTAMP})"
            sqlite_cursor.execute(cmd)

            sqlite_conn.commit()

        finally:
            if sqlite_cursor:
                sqlite_cursor.close()
            if sqlite_conn:
                sqlite_conn.close()

class AppServer(object):
    """@brief Responsible for
        - Starting the YViewCollector.
        - Storing data in the database.
        - Presenting the user with a web GUI to allow data to be displayed and manipulated."""

    DEFAULT_CONFIG_FILENAME = "ct6_app.cfg"
    LOCK_FILE_NAME = "ct6.lock"

    def __init__(self, uio, options, config):
        """@brief Constructor
           @param uio A UIO instance
           @param options The command line options instance
           @param config A ConfigBase instance."""
        self._uio = uio
        self._options = options
        self._config = config

    def _waitfor_sqlite_db(self):
        """@brief Block waiting for at least one sqlite database to be available."""
        db_storage_folder = self._config.getAttr(AppConfig.DB_STORAGE_PATH)
        while True:
            dbFileList = SQLite3DBClient.GetDBFileList(db_storage_folder)
            if len(dbFileList) > 0:
                break
            self._uio.info(f"Waiting for CT6 databases to appear in {db_storage_folder} before starting GUI.")
            sleep(10)

    def _startGUI(self, db_client):
        """@Start the App server running.
           @param db_client An instance of SQLite3DBClient."""
        try:
            # We block here waiting for CT6 db's to be created by the SQLite3DBClient thread.
            self._waitfor_sqlite_db()

            # If server login is enabled we pass the credentials file to the gui
            # This contains hashed credential details.
            loginEnabled = self._config.getAttr(ConfigBase.SERVER_LOGIN)
            if loginEnabled:
                credFile = CRED_JSON_FILE
            else:
                credFile = None
            gui = GUI(self._uio, self._options, self._config, credFile, db_client)
            openBrowser = not self._options.no_gui
            # Block waiting for at least one sqlite database to be available before starting the GUI.
            gui.runBlockingBokehServer(gui.getAppMethodDict(), openBrowser=openBrowser)

        finally:
# PJA no close() method exists !!!
            pass
#            self.close()

    def startPopulatingDatabase(self, db_client):
        """@brief Starts the threads that collect data from CT6 units and populate the sqlite database.
           @param db_client An instance of SQLite3DBClient."""
        # Start running the local collector in a separate thread
        self._localYViewCollector = LocalYViewCollector(self._uio, self._options)
        self._localYViewCollector.setValidProductIDList(YViewCollector.VALID_PRODUCT_ID_LIST)

        # Register the dBHandler as a listener for device data so that it can be
        # stored in the database.
        self._localYViewCollector.addDevListener(db_client)
        net_if = self._config.getAttr(AppConfig.CT6_DEVICE_DISCOVERY_INTERFACE)
        collector_thread = threading.Thread(target=self._localYViewCollector.start, args=(net_if,))
        collector_thread.daemon = True
        collector_thread.start()

    def start(self, db_client):
        """@Start the App server running.
            @param db_client An instance of SQLite3DBClient."""
        try:
            self.startPopulatingDatabase(db_client)

            # Start a web UI to allow the user to view the data
            self._startGUI(db_client)

        finally:
            db_client.disconnect()

# PJA TODO, auto restart threads if they crash
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

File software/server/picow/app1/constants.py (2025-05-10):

from lib.base_constants import BaseConstants

class Constants(BaseConstants):
    """@brief Define the constants used by this project.
              This extends BaseContants to make a more specialised configuration for this machine."""

    FIRMWARE_VERSION            = "3.1"

    # Override the BaseConstants GPIO pins to those connected on this hardware
    WIFI_SETUP_BUTTON_PIN       = 14
    BLUETOOTH_LED_PIN           = 15
    WIFI_LED_PIN                = 16
    POWER_CYCLE_GPIO            = 13
    DISPLAY_ON_GPIO             = 7

    VALID_CT_ID_LIST            = (1,2,3,4,5,6)

    TEMP_ADC_PIN                = 28        # The pin connected to the on board MCP9700 temperature sensor.
    ADC_CODES_TO_MV             = 19757.69  # Arrived at empirically by measuring the ADC voltage @ 24C
    MCP9700_VOUT_0C             = 0.5
    MCP9700_TC                  = 0.01

    ATM90E32_SPI_CLK_PIN        = 2         # The SPI clock pin used to communicate with all ATM90E32 devices
    ATM90E32_SPI_MOSI_PIN       = 3         # The SPI MOSI pin used to communicate with all ATM90E32 devices
    ATM90E32_SPI_MISO_PIN       = 4         # The SPI MISO pin used to communicate with all ATM90E32 devices
    ATM90E32_CS0_PIN            = 5         # The SPI chip select connected to the first ATM90E32 device.
    ATM90E32_CS4_PIN            = 22        # The SPI chip select connected to the second ATM90E32 device.
    ATM90E32_RESET_PIN          = 19        # The active low reset pin for both ATM90E32 devices.

    ATM90E32_PGA_GAIN           = 1

    NAME                        = "NAME"
    IRMS                        = "IRMS"
    IPEAK                       = "IPEAK"
    VRMS                        = "VRMS"
    PRMS                        = 'PRMS'
    PREACT                      = "PREACT"
    PAPPARENT                   = "PAPPARENT"
    PF                          = "PF"
    TEMP                        = "TEMP"
    FREQ                        = "FREQ"

    RSSI                        = "RSSI"
    BOARD_TEMPERATURE           = "BOARD_TEMPERATURE"
    # --- START CONFIG SECTION ---

    FIRMWARE_VERSION_STR        = "FIRMWARE_VERSION"

    CT1_IGAIN_KEY               = "CT1_IGAIN"
    CT2_IGAIN_KEY               = "CT2_IGAIN"
    CT3_IGAIN_KEY               = "CT3_IGAIN"
    CT4_IGAIN_KEY               = "CT4_IGAIN"
    CT5_IGAIN_KEY               = "CT5_IGAIN"
    CT6_IGAIN_KEY               = "CT6_IGAIN"

    CT1_IOFFSET_KEY             = "CT1_IOFFSET"
    CT2_IOFFSET_KEY             = "CT2_IOFFSET"
    CT3_IOFFSET_KEY             = "CT3_IOFFSET"
    CT4_IOFFSET_KEY             = "CT4_IOFFSET"
    CT5_IOFFSET_KEY             = "CT5_IOFFSET"
    CT6_IOFFSET_KEY             = "CT6_IOFFSET"

    CT1_TYPE_KEY                = "CT1_TYPE"
    CT2_TYPE_KEY                = "CT2_TYPE"
    CT3_TYPE_KEY                = "CT3_TYPE"
    CT4_TYPE_KEY                = "CT4_TYPE"
    CT5_TYPE_KEY                = "CT5_TYPE"
    CT6_TYPE_KEY                = "CT6_TYPE"

    CT1_NAME_KEY                = "CT1_NAME"
    CT2_NAME_KEY                = "CT2_NAME"
    CT3_NAME_KEY                = "CT3_NAME"
    CT4_NAME_KEY                = "CT4_NAME"
    CT5_NAME_KEY                = "CT5_NAME"
    CT6_NAME_KEY                = "CT6_NAME"

    CT1_KEY                     = "CT1"
    CT2_KEY                     = "CT2"
    CT3_KEY                     = "CT3"
    CT4_KEY                     = "CT4"
    CT5_KEY                     = "CT5"
    CT6_KEY                     = "CT6"

    CS0_VOLTAGE_GAIN_KEY        = "CS0_VOLTAGE_GAIN"
    CS4_VOLTAGE_GAIN_KEY        = "CS4_VOLTAGE_GAIN"

    ZERO_POWER_GATE_WATTS_KEY   = "ZERO_POWER_GATE_WATTS"

    TYPE_KEY                    = "TYPE"

    SCT013_100A_SENSOR_TYPE     = "SCT013_100A"

    LINE_FREQ_HZ_KEY            = "LINE_FREQ_HZ"

    READ_TIME_NS_KEY            = "READ_TIME_NS"

    RSSI_KEY                    = "RSSI"

    BOARD_TEMPERATURE_KEY       = "BOARD_TEMPERATURE"

    CS0_VOLTAGE_OFFSET          = "CS0_VOLTAGE_OFFSET"

    CS4_VOLTAGE_OFFSET          = "CS4_VOLTAGE_OFFSET"

    ACTIVE                      = "ACTIVE"

    MQTT_SERVER_ADDRESS         = "MQTT_SERVER_ADDRESS"

    MQTT_SERVER_PORT            = "MQTT_SERVER_PORT"

    MQTT_TX_PERIOD_MS           = "MQTT_TX_PERIOD_MS"

    MQTT_TOPIC                  = "MQTT_TOPIC"

    MQTT_USERNAME               = "MQTT_USERNAME"

    MQTT_PASSWORD               = "MQTT_PASSWORD"

    TIMESENT                    = "TIMESENT"

    PF_WATTS_THRESHOLD          = "PF_WATTS_THRESHOLD"

    FACTORY_CONFIG_KEYS = [BaseConstants.ASSY_KEY,

                           CS0_VOLTAGE_GAIN_KEY,
                           CS4_VOLTAGE_GAIN_KEY,

                           CT1_IGAIN_KEY,
                           CT2_IGAIN_KEY,
                           CT3_IGAIN_KEY,
                           CT4_IGAIN_KEY,
                           CT5_IGAIN_KEY,
                           CT6_IGAIN_KEY,
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

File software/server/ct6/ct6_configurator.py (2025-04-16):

#!/usr/bin/env python3

import sys
import argparse
import threading
import requests
import tempfile
import os
import shutil
import json

from p3lib.ngt import TabbedNiceGui, YesNoDialog

from p3lib.uio import UIO
from p3lib.helper import logTraceBack
from p3lib.pconfig import ConfigManager

from lib.bluetooth import CT6BlueTooth

from ct6.ct6_tool import YDevManager, getCT6ToolCmdOpts, CT6Config, MCULoader, CT6Base, CT6Scanner
from ct6.ct6_mfg_tool import FactorySetup, getFactorySetupCmdOpts

from nicegui import ui, app

class CT6GUIServer(TabbedNiceGui):
    """@brief Responsible for starting the CT6 configurator GUI."""
    PAGE_TITLE                  = "CT6 Configurator"
    DEFAULT_SERVER_ADDRESS      = "0.0.0.0"
    DEFAULT_SERVER_PORT         = 10000

    USB                         = "USB"
    BLUETOOTH                   = "Bluetooth"
    BT_MAC_ADDRESS              = "BT_MAC_ADDRESS"
    CT6_WIFI_SCAN_COMPLETE      = "CT6_WIFI_SCAN_COMPLETE"

    SET_CT6_IP_ADDRESS          = "SET_CT6_IP_ADDRESS"

    CFG_FILENAME                = ".CT6GUIServer.cfg"
    WIFI_SSID                   = "WIFI_SSID"
    WIFI_PASSWORD               = "WIFI_PASSWORD"
    DEVICE_ADDRESS              = "DEVICE_ADDRESS"
    USB_WIFI_SETUP_IF           = "USB_WIFI_SETUP_IF"
    DEFAULT_CONFIG              = {WIFI_SSID: "",
                                   WIFI_PASSWORD: "",
                                   DEVICE_ADDRESS: "",
                                   USB_WIFI_SETUP_IF: USB}

    UPDATE_PORT_NAMES           = "UPDATE_PORT_NAMES"
    CT1_NAME                    = "CT1_NAME"
    CT2_NAME                    = "CT2_NAME"
    CT3_NAME                    = "CT3_NAME"
    CT4_NAME                    = "CT4_NAME"
    CT5_NAME                    = "CT5_NAME"
    CT6_NAME                    = "CT6_NAME"
    PORT_NAMES_UPDATED          = "PORT_NAMES_UPDATED"
    DEV_NAME                    = "YDEV_UNIT_NAME"
    ACTIVE                      = "ACTIVE"
    MQTT_SERVER_ADDRESS         = "MQTT_SERVER_ADDRESS"
    MQTT_SERVER_PORT            = "MQTT_SERVER_PORT"
    MQTT_TX_PERIOD_MS           = "MQTT_TX_PERIOD_MS"
    DEFAULT_MQTT_SERVER_PORT    = 1883
    DEFAULT_MQTT_TX_PERIOD_MS   = 2000
    MQTT_TOPIC                  = "MQTT_TOPIC"
    MQTT_USERNAME               = "MQTT_USERNAME"
    MQTT_PASSWORD               = "MQTT_PASSWORD"
    UI_NOTIFY_MSG               = "UI_NOTIFY_MSG"

    MIN_CAL_CURRENT             = 1
    MAX_CAL_CURRENT             = 100

    LOGFILE_PREFIX              = "ct6_configurator"

    AC_LOAD_OFF_TO_GUI_CMD      = 1
    CURRENT_CAL_COMPLETE_TO_GUI_CMD = 2

    QUIT_THREAD_FROM_GUI_CMD    = 1
    AC_LOAD_OFF_FROM_GUI_CMD    = 2

    AC_CURRENT_FIELD            = "AC Current (Amps)"

    SSID                        = "SSID"
    RSSI                        = "RSSI"

    UPGRADE_CHECK               = "UPGRADE_CHECK"

    def __init__(self, uio, options):
        """@brief Constructor
           @param uio A UIO instance
           @param options The command line options instance."""
        super().__init__(uio.isDebugEnabled(), FactorySetup.LOG_PATH)
        self._uio                       = uio
        self._options                   = options
        self._svrAddress                = options.address
        self._svrPort                   = options.port

        self._wifiSSIDUSBInput          = None
        self._wifiPasswordUSBInput      = None
        self._setWiFiButton             = None
        self._log                       = None
        self._ct6IPAddressInput1        = None
        self._ct6IPAddressInput2        = None
        self._ct6DeviceList             = []
        self._dialogPrompt              = None
        self._dialogYesMethod           = None
        self._loadOffDialog             = None
        self._dialog2                   = None

        self._skipFactoryConfigRestore  = False
        if '--skip_factory_config_restore' in sys.argv:
            self._skipFactoryConfigRestore = True
            # We remove this arg as ct6_tool and ct6_mfg_tool do not know about this arg
            # and we may re run the cmd line args for each of these later.
            sys.argv.remove('--skip_factory_config_restore')

        self._cfgMgr                    = ConfigManager(self._uio, CT6GUIServer.CFG_FILENAME, CT6GUIServer.DEFAULT_CONFIG)
        self._loadConfig()

        self._logFile                   = os.path.join(self._logPath, CT6GUIServer.GetLogFileName(CT6GUIServer.LOGFILE_PREFIX))

        # Add msg to let the user know the log file for this session.
        self.info("Created " + self._logFile)

    def _setCT6IPAddress(self, address):
        """@brief Set the CT6 IP address.
                  This can be called from outside the GUI thread.
           @param msg The message to be displayed."""
        if address:
            msgDict = {CT6GUIServer.SET_CT6_IP_ADDRESS: address}
        else:
            msgDict = {CT6GUIServer.ERROR_MESSAGE: "CT6 device failed to connect to WiFi network."}
        self.updateGUI(msgDict)

    def _saveConfig(self):
        """@brief Save some parameters to a local config file."""
        self._cfgMgr.addAttr(CT6GUIServer.WIFI_SSID, self._wifiSSIDUSBInput.value)
        self._cfgMgr.addAttr(CT6GUIServer.WIFI_PASSWORD, self._wifiPasswordUSBInput.value)
        self._cfgMgr.addAttr(CT6GUIServer.DEVICE_ADDRESS, self._ct6IPAddressInput1.value)
        self._cfgMgr.addAttr(CT6GUIServer.USB_WIFI_SETUP_IF, self._wifi_setup_radio.value)
        self._cfgMgr.store()

    def close(self):
        """@brief Close down the app server."""
        ui.notify("Server shutting down. Close browser window (click x on browser tab).")
        try:
            app.shutdown()
        except AttributeError:
            pass


    def _loadConfig(self):
        """@brief Load the config from a config file."""
        try:
            self._cfgMgr.load()
        except:
            pass

    def _copyCT6Address(self, ipAddress):
        """@brief Copy same address to CT6 address on all tabs.
           @param ipAddress The IP address to copy to all tabs."""
        if self._ct6IPAddressInput1:
            self._ct6IPAddressInput1.value = ipAddress
        if self._ct6IPAddressInput2:
            self._ct6IPAddressInput2.value = ipAddress
        if self._ct6IPAddressInput3:
            self._ct6IPAddressInput3.value = ipAddress
        if self._ct6IPAddressInput4:
            self._ct6IPAddressInput4.value = ipAddress
        if self._ct6IPAddressInput5:
            self._ct6IPAddressInput5.value = ipAddress
        if self._ct6IPAddressInput6:
            self._ct6IPAddressInput6.value = ipAddress

    def _handleGUIUpdate(self, rxDict):
        """@brief Process the dicts received from the GUI message queue that were not
                  handled by the parent class instance.
           @param rxDict The dict received from the GUI message queue."""
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

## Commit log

2023-12-29 Make it clear the PSU that's required to power the CT6 unit.
2023-12-29 - Add a check that the CT6 unit has the Wifi SSID and passowrd reset at the end of the test and that the WiFi and bluetooth LED's both work. - Added ability to calibrate individual ports. This should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
    [ct6_mfg_tool.py]
2024-01-23 Add details of the ECO that can be applied to V1.6 and upwards PCB's to take them to V2.0
2024-01-23 Remove test parts from the git repo as these were created in order to itterate towards a useful case design.
    [test_box.FCStd, test_box.obj]
2024-01-23 Rather than using screws to attach the top to the case use a snap fit.
    [box.FCStd, box.obj, top.FCStd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]
2024-01-23 The display is a tight fit into the display holder. Increase the space for the display as previously it was difficult to get the display to fit in it's holder.
    [display_holder.FCStd, display_holder.obj]
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2024-01-24 - Bump firmware version to V2.5 - Add support for v2.1 boards to allow them to assert the reset pin on both ATM90E32 devices. - Add REST interface to turn WiFi and Bluetooth LED’s on/off. - Turn off 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
2024-01-24 - Bump debian package to V5.9 - Detail all the command line tools installed when the user installs the debian package.
    ct6_dash.py
    - Add < and > buttons next to the start/stop date/time fields to allow the user to easily inc/dec the date by one day.
    - Improve the accuracy of the day searches by setting the end of day microsecond value to 999999.
    - Ensure all buttons are disabled when an update is in progress and enabled again when complete.
    - Ensure the bokeh plot zoom is enabled by default to allow users to investigate the displayed power more easily.
    - Ensure the plot Y axis has the correct label.
    - Add error message if the start date/time is after the stop date/time.
    - Change message that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
    [ct6_dash.py, ct6_db_store.py, ct6_mfg_tool.py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]
2024-01-25 Update to the case to allow for a wider tolerance on the snap together parts.
    [box.FCStd, box.obj, display_holder.FCStd]
2024-01-27 Update case design to allow for easier printing and better fit.
    [box.FCStd, box.obj, button.FCStd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]
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2024-02-01 Update documentation WRT the USB cable used. The USB cable must have the +5v power lead disconnected. Usually the +5v power lead is red. This lead must be cut in the USB cable used so that the Pico W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
    If this is not cut then the testing will fail because the
    Pico W will not power cycle when the CT6 power turns off.
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2024-02-07 - Fix a few typos - Make it clear when local (not on CT6 unit) files are deleted. - Change the --clean option to wipe and reload all files except the factory.cfg file which must be reloaded manually.
    [ct6_tool.py]
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2024-02-07 - Change C2 from 220uf 50v to 470uf 35v. - Bumper schematic to v2.11
    This was changed because it was found that different Pico W's
    boards may draw significantly currents by a factory of between
    3 and 4. Pico W's that draw higher currents previously could
    cause a restart.
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2024-02-07 ECO 3 fixes the issue detailed in ECO 1
    'If the AC power is removed and reconnected within about 3 seconds on some
    boards prior to V2.1 the ATM90E32 devices did not reset correctly.
    If this occured then some channels (usually CT1 - CT3) did not
    read AC power.'
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2024-02-17 ct6_mfg_tool.py
    - Add -l/--labels option to allow the assembly and serial number labels to
    be updated. This may be useful if boards are modified to new assy versions.
    - Fix issue when using the -r/--restore option where the assy number label
    could be set to an assy number of ASY0197 (incorrect).
    ct6_tool.py
    - When using the --rp set the default local path to the temp folder.
    [ct6_mfg_tool.py, ct6_tool.py]
2024-02-18 - Change _setAssyNumber() to _updateAssyAndSN() and make checks that the factory.cfg file is present on the CT6 unit. - Remove setCT6SerialNumber() and _waitPingAble() - Add calibrateAndReboot method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
    [ct6_mfg_tool.py]
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2024-02-18 Add removable panel to allow access to the RPi Pico W serial port when the unit is assembled.
    [box.obj, box_serial_port_cover.FCStd, box_serial_port_cover.obj]
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2024-02-18 Give slightly more (0.2mm) clearance on the top.
    [top.FCStd, top.obj]
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2024-02-26 No longer test the reset switch as it is not exposed outside the case and therefore if the unit is tested with the case on it can't be pressed to check it. In future this may not be fitted.
    [ct6_mfg_tool.py]
2024-02-26 Add ability to jump back to calibrate the previous port. Useful if the wrong cal value was entered.
    [ct6_mfg_tool.py]
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2024-02-26 Update case to print using BambuLabs X1 Carbon printer.
    [box.obj, button.FCStd, button.obj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]
2024-02-28 Change to reduce the likleyhood of the cover dropping off.
    [box_serial_port_cover.FCStd, box_serial_port_cover.obj]
2024-02-28 Save the correct part to this obj file. Previously the serial port cover was saved to this file in error.
    [display_holder.obj]
2024-03-31 Add the ability to automatically reconnect with the database server should a connection to it drop. If an exception is thrown when adding data to the database we now disconnect from it and attempt to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
    Hopefully this will fix the ocasional crash of the ct6_db_store.py app.
    [ct6_db_store.py]
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2024-04-13 - Bump version to V7.1 - Fix memory leak in ct6_db_store.py that caused the app to crash after several weeks execution.
    [ct6_db_store.py]
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2024-05-06 Fixup pyflakes3 warning where an f string had no variables.
    [ct6_db_store.py]
2024-05-06 - Fix incorrect escape characters. - Fixup pyflakes3 warning where an f string had no variables.
    [ct6_tool.py]
2024-05-06 Partially complete Windows installer using NSIS (https://nsis.sourceforge.io/Download)
    [installer.cfg]
2024-05-12 A step closer having a windows installer for the ct6 tool.
    [installer.cfg]
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2024-05-12 Add the retries back when eraing and loading the flash as the commands fail occasionally.
    [ct6_mfg_tool.py]
2024-05-12 Skip the main.py file.Skip the main.py file.
    [installer.cfg]
2024-05-12 Change LED test as select doesn't work on Winodws with stdin.
    [ct6_mfg_tool.py]
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2024-05-13 nclude bat files for each python program.
    [installer.cfg]
2024-05-13 Add CT6 Shortcut placeholder for the tool to be developed to meet issue 5 requirements.
    [installer.cfg]
2024-05-28 Replace spaces with unerscores in MQTT address, topic, username and passwords
    [ct6_configurator.py]
2024-05-28 Fix bug getting MQTT server config from CT6 device.
    [ct6_configurator.py]
2024-05-28 Swap the tabs round to move the enable options to right hand tab.
    [ct6_configurator.py]
2024-05-28 Add workaround for https://github.com/micropython/micropython/issues/8326 This problem caused TCP connection that fail to block and the WDT would reset the CT6 device. The workaround ensures that the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
    [app.py, project.py]
2024-05-31 - Correct the destination path when installing on Windows platform - Change default install to fial if the factory config file cannot be read before install. This can be overriden with a cmd line arg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
    [installer.cfg]
2024-05-31 - Add '--skip_factory_config_restore' command line argument to overide the factory config restore. - Dont prompt the user to hold down the Pico W button after the flash has been erased. - Add a a 0.5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
    [ct6_configurator.py, ct6_mfg_tool.py, ct6_tool.py]
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2024-06-01 - Install the launcher for the ct6_configurator.
    [installer.cfg]
2024-06-02 Change ct6_app_server folder to server folder.
    [installer.cfg]
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2024-06-02 Change folder name as we will now have the installers folder.
    [installer.cfg]
2024-06-02 Add batch file to start ct6_dash_mgr
    [installer.cfg]
2024-06-03 Use relative paths for MCU code when upgrading on Windows platforms or the conversion to mpy files will fail.
    [ct6_tool.py]
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2024-06-08 Bump windows installer to V7.3
    [installer.cfg]
2024-06-09 Show obj instance counts only when in debug mode.
    This was used to track down memory leaks and should only
    be needed in debug mode.
    [ct6_db_store.py]
2024-06-09 Bump to 7.4
    [installer.cfg]
2024-06-09 Add details of the testing performed on this release.
    [testing_v7.4.ods]
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2024-06-10 Bump to V7.5
    [installer.cfg]
2024-06-10 - Add new 7.5 Linux installer. - Move testing to a single spreadsheet to cover all versions. Each sheet details the testing of one version.
    [testing.ods, testing_v7.4.ods]
2024-06-10 _info(), _debug() and _error() methods in MCULoader no longer required as they are implemented in CT6Base class.
    [ct6_tool.py]
2024-06-10 Update with V7.5 testing.
    [testing.ods]
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2024-06-22 Bump to V7.6
    [installer.cfg]
2024-06-22 Add details of the testing performed on V7.6
    [testing.ods]
2024-07-01 Bump windows installer to V7.7
    [installer.cfg]
2024-07-01 Detail the testing performed on V7.7.
    This is limited as the V7.6 - V7.7 change allows the ct6_configurator
    to work when no ~/.ssh/id_rsa file is present.
    [testing.ods]
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2024-07-07 Bump Linux and Windows installer config files to V7.8
    [installer.cfg]
2024-07-07 Update the testing record.
    [testing.ods]
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2024-07-12 ct6_configurator is now working on Linux. No ther testing completed yet.
    [testing.ods]
2024-07-12 Add installers folder
    [testing.ods]
2024-07-16 Update with changes required to use poetry rather than pipenv on a windows platform. Not yet tested on a Linux platform.
    [installer.cfg]
2024-07-17 Bump windows installer to V7.9
    [testing.ods]
2024-07-17 Update testing performed.
    [testing.ods]
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2024-07-20 Add pyflakes3 checks to the python wheel build process. If an issues is found the the python wheel will not be built.
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2024-07-20 Update V8.0 testing.
    [testing.ods]
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2024-09-01 - Fix spelling mistake. - If no factory.conf can be read from the CT6 device before wiping it and reinstalling it's firmware ensure a message is recorded that informs the user of this.
    [ct6_configurator.py]
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2024-09-04 Detail the testing performed on v8.1
    [testing.ods]
2024-09-05 Fix bug where login.html file could not be found.
    [ct6_dash.py]
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2024-09-07 Fix bug that stopped AC Voltage, AC Frequency, Temperature and WiFi RSSI being plotted if 5 out of the 6 sensors were in use.
    [ct6_dash.py]
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2024-10-05 Fix issue when running as root user under systemd where the bokeh_auth_attr_xxxxxx.json file can contain a /home/root/ path rather then /root/ which caused ct6_dash to fail to startup under systemd c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
    [ct6_dash_mgr.py]
2024-11-07 Updated testing document for V9.2 to indicate what tests were performed for Windows and Linux platforms.
    [testing.ods]
2025-02-05 If the connection to the WiFi network drops then power cycle CT6 unit. - lib/base_machine.py _updateWiFi() now returns True if WiFi is connected. - lib/wifi.py now has a connected() method. This retu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
    [constants.py, project.py]
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2025-02-12 Don't allow a failure to connect to the MQTT server to block (for ~ 4 seconds) sending stats in response to AYT messages.
    [project.py]
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2025-02-20 - ct6_mfg_test.py - When testing switches don't show the user serial port messages because it detracts from the instruction to press the WiFi button on the CT6 unit. - Fix error message when attempti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
    [ct6_mfg_tool.py, ct6_tool.py]
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2025-02-20 Add the V9.5 installer files and the testing details document.
    [testing.ods]
2025-02-21 - Bump CT6 server apps to V9.7 - Add Windows and Linux installers. - Update the testing doc with the testing performed.
    [testing.ods]
2025-02-23 - Add fix for CT6 stats averaging code. Thanks to Bryan Montgomery for his work in identifying and providing solutions to this issue.
    [constants.py, mean_stats.py, project.py]
2025-02-23 Add some pyunit tests on the codebase that will block the python wheel installer file being built if the y fail.
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2025-02-23 Fix a couple of issue caused by the NTP sync changing the MCU clock - The unit could reboot after the first NTP sync because the WDT could be fed a considerable time ago. Thefrefore we feed the WDT j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
    [constants.py, project.py]
2025-02-23 Add the V9.8 installers and testing document.
    [testing.ods]
2025-02-28 An issue with the power fctor measurements is that it is only valid and reports stange values when no current is detected. Therefore the PF_WATTS_THRESHOLD config attribute (default = 50) has been ad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
    This can be set from the REST interface if required,
    E.G http://<CT6 IP ADDRESS>/set_config?PF_WATTS_THRESHOLD=25 and
    is saved persistently.
    [cmd_handler.py, constants.py, project.py]
2025-02-28 - Bump to v9.9 - Update testing doc
    [testing.ods]
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2025-03-01 The recently added averaging code caused an issue where occasionally the display would not be updated. Fixed.
    [constants.py, mean_stats.py, project.py]
2025-03-01 Bump to v10.0
    [testing.ods]
2025-03-02 We still have a display update issue. Sometimes after a restart the display fails to update. Thius should fix the remaining issue.
    [project.py]
2025-03-02 Add v10.1 installers.
    [testing.ods]
2025-03-05 Bump to V10.2, update testing doc and add installers.
    [testing.ods]
2025-03-16 - !!!!!!!!!!!!!!!!!!!!!!!!!!!!!!!!!!!!!!!!!!!!!!!!!!!!!!!!!!!!!!!!!!!!!!!!! !!! Once this software is loaded ensure all CT ports are recalibrated !!! !!!!!!!!!!!!!!!!!!!!!!!!!!!!!!!!!!!!!!!!!!!!!!!!!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
    [constants.py]
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2025-03-18 - Add dialog to the upgrade process if the user is upgrading from < 2.8 CT6 firmware to >= CT6 firmware indicating that the user will need to recalibrate the CT6 ports for current and asking if they 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
    - Also ask if the user wishes to proceed if downgrading accross the V2.8 boundary.
    - Also ask the user if they wish to proceed if the new firmware version is the same
    as the old.
    - Correct some typo's
    [ct6_configurator.py, ct6_tool.py]
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2025-03-19 Updated testing of v10.3
    [testing.ods]
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2025-03-24 Fix typo. setValidProuctIDList -> setValidProductIDList
    [ct6_db_store.py, ct6_stats.py]
2025-03-24 Add some pyflakes3 fixups.
    [ct6_app.py]
2025-03-24 Ensure exceptions won't kill threads.
    [ct6_app.py]
2025-03-24 Fix typo and remove an invalid comment.
    [ct6_app.py]
2025-03-26 Set the GUI server port for ct6_app.py (sqlite db interface) to be the same as ct6_dash.py (mysql db interface) as the user probably won't run these concurrently. If they do then one of them can be c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
    [ct6_app.py]
2025-03-26 - Fix bug where inputBool should have been inputDecInt - Change SQLite table schema to make the table take up less space on disk. - Fix timestamp issue with nanosecond resolution.
    [ct6_app.py]
2025-03-27 When updating from a mysql database record the data as the upgrade is in progress so no data is missed.
    [ct6_app.py]
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2025-03-31 When the WiFi button is held down the default config is loaded. Previously this would reset the running app to app1. This could cause the running software version to revert to a previous version. Thi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
2025-03-31 - Fix bug: app config path incorrect if run as root user on a Linux platform.
    [ct6_app.py]
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2025-04-03 Fix timezone handling when selecting dates in the mysql dashboard and sqlite dashboard apps.
    [ct6_app.py, ct6_dash.py]
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2025-04-05 Add support for bluetooth error reporting.
    [ct6_configurator.py]
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2025-04-09 Add latest testing details.
    [testing.ods]
2025-04-14 Handle empty error when setting up bluetooth.
    [ct6_configurator.py]
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2025-04-15 Fix to ensure the scan times out when no CT6 devices are found.
    [ct6_tool.py]
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2025-04-17 Details the latest testing.
    [testing.ods]
2025-04-21 Remove dependancy on the retry module. The reason for this is that the retry module has a dependancy on the py module. The py module raised this security issue, https://github.com/pjaos/ct6_meter_os/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
    [ct6_mfg_tool.py]
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2025-04-21 Add v11.1 testing details.
    [testing.ods]
2025-04-21 Use p3lib.helper getProgramVersion() to get the program version. The previous code could pick the wrong pyproject.toml file and get the wrong program version.
    [ct6_tool.py]
2025-04-21 Add testing for v11.2
    [testing.ods]
2025-04-21 Add the PCB BOM to the git repo.
    [ct_meter_2.1_bom.csv]
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2025-04-26 Update testing doc.
    [testing.ods]
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2025-05-04 Update v11.5 testing.
    [testing.ods]
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2025-05-13 Update v11.6 testing.
    [testing.ods]
2025-05-19 Update to dashboards
    - Fix time selection issue caused by bug in bokeh's DatetimePicker widget.
    This involved
    - Adding separate date and time input fields for start and stop datetimes.
    - Move control panel to left hand side of plots.
    - Move ? buttons to the right hand side of the button groups.
    [ct6_app_gui.py, ct6_dash_gui.py, gui_base.py]
2025-05-19 pyflakes3 fixup for unused import.
    [gui_base.py]
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2025-05-19 Add v11.7 testing doc.
    [testing.ods]
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2025-10-03 Update with V11.8 testing.
    [testing.ods]
2026-06-14 Fix issue with later bokeh where the GUI table did not get updated when selecting a button, E.G Yesterday button.
    [gui_base.py]
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
